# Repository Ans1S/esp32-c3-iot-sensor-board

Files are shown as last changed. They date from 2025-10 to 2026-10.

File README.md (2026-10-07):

<div align="center">

# W-Charger

### Give a discarded vape battery a second life — as a useful, low-power sensor

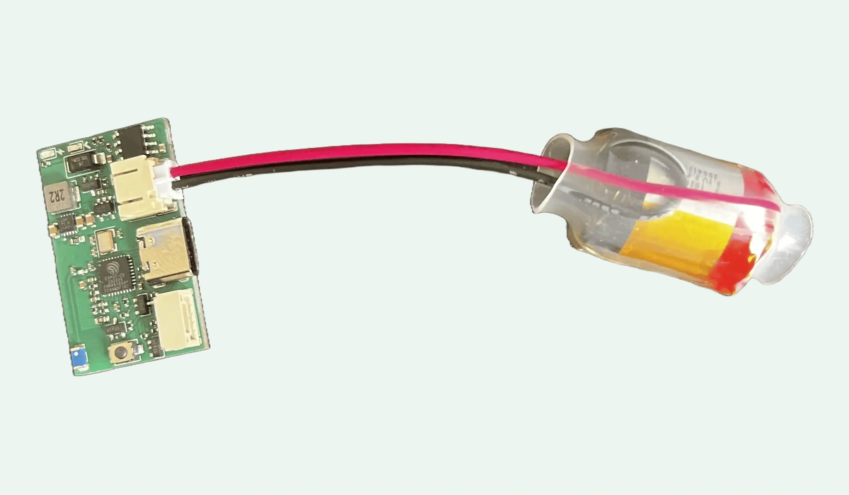
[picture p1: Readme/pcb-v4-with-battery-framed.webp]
W-Charger PCB V4 powered by a carefully recovered vape battery


<br>






**[Why it matters](#1--why-it-matters)** · **[Hardware](#2--hardware-built-for-a-second-life)** · **[Software](#3--software-that-removes-the-friction)**

</div>

Disposable vapes are designed for a very short life. The rechargeable lithium
cell inside them often is not. W-Charger turns suitable recovered cells into
the power source for compact wireless sensor nodes — then makes the whole
network easy to see, configure and update from one station.

| ♻️ Give energy another job | 🔋 Make every milliamp count | 📡 See every sensor in one place | 📦 Update without collecting devices |
|---|---|---|---|
| Reuse a carefully recovered cell instead of wasting its remaining potential. | Deep sleep and switchable hardware are designed for even small cells. | A friendly local dashboard shows live values and history. | Signed OTA updates travel from the station to sleeping sensor nodes. |

## 1 — Why it matters

### A battery should not become waste with the package around it

Many disposable vapes end up in household bins or as litter. That throws away
valuable materials, creates a fire risk in waste handling, and can release
harmful substances when a damaged cell reaches the environment. At the same
time, the product enclosure gives its rechargeable cell no practical second
life for the user.

W-Charger starts with a simple idea: **if a safe, undamaged cell can still store
energy, use that energy for something worthwhile.** A sensor node is a good
match. It needs little power, can spend most of its time asleep, and can turn a
cell that once powered a short-lived product into months of useful
measurements, depending on the cell, sensor and reporting interval.

<p align="center">
  A disposable vape becomes a recovered battery, then a low-power sensor and finally useful measurements in the W-Charger station
</p>

This project is not only a charger or a PCB. It is the complete path from a
recovered energy source to an approachable sensor network:

- a purpose-built ESP32-C3 sensor board;
- support for BME280, BME680, LSM6DSOX, TMP117 and MAX30102 sensors;
- a central ESP32-S3 station that discovers nodes automatically;
- a responsive local web interface for readings, history and configuration;
- signed over-the-air firmware updates for the sensor fleet.

> [!CAUTION]
> **Recovering lithium cells is not a beginner task.** Never use a swollen,
> punctured, corroded, hot, leaking or deeply discharged cell. Prevent short
> circuits, verify polarity and voltage before connection, and take questionable
> cells to an approved battery recycler. W-Charger is an experimental prototype,
> not a certified consumer product.

## 2 — Hardware built for a second life

### Two generations, one goal

PCB V3 proved the concept. PCB V4 is the current design and pushes the same idea
further: use more of the cell's available energy and waste less of it while the
sensor sleeps.

<table>
  <tr>
    <th align="center">PCB V3 · proven prototype</th>
    <th align="center">PCB V4 · current design</th>
  </tr>
  <tr>
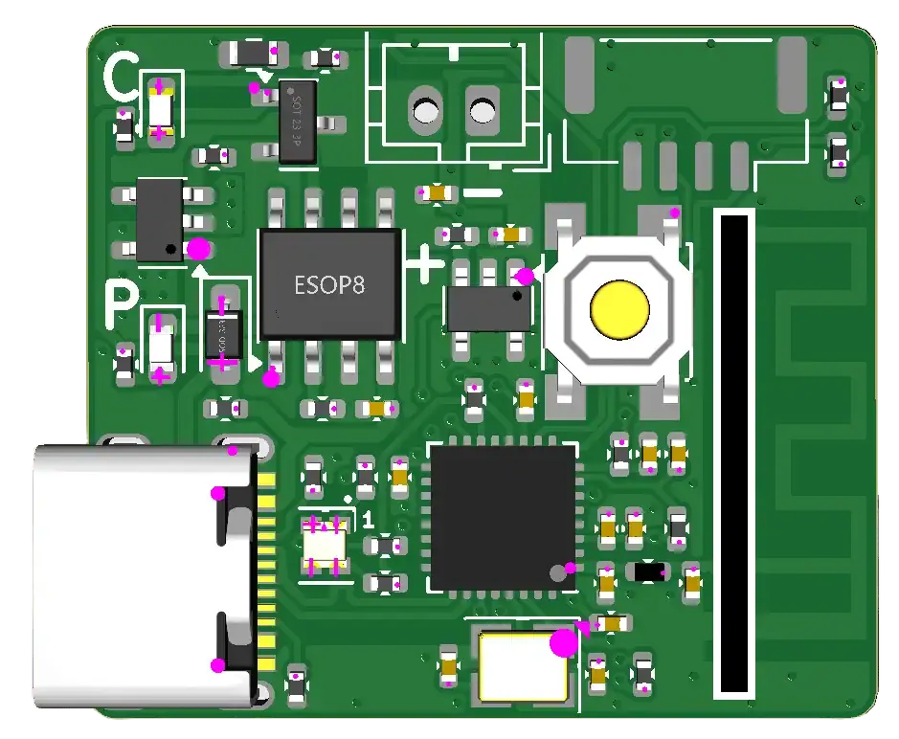
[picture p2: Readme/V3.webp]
Front render of W-Charger PCB V3
    <td align="center"></td>
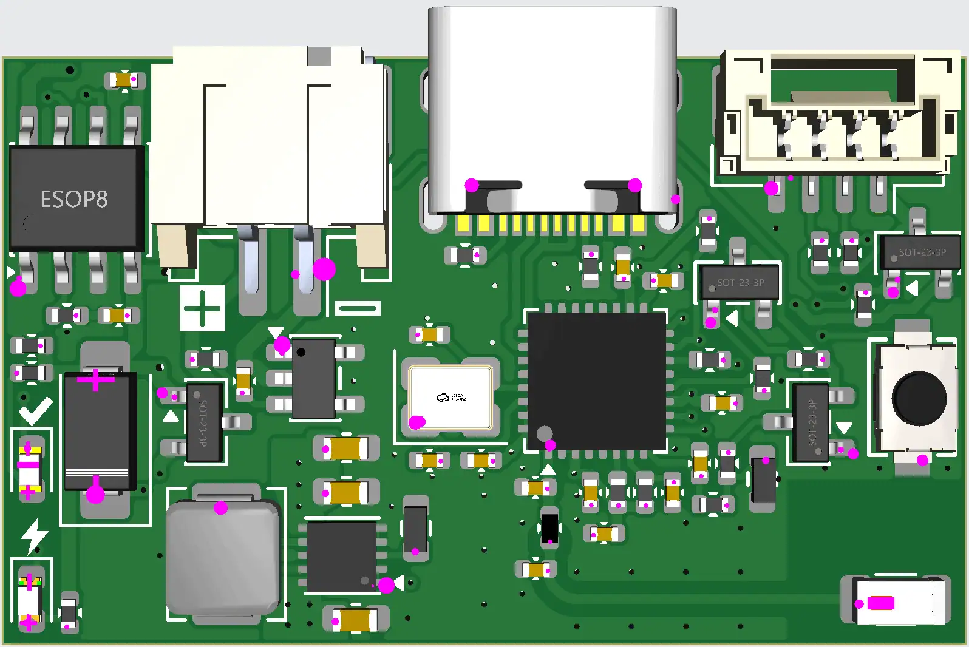
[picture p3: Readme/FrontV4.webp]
Front render of W-Charger PCB V4
    <td align="center"></td>
  </tr>
  <tr>
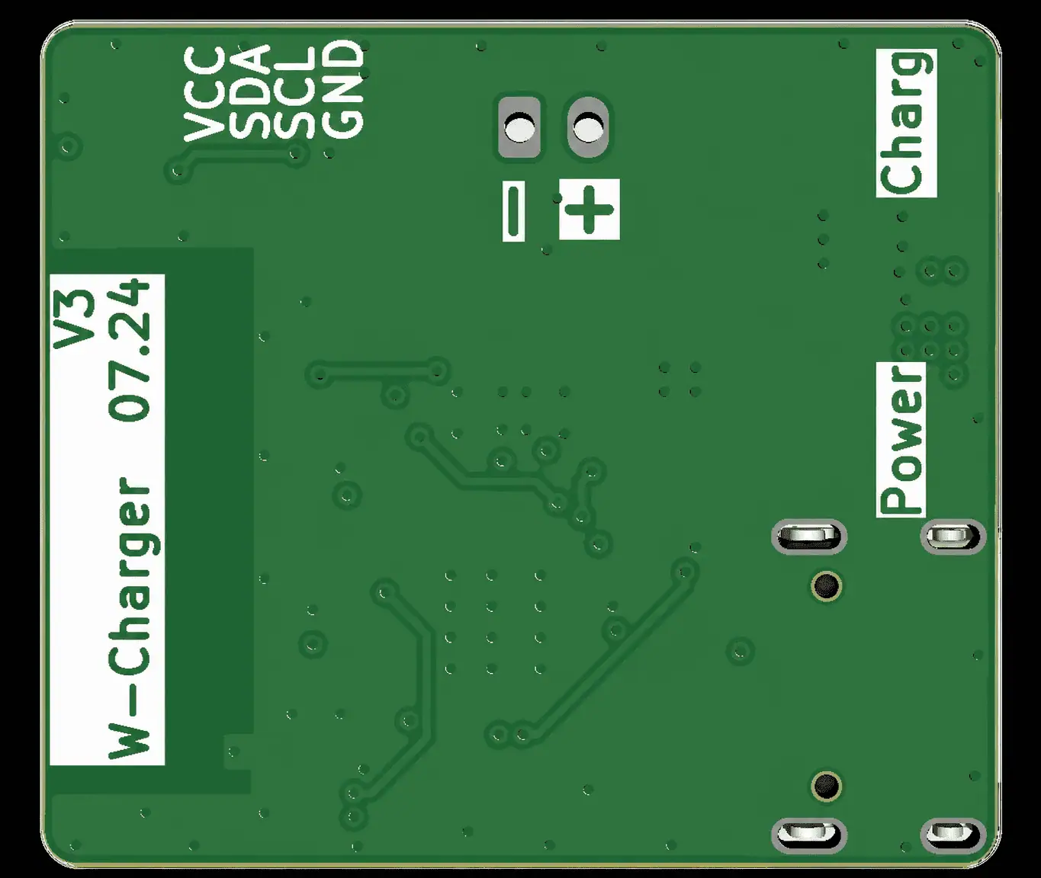
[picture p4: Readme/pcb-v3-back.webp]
Back render of W-Charger PCB V3
    <td align="center"></td>
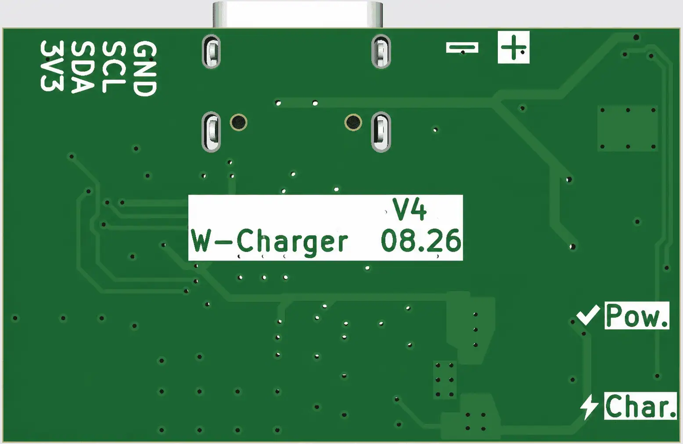
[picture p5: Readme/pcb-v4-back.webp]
Back render of W-Charger PCB V4
    <td align="center"></td>
  </tr>
</table>

| What changed | PCB V3 | **PCB V4** |
|---|---|---|
| Power delivery | Simple, dependable 3.3 V regulator | Buck-boost supply designed to use more of the cell's discharge range |
| Sleeping efficiently | The sensor rail can be switched | Sensor rail, I²C pull-ups and battery measurement are powered only when needed |
| Battery connection | Earlier upright connector layout | Low-profile side-entry connector |
| Charging feedback | Functional charging circuit | Revised layout with clearer power and charge indicators |
| Best fit | Existing builds and experiments | New builds and lowest-power development |

Both versions run the same sensor firmware, with a build profile that selects
the correct power behavior for the board. V4 remains a prototype and still
requires complete electrical, thermal, RF and long-term runtime validation.

### Connect the measurement your project needs

The board exposes one straightforward four-pin I²C connection. Today the
firmware supports:

| Sensor | What it adds | Typical behavior |
|---|---|---|
| **BME280** | Temperature, humidity and pressure | Wake, measure, report, sleep |
| **BME680** | Temperature, humidity, pressure, gas resistance and indoor-air-quality estimation | Ultra-low-power background learning with configurable reports |
| **LSM6DSOX** | Acceleration, angular rate and motion summaries | Continuous acquisition for motion projects |
| **No external sensor** | Battery-powered ESP32-C3 experimentation | A clean base for future extensions |

The hardware is intentionally open-ended: one compact node, different sensor
boards, and a growing firmware library instead of a separate product for every
measurement.

<table>
  <tr>
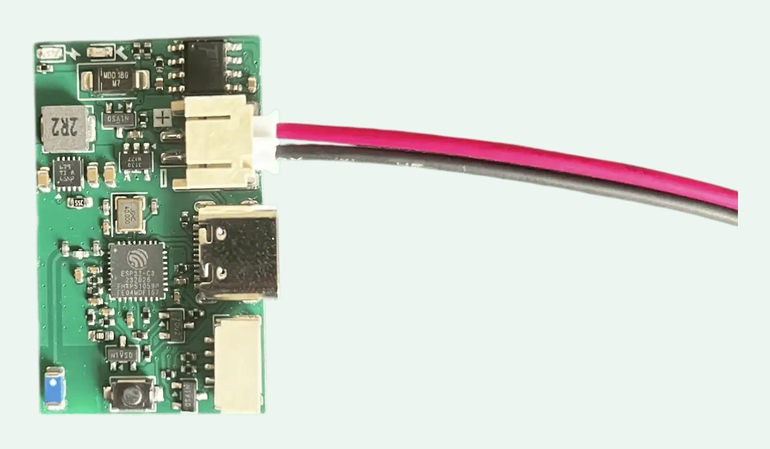
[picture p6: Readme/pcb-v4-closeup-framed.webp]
Assembled W-Charger PCB V4, cropped to remove empty margins
    <td width="50%" align="center" valign="top"><br><strong>Assembled PCB V4</strong></td>
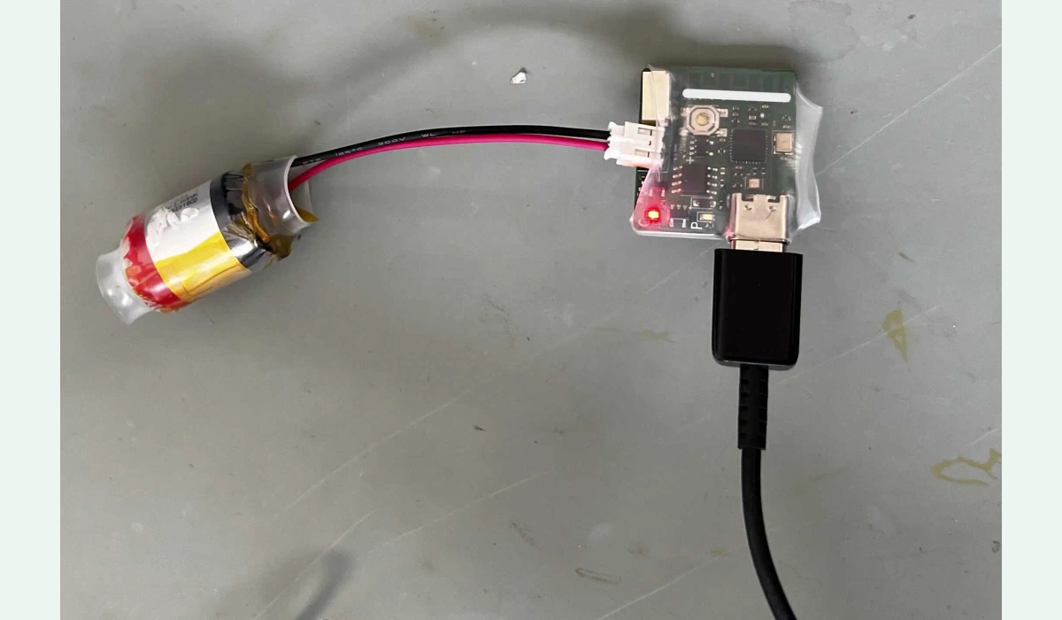
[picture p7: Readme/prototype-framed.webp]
W-Charger prototype with a recovered cell and USB cable
    <td width="50%" align="center" valign="top"><br><strong>Prototype with recovered cell</strong></td>
  </tr>
</table>

KiCad sources, BOMs and manufacturing files are available in [`PCB/`](PCB/).
The current V4 production package is under
[`PCB/Version 4/ESP32-C3-V4/production/`](PCB/Version%204/ESP32-C3-V4/production/).

## 3 — Software that removes the friction

### One station instead of a pile of USB cables

The station is the calm center of the system. Sensor nodes discover it over
ESP-NOW, send their readings, and return to their energy-saving routine. You
open one local website to see the whole network.

<p align="center">
  Several sensor nodes connect through ESP-NOW to one W-Charger station and its local web app
</p>

There is no receiver address or Wi-Fi channel to hard-code into every sensor.
The station can find new nodes, name them, select their attached sensor,
configure their measurement interval, keep local history, and optionally map
values to ThingSpeak.

### A dashboard made for people, not only developers

<p align="center">
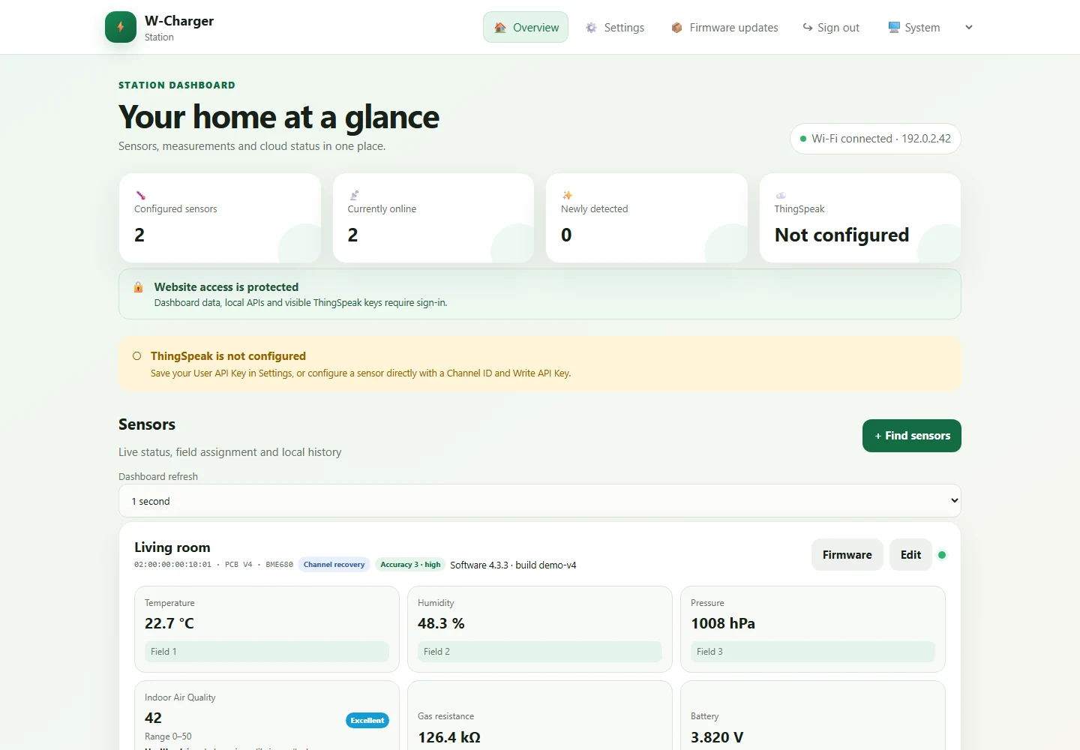
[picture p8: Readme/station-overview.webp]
Anonymized W-Charger station overview with two demo sensors and live values
  
  <br><sub>Live status, battery level, air quality, radio strength and local history. All names, addresses and identifiers shown are synthetic demo data.</sub>
</p>

Every sensor card adapts to the connected hardware. BME280 cards show
temperature, humidity, pressure and battery; BME680 adds indoor air quality and
gas resistance. Motion nodes expose XYZ acceleration and angular rate, TMP117
shows precise temperature, and MAX30102 shows an optical waveform and estimated
pulse during a manual recording. Measurement intervals and cloud mappings stay configurable
per sensor, while useful defaults keep setup short.

### Settings stay visible and understandable

<p align="center">
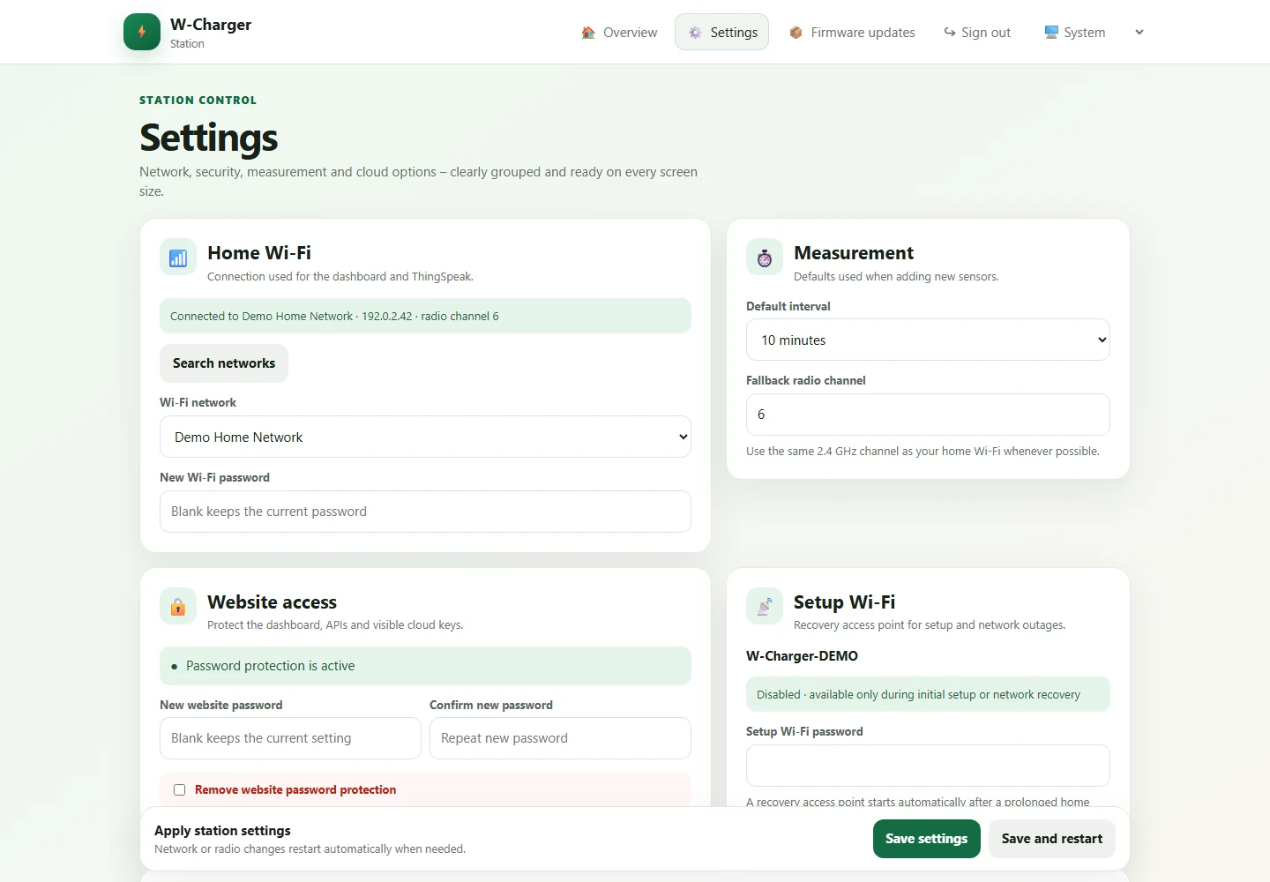
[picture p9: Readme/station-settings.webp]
Anonymized W-Charger settings page for Wi-Fi, measurement interval and protected website access
  
  <br><sub>Network, energy, access and cloud options are grouped in one responsive interface. Credentials are blank in this generated demo.</sub>
</p>

The dashboard works locally. ThingSpeak export is optional. Wi-Fi passwords,
website credentials and API keys are entered in the browser and stored on the
station — they are not compiled into the source code.

### OTA updates: improve sensors where they are

Once a sensor has its OTA-capable base firmware, routine updates no longer mean
finding every node, opening its enclosure and connecting it to a computer.
Upload a signed firmware package to the station, choose a sensor, and the
transfer continues automatically whenever that sleeping node checks in.

<p align="center">
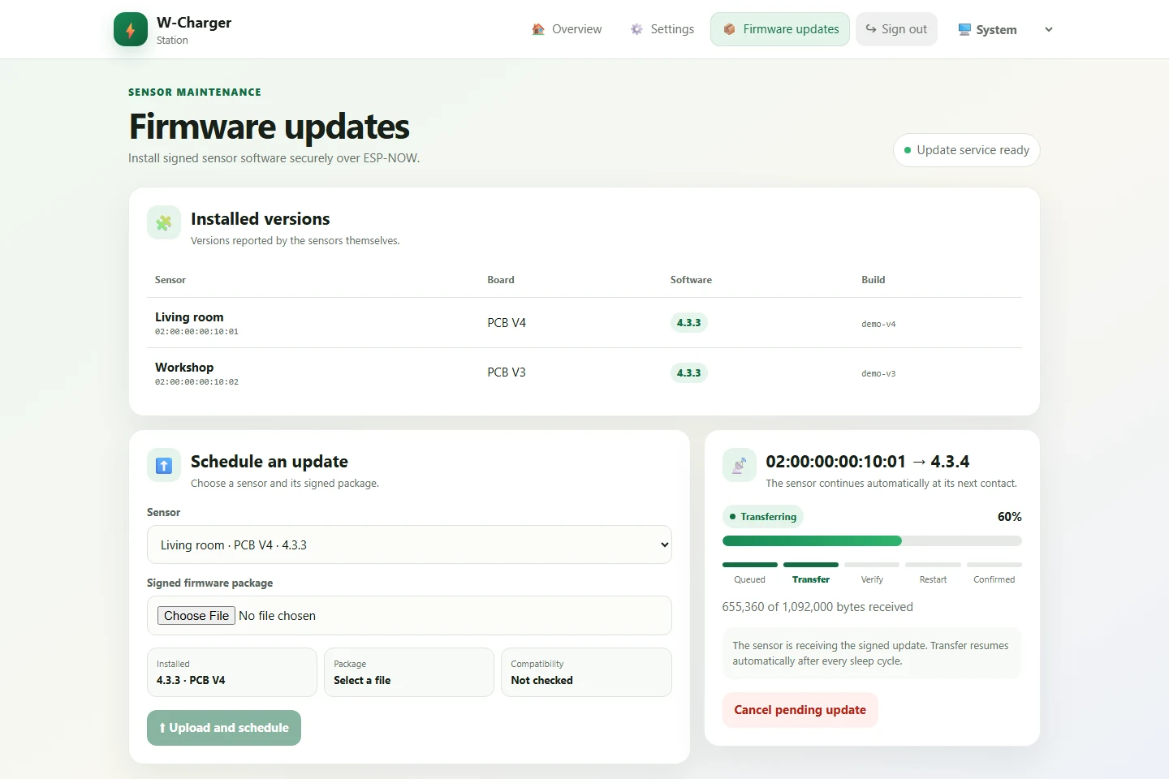
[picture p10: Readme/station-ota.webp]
Anonymized W-Charger firmware update page showing installed versions and an OTA transfer in progress
  
  <br><sub>The station checks board compatibility, tracks transfer progress and waits for the updated sensor to confirm a successful boot. Device addresses and build names are reserved demo values.</sub>
</p>

Interrupted transfers resume, low batteries can postpone an update, and the
previous image can be restored when a trial boot does not succeed. This turns a
collection of scattered devices into a sensor fleet that can keep improving.

### Firmware 4.3.4

The current release improves sensor recovery, BME680 state persistence,
MAX30102 signal handling, durable configuration/storage and station usability.
Saved recordings load as complete snapshots and stay readable during polling;
yellow setup notices disappear after five seconds. BME power-saving and the
PCB V4 daily battery-protection policy remain active.

- [Complete changes since firmware 4.3.1 and PR #30](Firmware/CHANGELOG.md)
- [PCB V3/V4 OTA packages and station application](Firmware/releases/README.md)
- [Publication/privacy review](Firmware/PUBLICATION_REVIEW.md)

### From clone to first measurement

You need VS Code with PlatformIO (or PlatformIO Core), Python, Git, a USB data
cable and one connected board at a time.

```bash
python Firmware/upload.py
```

The upload helper offers the station, PCB V3 sensor and PCB V4 sensor as clear
choices and uses the matching build automatically. Direct commands are also
available:

```bash
python Firmware/upload.py station
python Firmware/upload.py sensor-v4
# For an existing V3 board:
python Firmware/upload.py sensor-v3
```

Then:

1. Flash the ESP32-S3 station and join its `W-Charger-XXXXXX` setup network.
2. Follow the browser wizard to choose Wi-Fi, a sensible default interval and an optional website password.
3. Flash and power a matching sensor board.
4. Open **Find sensors**, give the node a name, choose its attached sensor and save.
5. From then on, use the station dashboard for readings, configuration and signed sensor updates.

> [!IMPORTANT]
> Normal station USB updates preserve saved settings, pairing and archives.
> Only the explicit `station_s3_factory_reset` upload erases the complete flash.
> Older recording layouts require the documented one-time USB migration. Disconnect a recovered battery before the first USB upload and
> confirm whether the connected sensor PCB is V3 or V4.

<details>
<summary><strong>What the software already handles</strong></summary>

- Automatic station and Wi-Fi-channel discovery across all 13 ESP-NOW channels.
- Board-specific power control for PCB V3 and V4 from one sensor codebase.
- Energy-saving deep sleep for environmental sensors.
- BME680 operation with Bosch BSEC2 in ultra-low-power mode.
- Rolling local history and CSV export.
- Optional ThingSpeak channel management and field mapping.
- Responsive light, dark and system themes.
- Signed, resumable ESP-NOW OTA with compatibility checks and boot confirmation.

</details>

<details>
<summary><strong>Repository map and technical documentation</strong></summary>

```text
.
├── Firmware/
│   ├── station/        # ESP32-S3 station and local web app
│   ├── sensor/         # ESP32-C3 firmware for PCB V3 and V4
│   └── shared/         # Shared protocol and OTA components
├── PCB/
│   ├── Version 1–3/    # Earlier hardware revisions
│   └── Version 4/      # Current KiCad and production files
└── Readme/             # Documentation graphics and reproducible UI images
```

- [Firmware overview](Firmware/README.md)
- [Station behavior and security model](Firmware/station/README.md)
- [Sensor behavior and hardware profiles](Firmware/sensor/README.md)
- [OTA setup, signing and recovery](Firmware/OTA.md)
- [Power-management design](Firmware/POWER_MANAGEMENT.md)
- [System architecture](Firmware/ARCHITECTURE.md)
- [Hardware test plan](Firmware/HARDWARE_TESTPLAN.md)
- [LSM6DSOX motion guide](Firmware/LSM6DSOX.md)
- [Precision sensor operation and recordings](Firmware/PRECISION_SENSORS.md)
- [Regression tests](Firmware/tests/README.md)

The screenshots in this README are generated from the real embedded pages with
deterministic, anonymized fixtures. Rebuild them with
`node Readme/generate-ui-screenshots.cjs`; set `CODEX_NODE_MODULES` if
Playwright and Sharp are installed outside the default development runtime.

</details>

### Security, privacy and project status

The dashboard is intended for a trusted home network. Website access can be
password protected, but the local UI uses HTTP; ThingSpeak requests use HTTPS.
ESP-NOW packets currently include versioning, length checks and CRC32, but not
per-device cryptographic authentication. Treat the system as a prototype, not
as a security boundary.

Before publishing, run `python Firmware/tools/check_publication.py` and enable
`git config core.hooksPath .githooks`. The hooks inspect staged/pushed blobs,
including firmware and ZIP contents, without printing detected secret values.
Local signing keys, device data and agent instructions stay ignored. The
[publication review](Firmware/PUBLICATION_REVIEW.md) distinguishes the cleaned
current tree from historical exposures already present in older commits.

Current firmware targets are `station_s3`, `sensor_pcb_v3` and
`sensor_pcb_v4`. Project-owned firmware and hardware sources are released under
the [MIT License](LICENSE). The optional BME680 path downloads Bosch BSEC2
during the build and remains subject to Bosch's separate license.

<div align="center">

**A short-lived product can still become a long-lived tool.**

</div>

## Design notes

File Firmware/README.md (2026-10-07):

# W-Charger Firmware

This directory contains the only maintained firmware in this repository. The
station and both sensor-board revisions share the version 5 ESP-NOW protocol;
retired experiments are intentionally excluded from Git.

```text
Firmware/
â”œâ”€â”€ shared/   versioned ESP-NOW protocol
â”œâ”€â”€ station/  ESP32-S3 home station
â””â”€â”€ sensor/   ESP32-C3 sensor firmware for PCB V3 and V4
```

The station and sensor are independent PlatformIO projects. Flash the station
first, then the sensor target matching PCB V3 or V4. One sensor codebase
supports BME280, BME680, LSM6DSOX, TMP117, MAX30102 and battery-only nodes; the attached
sensor is selected in the station UI rather than compiled into a separate
image. Configure Wi-Fi, reporting intervals, sensor calibration and optional
ThingSpeak integration only through the station UI. Never add credentials to
source files.

For the shortest upload path, run `python Firmware/upload.py` from the
repository root and select the connected board. Pass `station`, `sensor-v3` or
`sensor-v4` directly to make the command non-interactive. Add `--build-only` to
verify a target without writing to a connected device.

- [Station](station/README.md)
- [Sensor](sensor/README.md)
- [Architecture](ARCHITECTURE.md)
- [Hardware test plan](HARDWARE_TESTPLAN.md)

Current firmware: **4.3.4**. Initialize the installation signing key as described
in the OTA guide before the first build. Never replace an existing signing key.

- [Signed OTA updates](OTA.md)
- [Latest local packages](releases/README.md)
- [LSM6DSOX motion acquisition](LSM6DSOX.md)
- [Power management](POWER_MANAGEMENT.md)
- [Regression checks](tests/README.md)
- [Manual recordings and USB migration](RECORDINGS.md)
- [Sensor accuracy review and V4 battery protection](SENSOR_REVIEW.md)
- [Station and sensor V3/V4 reliability review](RELIABILITY_REVIEW.md)

## Live precision sensors

TMP117 and LSM6DSOX take fresh normal measurements at the configured interval
with the external rail off between windows. MAX30102 starts through SW2 only.
SW2 / GPIO9 starts/stops a separate fast recording: 1 s TMP117 values, 200 ms
optical waveform packets, or 50 ms IMU means for five minutes and 100 ms afterward.
Pulse estimates update once per second. Saved recordings load as complete,
stable snapshots; full-session CSV retains the original samples. See [operation, accuracy limits and OTA migration](PRECISION_SENSORS.md).

## Current release and publication checks

Firmware **4.3.4 / 40307** includes bounded sensor reinitialization, durable
settings/history corrections and the updated recording/dashboard behavior.
See [the complete change inventory](CHANGELOG.md),
[release artifacts](releases/README.md) and
[publication review](PUBLICATION_REVIEW.md). Build diagnostics use relative
paths; installation keys and device data must stay local. Software tests do not
replace physical accuracy, rail-voltage and sleep-current acceptance.

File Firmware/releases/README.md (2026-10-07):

# Firmware 4.3.4

The current release is **4.3.4**, internal release **40307**, for protocol V5.

| File | Target | Use |
| --- | --- | --- |
| [sensor-v3-4.3.4.ota](sensor-v3-4.3.4.ota) | Sensor PCB V3 | Signed OTA through the station |
| [sensor-v4-4.3.4.ota](sensor-v4-4.3.4.ota) | Sensor PCB V4 | Signed OTA through the station |
| [station-4.3.4.bin](station-4.3.4.bin) | ESP32-S3 station | Application-only USB image at `0x10000` |

The release includes bounded sensor reinitialization, BME680 learning-state
persistence, MAX30102 weak-signal/independent LED control, durable settings and
archive fixes, stable complete saved graphs, timed setup notices and correct
BME280 tiles. Read [the full change inventory](../CHANGELOG.md) for the main
improvements and every additional correction since 4.3.1 and PR #30.

## Installation

Update the station for UI/storage changes and sensor nodes for driver/recovery
changes. To build and upload the station normally, run from the repository root:

```sh
python Firmware/upload.py station
```

Normal station uploads preserve settings, identities and recording archives.
The supplied station BIN contains only the application. It must not be flashed
at `0x0`, uploaded as a sensor OTA package or mistaken for a factory image.
On an existing compatible layout, write it at `0x10000` without erasing flash.
Only the explicit factory-reset environment intentionally erases the device.

Upload the matching V3/V4 `.ota` on the station's **Firmware updates** page.
Existing 4.3.1/4.3.2/4.3.3 installations with this trusted signing identity and
recording layout can use it. Same-version OTA is rejected; rebuilding 4.3.4
with sanitized compiler paths does not change its release integer. Older
layouts still need the [one-time USB migration](../RECORDINGS.md#one-time-usb-migration).
The recording partition layout and low-power policies remain unchanged.

## Integrity and publication

[SHA256SUMS.txt](SHA256SUMS.txt) covers all three files. V3/V4 signatures,
embedded PCB/protocol/version identities and payloads match the final builds
and the existing installation's public key. That private key and the local
public header are never uploaded. Firmware intentionally contains the public
verification key; that is not private key material.

New builds remap personal compiler paths before compilation. The publication
checker inspects firmware bytes, source text and ZIP contents with redacted
findings. Earlier distribution binaries were removed from this current tree
because they carried local build paths; retained local copies are ignored.
Their previously published Git objects are still present in history. See
[the publication review](../PUBLICATION_REVIEW.md) for this limitation.

This directory supplies only the current packages, not flash dumps or factory
images. The unpublished 4.3.2/4.3.3 intermediate packages are superseded by 4.3.4.
Historical 4.3.1 behavior and validation are documented in
[PR #30](https://github.com/Ans1S/esp32-c3-iot-sensor-board/pull/30).

## Validation and licenses

All three PlatformIO targets, 22 production C++ suites, six embedded browser
suites, six cryptographic OTA package tests, two upload tests, three pinned
library-patch checks and publication regressions pass. Eight station script
blocks parse. No hardware was flashed or measured. Accuracy, RF/power-loss,
rollback behavior, rail discharge and current acceptance remain separate work;
see [tests](../tests/README.md) and [the reliability review](../RELIABILITY_REVIEW.md).

BME680 firmware includes Bosch BSEC2 binaries under their separate
[license terms](https://github.com/boschsensortec/Bosch-BSEC2-Library/blob/4f559a6aa450f0ce436e602b42dc384f52128c66/LICENSE.md).
The repository license does not relicense third-party components. Review the
applicable terms before redistributing compiled packages.

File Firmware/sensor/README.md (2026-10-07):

# W-Charger Sensor Firmware

Firmware 4.3.4 supports LSM6DSOX, TMP117 and MAX30102 live acquisition on PCB V3/V4.
See [precision sensor operation and timing](../PRECISION_SENSORS.md).

One shared firmware codebase supports PCB V3 and V4. The only differences are
the build environment and the `hardware_profile`.

```text
pio run -e sensor_pcb_v3 -t upload   # existing test board
pio run -e sensor_pcb_v4 -t upload   # current board
```

No Wi-Fi credentials, station MAC address, radio channel or measurement
interval must be written into the source code. A new sensor scans all 13
ESP-NOW channels for the station. During the initial ten-minute pairing window,
it repeats this complete broadcast scan every ten seconds. This continues until
the sensor is actually added in the dashboard (`provisioned=true`); a station
response alone does not end discovery mode. After it is added, the sensor
stores the station MAC address and channel in NVS and normally starts each
future exchange on that saved channel. After the initial ten-minute window, an
unprovisioned sensor sleeps for five minutes between discovery attempts but
still scans all 13 channels on every attempt. A short randomized radio delay is
used only during discovery so that sensors powered together do not repeatedly
collide.

Firmware changes are identified by the ELF SHA fingerprint. A new image
invalidates the RTC configuration cache but preserves station assignment and
compatible calibration data in NVS. Use an explicit factory reset to clear
pairing. Signed firmware updates can now be uploaded through the station;
see [the OTA guide](../OTA.md) for initial USB installation and recovery.
For each scheduled transmission, the sensor first tries the known
channel twice. A newly paired sensor retains a commissioning recovery guard: if
the saved setup-AP channel stops responding, it scans all 12 other channels in
the same wake. This guarantees recovery when the station joins the configured
home Wi-Fi network and its radio moves to that network's channel. Once a new
channel is found, later stale-channel events test at most three other channels
per scheduled report, with one maximum-power attempt each, and continue from a
retained RTC cursor. This bounds steady-state failure energy without adding a
separate retry wake. A one-time sub-second offset in the first deep-sleep
interval staggers paired nodes without keeping their radios active. Both PCB
targets run the CPU at 80 MHz, the lowest supported maximum frequency while
ESP-NOW keeps the 80 MHz APB clock available.

The operating modes are intentionally mutually exclusive. Energy-saving mode
requires all three persisted facts: `provisioned=true`, a valid station MAC and
a valid saved channel. In that mode the sensor uses its configured measurement
interval, addresses only the station and starts on the saved channel. If any
part of the assignment is absent, or the station returns `provisioned=false`
after deletion, the sensor clears the station identity and enters discovery
mode with broadcast traffic and complete channel scans.

| Scenario | Selected mode | Radio and wake behaviour |
|---|---|---|
| Fresh flash, erased NVS or factory reset | Discovery | All 13 channels; 10-second then 5-minute sleep |
| Deleted by the station and deletion response received | Discovery | Station identity cleared; all-channel broadcast resumes |
| Incomplete or invalid persisted assignment | Discovery | Safe fallback; energy-saving mode is rejected |
| Fully provisioned BME280 or no environmental sensor | Energy saving | Configured interval; saved-channel unicast only while communication succeeds |
| Fully provisioned BME680 | Energy saving | Five-minute BSEC ULP wake; radio only at the configured report interval |
| Saved station channel no longer responds | Recovery | Bounded recovery, except the protected setup-AP transition |

The sensor type is no longer compiled into a separate firmware image. When a
sensor is added or edited on the station, select **Automatic**, **BME280**,
**BME680**, **LSM6DSOX** or **No environmental sensor**. The selection and BME680 temperature
correction are transferred with the next ESP-NOW response. Automatic mode
checks the Bosch chip IDs at `0x76` and `0x77`, then the LSM6DSOX
at `0x6A` and `0x6B`.

A normal BME280 cycle performs only these steps:

1. On V4, settle and read the battery divider before enabling the sensor.
   Below 2.8 V (or on an invalid ADC reading), send only battery status and
   deep-sleep for 24 hours. Resume at 2.95 V. V3 retains overlapping ADC settling.
2. Read the BME280 with checked I2C transfers, one forced x1 T/P/H conversion
   and a coherent data burst. Bosch/automatic startup uses 100 kHz I2C.
3. Send a validated telemetry packet over ESP-NOW.
4. Wait briefly for the station's configuration response.
5. Write the new configuration to NVS only when its revision has changed.
6. Safely disable the sensor and ADC paths and enter deep sleep.

The V4 policy also applies before discovery/BME680 maintenance and checks live
sessions every ten seconds. The station displays an explicit battery-protection
state. See [sensor and low-voltage review](../SENSOR_REVIEW.md) for register
checks, recovery behavior, limitations and the hardware acceptance procedure.

The BME280 configuration deliberately follows Bosch's energy-efficient weather
monitoring profile: forced mode, 1x oversampling for temperature, pressure and
humidity, and no IIR filter. Higher oversampling adds little practical value to
slow-changing indoor measurements but increases measurement and active time.
The station therefore wakes this sensor type only at the selected reporting
interval.

## Hardware profiles

| Function | PCB V3 | PCB V4 |
|---|---:|---:|
| ADC | GPIO3 | GPIO3 |
| ADC enable | always active | GPIO6, active high |
| Sensor power | GPIO10, active high | GPIO10, PMOS active low |
| I2C SDA / SCL | GPIO5 / GPIO4 | GPIO5 / GPIO4 |
| Battery scaling | field-validated software factor 1.67 | 100 kOhm / 150 kOhm, factor 1.667 |

The station can logically restore a sensor to factory settings on its next
contact. The web interface allows integer-second intervals from one second to 24 hours,
covering both short tests and energy-efficient long-term operation.

## BME680 and indoor air quality

The BME680 runs Bosch's BSEC2 algorithm and uses **Static IAQ** for a stationary
indoor device. An index calculated independently from gas resistance would not
be equivalent: humidity compensation, sensor ageing, drift and the adaptive
baseline are part of the algorithm. The index ranges from 0 (clean air) to 500
(heavily polluted), and the associated accuracy from 0 to 3 appears directly
in the dashboard. While accuracy is 0, the dashboard displays "calibrating"
and the station does not send IAQ to ThingSpeak. Temperature, humidity,
pressure and gas resistance remain available.

Commissioning and long-term operation deliberately use the same routine:

- `BSEC_SAMPLE_RATE_ULP` is the only mode used from the first start throughout
  the device's lifetime, with exactly one internal BME680 measurement every
  five minutes;
- while the BME680 completes its forced TPH/heater conversion, the ESP32-C3
  uses timer Light-sleep with the switched sensor rail latched at its active
  level; a failed Light-sleep setup falls back to the original timed delay;
- there is no switch between LP and ULP, avoiding a jump in the learned BSEC
  baseline caused by an operating-mode change;
- sensor power is off and the ESP32-C3 is in deep sleep between measurements;
- radio transmission and ThingSpeak strictly follow the configured reporting
  interval, such as 10, 30 or 60 minutes;
- the logical reporting clock includes both deep-sleep and awake time, so a
  report is not delayed by another five-minute BME680 cycle;
- BSEC state and logical time remain in RTC RAM; a flash checkpoint is written
  when accuracy improves and then no more than once every six hours;
- after a battery replacement, the latest flash state is restored instead of
  losing the adaptive baseline completely.

The firmware loads only Bosch's ULP configuration blob intended for a 3.3 V
sensor supply. The direct Bosch sensor API remains an availability fallback for
temperature, humidity, pressure and raw gas resistance. It intentionally does
**not** generate a substitute IAQ value: only a Static IAQ value actually
provided by BSEC is marked or uploaded as IAQ.

The I2C sensor power rail is **fully switched off on PCB V3 and V4**. The BME680
itself retains no state while unpowered. It is therefore reinitialized after
every wake-up, while the previously serialized BSEC learning state and a
continuous logical time are saved before shutdown and restored on the next
start. This follows Bosch's intended `getState()`/`setState()` flow for complete
system shutdowns.

Initial learning remains active while BSEC Accuracy is 0 and ends permanently
after Accuracy first reaches 1. Its duration depends on the observed air
conditions and is therefore not represented by a fixed countdown. BSEC
continues learning the gas/IAQ path in normal operation and can improve through
Accuracy 2 to 3. There is no separate fast-start mode with increased heater or
radio load.

When BME680 is selected explicitly, the reporting interval must be five minutes
or a multiple of five minutes. The default temperature offset of `0.466 degC`
comes from Bosch's ULP example and can be adjusted on the station for each
installation. It should be changed only after comparison in an enclosure that
has reached thermal equilibrium.

The implementation is based on Bosch's official
[BME68x Sensor API](https://github.com/boschsensortec/BME68x_SensorAPI),
[BME68x Arduino library](https://github.com/boschsensortec/Bosch-BME68x-Library)
and [BSEC2](https://github.com/boschsensortec/Bosch-BSEC2-Library). The BME680
limits, IAQ scale and ULP power figures are documented in the
[BME680 data sheet](https://www.bosch-sensortec.com/media/boschsensortec/downloads/datasheets/bst-bme680-ds001.pdf).
BSEC2 contains a proprietary binary library; use and redistribution are also
subject to the [Bosch BSEC license](https://github.com/boschsensortec/Bosch-BSEC2-Library/blob/master/LICENSE.md).

During a build, the pinned BSEC2 2.1.5 source is automatically adjusted with a
small timing patch. In forced mode, BSEC2 initially starts only the measurement;
the patch waits for the configured temperature/pressure/humidity and heater
duration plus a conservative margin in Light-sleep, then retries `NO_NEW_DATA`
inside a 500-ms fetch budget propagated into the I2C and wait callbacks. One
in-flight I2C transaction may finish after a deadline (20-ms bus timeout).
Initialization, recovery and acquisition share a cooperative six-second budget;
the outer BSEC output wait also retains its five-second limit. Only fresh BSEC
output is accepted. A current future ULP deadline controls sleep, rounded up to
whole seconds. An expired or unavailable schedule falls back to the normal
cadence, avoiding repeated one-second error wakes. This is required because this design removes sensor power
after every cycle. The downloaded Bosch library itself is not copied into the
repository.

If a cycle nevertheless provides only a direct Bosch raw measurement, the last
genuine BSEC IAQ value remains visible on the station and is marked as stale.
That old value is neither added as a new history point nor uploaded to
ThingSpeak. The next scheduled BSEC cycle tries again to produce a fresh IAQ
value.

The station displays an initial learning notice only until Accuracy first
reaches 1. Afterwards a permanent compact Accuracy 0-to-3 status remains in the
normal sensor header. Measurement, radio and cloud operation use the same ULP
routine from the beginning.

## Discovery and re-adding sensors

An unconfigured sensor, or one deleted from the station, announces itself every
ten seconds for ten minutes. To avoid operating the sensor heater and ADC
unnecessarily, its measurement snapshot is refreshed only every five minutes.
After ten minutes, it enters deep sleep for five minutes between discovery
attempts. When it is added successfully, the selected BME680 starts with a
fresh learning state directly in ULP mode. The sensor stores its provisioning
status persistently in NVS. The station already keeps it in the configured list
during radio confirmation, so delayed pairing packets from before confirmation
cannot mark it as a new device again.

## Extending the drivers

`environmental_sensor` is only the shared facade. Measurements use the neutral
`EnvironmentalReading` type, while BME280, BME680 and BSEC persistence each
have separate header and CPP files. A future I2C sensor therefore needs a new
driver, a new value in `EnvironmentalSensorType` and an entry in `beginType()`;
radio, ADC, deep sleep and configuration storage remain unchanged.

## Calibrating battery voltage

`analogReadMilliVolts()` already uses the ESP32-C3 ADC calibration data. A
multimeter reference value can additionally be entered for each sensor. The
station uses it to calculate a one-point gain factor that corrects external
voltage-divider tolerance and the remaining measurement error:

`new factor = previous factor x reference voltage / latest measurement`

The permitted range of 0.7 to 1.3 prevents accidental extreme values. The
calibration corrects gain under the reasonable assumption of a zero point at
0 V; a true two-point characteristic would require two precise reference
voltages. The ADC and voltage-divider paths remain enabled only for a due
report. On V4, the required settling time overlaps the environmental conversion
where possible, and intermediate BME680 maintenance wakes leave the divider
off.

Release builds compile sensor serial logging out and do not initialize UART.
For hardware diagnosis, add `-DSENSOR_DIAGNOSTIC_LOGGING=1` to the desired
sensor environment's `build_flags`; remove it again for battery-life testing.

## Performance changes and verification

See [power management](../POWER_MANAGEMENT.md) for default operating modes,
energy tradeoffs and validation limits. Reproducible host and browser checks
are in [tests/README.md](../tests/README.md); physical acceptance checks are in
[HARDWARE_TESTPLAN.md](../HARDWARE_TESTPLAN.md). Current package information is
in [releases](../releases/README.md).

## Live precision sensors

TMP117 and LSM6DSOX take normal measurements at the configured interval,
such as 1 s or 10 s, with the rail off between fresh acquisition windows.
SW2 / GPIO9 starts a separate recording: 1 s TMP117 results, 200 ms MAX30102
waveform packets, or 50 ms LSM6DSOX means for five minutes followed by 100 ms
means. Pulse estimates update every second. Stopping a recording restores
the normal interval and starts durable replay. See
[operation, accuracy limits and OTA migration](../PRECISION_SENSORS.md).

## Current release and publication checks

Firmware **4.3.4 / 40307** includes bounded sensor reinitialization, durable
settings/history corrections and the updated recording/dashboard behavior.
See [the complete change inventory](../CHANGELOG.md),
[release artifacts](../releases/README.md) and
[publication review](../PUBLICATION_REVIEW.md). Build diagnostics use relative
paths; installation keys and device data must stay local. Software tests do not
replace physical accuracy, rail-voltage and sleep-current acceptance.

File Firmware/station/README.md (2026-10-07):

# W-Charger Station Firmware

Firmware 4.3.4 supports LSM6DSOX, TMP117 and MAX30102 live acquisition on PCB V3/V4.
See [precision sensor operation and timing](../PRECISION_SENSORS.md).

The overview security/cloud configuration notices disappear after five seconds
and stay dismissed across status polling until the condition changes. Password
and cloud state remain available in Settings and the overview status summary.
Upload/connection errors, storage failures and active battery protection remain
visible. Pending sensor changes show initialization feedback without reusing
old sensor errors or values. BME280 cards show temperature, humidity, pressure
and battery; IAQ and gas resistance are shown only for BME680.

The station runs on the existing Seeed XIAO ESP32-S3. It keeps Wi-Fi and
ESP-NOW active at the same time, so the web interface remains available and
sensors are not locked out while a cloud upload is in progress.

## First start

1. Run `pio run -e station_s3 -t upload`. Normal uploads preserve saved settings,
   sensor names and local archives. For an intentional clean installation only,
   `pio run -e station_s3_factory_reset -t upload` erases the complete flash.
2. Connect to the `W-Charger-XXXXXX` Wi-Fi network. The initial Wi-Fi password
   is `W-Charger-Setup`.
3. The captive portal normally opens automatically. If it does not, open
   `http://192.168.4.1/`. No login is required during the unconfigured first
   start.
4. Follow the setup wizard to configure the measurement interval, optional
   ThingSpeak integration, sensors and home Wi-Fi. An optional but recommended
   website password can be set at the end.
5. Confirm the summary. The station saves the configuration and restarts.

A serial monitor is not required for setup. The setup Wi-Fi remains active
until the first successful connection to the home network and then switches
off automatically. It starts again only after a fresh installation or factory
reset. On the home network, the station is available at
`http://w-charger.local/` when the client supports mDNS. Depending on the
router, `http://w-charger/` may work as well.

After setup, the responsive dashboard separates newly discovered sensors from
configured sensors. A new device appears automatically and must be confirmed
once in the three-step wizard. The wizard assigns its name and interval,
selects the attached I2C sensor (automatic, BME280, BME680, LSM6DSOX or disabled),
optionally adjusts BME680 temperature compensation, selects a saved ThingSpeak
channel profile and maps measurements to fields 1 through 8. Only then does
the sensor appear in the regular dashboard with its last contact, readings,
battery voltage, radio quality and switchable local history. Available
intervals start at one second and include a custom value of up to 24 hours.
Intervals below one minute retain 900 history slots in RAM instead of a persistent 24-hour ring.
Each sensor report also carries its actual operating mode. The captive setup
wizard, pending-sensor list and configured dashboard cards display **Setup
mode**, **Energy-saving mode**, **Channel recovery** or **Mode unknown**. The
badge represents the last mode reported by the sensor rather than an estimate
from the station configuration.
The station setup wizard is available only after a fresh installation or
factory reset. During normal operation, changes are made directly under
**Settings**.

## Modules

- `config_store`: persistent station and sensor configuration in NVS, plus
  local measurement history in LittleFS
- `wifi_service`: one-time setup access point, home Wi-Fi reconnect, DNS and
  mDNS
- `web_portal`: dashboard, sensor wizard, channel profiles, Wi-Fi and reset
- `espnow_gateway`: validated and versioned telemetry/configuration protocol
- `sensor_registry`: sensors identified by MAC address instead of hard-coded
  IDs
- `thingspeak_service`: HTTPS upload, account management and automatic creation
  of private channels

The ESP-NOW gateway builds its configuration response entirely from RAM and
sends it before writing telemetry, history or a newly discovered sensor entry
to flash. A separate low-priority task performs those writes after the send
callback. This keeps filesystem latency out of the battery sensor's response
window; if the persistence queue is unexpectedly full, the station performs a
synchronous fallback only after the response transmission has completed.

The station also selects each sensor's normal transmit-power request from its
received RSSI using hysteresis. PCB V4 starts at 11 dBm when the first link has
adequate margin and can step down to 8.5 dBm after eight strong reports; PCB V3
does not go below 11 dBm. Two weak reports raise power, an RSSI at or below
-82 dBm raises it immediately, and normal requested power is capped at 15 dBm.
The sensor still adds 3 dBm on its second known-channel attempt and uses the
ESP32 API maximum for bounded channel recovery. The current base request is
available as `sensorTxPowerDbm` in `/api/status`.

Up to six ThingSpeak channel profiles can be stored centrally and reused by
multiple sensors. Each profile contains a name, the channel ID and optional
read and write API keys. Selecting a profile gives a sensor its channel ID and
write key without requiring the keys to be entered again. Alternatively, the
sensor wizard can use an existing channel or automatically create a new private
channel with the user API key.

ThingSpeak field mapping is freely configurable for each sensor. Temperature,
humidity, pressure, Static IAQ, gas resistance and battery voltage can each be
assigned to `Field 1` through `Field 8` or set to `Do not upload`. Multiple
sensors can use the same channel and write key while occupying different
fields. The interface prevents duplicate field assignments within one sensor.
An automatically created channel initially maps temperature, humidity,
pressure, IAQ, battery voltage and gas resistance to fields 1 through 6. The
BME680 wizard adopts this mapping by default, but it remains editable before
saving.

For BME680 sensors, the dashboard shows BSEC accuracy from "background
learning" through "high" next to the IAQ value, as well as raw gas resistance
in kOhm. BSEC operates exclusively in its energy-efficient ULP mode from the
first start and measures internally every five minutes. ESP-NOW and ThingSpeak
strictly follow the selected, longer reporting interval. The initial ULP
learning notice remains visible only while Accuracy is 0. It disappears after
Accuracy first reaches 1; the compact accuracy badge then remains visible as
BSEC continues improving to 2 and 3 during normal operation. No fixed-duration
progress bar is shown because the required air-condition changes cannot be
predicted honestly.

New, unconfigured sensors appear automatically in the overview; the additional
add button is now only a shortcut to that section. Configured sensors can be
deleted from the local station. As long as a deleted sensor continues to
transmit, it reappears as a new device on its next contact, as expected.

The editing wizard also provides transparent BME680 commissioning, an explicit
reset of the IAQ learning state and optional battery-voltage calibration using
a multimeter reference. Independently of any open browser, the station stores
a rolling 24-hour history for every sensor. Its windows follow the configured
report interval and each contains the latest received measurement: temperature,
humidity, pressure, IAQ and its accuracy, gas resistance and battery voltage.
A phone or another browser loads the complete data through the local station
API; keeping or reloading a page is not required for collection. The history
survives a normal station restart. A drop-down switches the labelled plot
between every quantity supported by the sensor, with time, value range and unit
shown on the axes. Truly missing measurement windows are not bridged by an
invented connecting line.

The channel ID and read/write API keys can be entered in the captive portal and
later in the station settings. The read key is used only to read private
channels, while the station uses the write key for uploads. The user API key is
required only when W-Charger should create a new ThingSpeak channel itself. API
keys are shown in plain text in the local web interface only on explicit
request and are restored to the fields after a restart. Cloud upload remains
disabled until it is explicitly enabled in the sensor wizard.

When a user API key is stored, the settings page loads ThingSpeak channels
automatically. Channels can be created, renamed, edited with their description,
fields, tags, metadata, visibility and location, cleared or deleted. Direct
channel and feed URLs are displayed. A newly detected sensor can select one of
these channels in the wizard; its channel ID and write key are then copied into
a local sensor profile automatically.

The status panel reports **Connected** only after ThingSpeak confirms a write
with a real entry ID. An incorrect write key, HTTP/TLS error or absence of valid
measurements produces a specific error message instead. The local 24-hour
history is stored exclusively on the station and therefore does not depend on
ThingSpeak or one browser's storage. A complete firmware upload with flash
erasure and a factory reset intentionally delete this history.

## Security model of this release

- Home Wi-Fi and ThingSpeak credentials are stored only in NVS.
- The setup Wi-Fi uses WPA2 with the initial password `W-Charger-Setup`.
- The local web interface can be protected during initial setup or later in
  Settings with a password of at least eight characters. This protects the
  dashboard, configuration, history, Wi-Fi scan, all write operations and all
  ThingSpeak-related APIs.
- The website password is stored as a device-bound SHA-256 hash rather than in
  plain text. Successful logins receive a random HttpOnly session cookie that
  expires after an absolute 30-minute lifetime or at the next station restart.
  Repeated failed attempts trigger a device-wide temporary login block, and
  sign-out requires the authenticated CSRF-protected action.
- At the explicit request of the product design, ThingSpeak API keys remain
  visible in the authenticated web interface. Without an enabled website
  password, any device on the local network can therefore read these keys and
  change settings; the dashboard displays a clear warning.
- ThingSpeak requests use HTTPS with a verified DigiCert root certificate.
- ESP-NOW packets include a magic value, protocol version, fixed lengths and
  CRC32.

CRC32 protects against transmission errors but does not provide cryptographic
authentication. Individual ESP-NOW keys and a physically confirmed pairing
flow are therefore planned as the next hardening step.

The local web interface is still served over HTTP. Password protection prevents
unintended access by other participants on the home network, but it does not
replace transport encryption against active interception on that network.

The 8 MB OTA station layout reserves two 2.25 MiB application slots, a
1.625 MiB measurement filesystem and a separate 1.75 MiB firmware staging
partition. Install this layout once by USB. The **Firmware updates** page
accepts signed sensor packages, queues one node at a time, and displays actual
reported software/build versions and confirmed transfer progress. See
[the OTA guide](../OTA.md) for signing keys, installation and recovery tests.

## Performance changes and verification

See [power management](../POWER_MANAGEMENT.md) for default operating modes,
energy tradeoffs and validation limits. Reproducible host and browser checks
are in [tests/README.md](../tests/README.md); physical acceptance checks are in
[HARDWARE_TESTPLAN.md](../HARDWARE_TESTPLAN.md). Current package information is
in [releases](../releases/README.md).

## Live precision sensors

TMP117 and LSM6DSOX take fresh normal measurements at the configured interval
with the external rail off between windows. MAX30102 starts through SW2 only.
SW2 / GPIO9 starts/stops a separate fast recording: 1 s TMP117 values, 200 ms
optical waveform packets, or 50 ms IMU means for five minutes and 100 ms afterward.
Pulse estimates update once per second. Saved recordings load as complete,
stable snapshots; full-session CSV retains the original samples. See [operation, accuracy limits and OTA migration](../PRECISION_SENSORS.md).

## Remembered sensor identities

Sensor names and optional motion references are also saved by MAC address,
independently of the 19 active pairing slots. Up to 64 identities are remembered.
Removing a node or resetting it into discovery mode retains its last name for
re-pairing on this station. This also works with existing node firmware because
names are stored on the station. Existing paired names are migrated at startup.
A full station factory reset or full-flash erase clears remembered identities;
names erased by an older station upload cannot be recovered from the node.
Normal USB and OTA firmware updates preserve this data and the recording archive.

## Current release and publication checks

Firmware **4.3.4 / 40307** includes bounded sensor reinitialization, durable
settings/history corrections and the updated recording/dashboard behavior.
See [the complete change inventory](../CHANGELOG.md),
[release artifacts](../releases/README.md) and
[publication review](../PUBLICATION_REVIEW.md). Build diagnostics use relative
paths; installation keys and device data must stay local. Software tests do not
replace physical accuracy, rail-voltage and sleep-current acceptance.

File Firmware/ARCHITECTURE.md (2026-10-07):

# Firmware Architecture

## System model

The W-Charger station is the continuously available control point. During
initial setup or network recovery it runs a protected setup access point; after
the first successful home Wi-Fi connection it normally operates as a Wi-Fi
station. ESP-NOW remains active alongside the local web interface and the
optional ThingSpeak uploader. Environmental sensor nodes wake briefly,
measure, exchange one telemetry/configuration pair with the station and return
to deep sleep. LSM6DSOX and TMP117 use fresh acquisition windows at the configured
normal interval and continuous acquisition during SW2 recordings. MAX30102
acquires only during a manually started SW2 session.

```text
PCB V3/V4 sensor
  Measure -> telemetry + applied configuration revision
          -> ESP-NOW -> W-Charger station -> immediate configuration response
                                      -> deferred flash/history + cloud queues
          <- ESP-NOW <- interval, channel, station MAC, sensor/ADC calibration
  Read configuration from RTC cache; write NVS only on change
  -> disable loads -> deep sleep
```

`shared/include/lil_protocol.h` defines telemetry/configuration;
`shared/include/ota_protocol.h` defines signed updates for both projects.
Protocol version 5 packets contain a magic value, protocol version, message
type, payload length, sequence number and CRC32. Unknown, malformed or damaged
packets are discarded. Any incompatible packet-layout change requires a new
protocol version.

## Responsibilities

### Station

- `config_store`: versioned station and sensor data in NVS
- `wifi_service`: setup AP plus station mode, reconnect, captive DNS and mDNS
- `web_portal`: setup wizard, responsive dashboard, sensor provisioning,
  history, channel profiles and account management
- `sensor_registry`: MAC-based device management, configuration revisions and
  a persistent rolling 24-hour history in LittleFS
- `espnow_gateway`: short radio callbacks, packet validation and response-first
  configuration replies followed by deferred persistence
- `thingspeak_service`: a separate FreeRTOS task for blocking HTTPS requests

New sensor MAC addresses are initially registered as unprovisioned devices.
Their telemetry is visible in the dashboard but is never uploaded as normal
cloud data. Only the sensor wizard sets the provisioning state and optionally
enables uploads. A pending provisioning acknowledgement prevents delayed
pairing packets from moving a newly configured sensor back into the discovery
list.

The station stores up to 19 sensors and six reusable ThingSpeak channel
profiles. Each profile contains a channel ID and optional read and write keys.
The profile assignment and field mapping are stored per sensor on the station.
Temperature, humidity, pressure, Static IAQ, gas resistance and battery voltage
can be mapped independently to ThingSpeak fields 1 through 8. Multiple sensors
can therefore share one channel and its credentials while using different
fields. Unsupported, stale or invalid measurements are not uploaded. Uploads
use only the write key; the read key is reserved for private-channel access.

Cloud status does more than inspect the HTTP status. An upload is successful
only when ThingSpeak returns a positive entry ID. ESP-NOW remains active during
cloud requests. When the RAM-only cloud queue is full, the oldest cloud job is
dropped in a controlled way and counted in the dashboard rather than blocking
the radio callback.

Telemetry is registered in RAM before the response is built. The station then
waits only for completion of that response transmission and delegates latest
telemetry, configuration and history writes to a low-priority persistence
task. The 64-entry queue drops its oldest event on overload and exposes a
separate persistence-drop counter. It never performs a synchronous fallback on
the radio task. Storage takes a separate mutex; radio registration performs no
flash operations or history allocation. Slot generations invalidate queued
samples after deletion/reuse. An immediate station power loss can still lose
an acknowledged sample that has not reached flash.

At intervals of at least 60 seconds, the station keeps a 24-hour ring of
40-byte V4 samples in LittleFS. Existing 23-byte V3 environmental samples are
migrated. Reception time determines the bucket independently of flash latency;
raw-fallback IAQ is excluded. Normal restart preserves this history; factory
reset or full flash erase removes it. Subminute intervals use a bounded
900-entry RAM ring and avoid per-report flash persistence; restart clears it.

### Sensor

- `hardware_profile`: only PCB V3/V4 pins, polarities and battery scaling
- `power_controller`: sensor and ADC power paths
- `environmental_sensor`: shared, extensible I2C sensor facade
- `bme280_driver`: BME280 in energy-efficient forced mode
- `bme680_driver`: Bosch BSEC2 Static IAQ with the 3.3 V ULP profile, a
  continuous five-minute algorithm schedule, timer Light-sleep during the
  forced heater/conversion wait, deep sleep between measurements and
  persistent learning state; the BSEC operating mode never changes
- `bsec_state_store`: CRC-protected, wear-conscious IAQ state checkpoints
- `adc_reader`: filtered and calibrated millivolt measurement
- `espnow_transport`: saved channel first, followed by same-cycle channel
  recovery when that channel is stale
- `sensor_config_store`: write NVS only when data actually changes
- `sleep_controller`: defined power-down and timer deep sleep

PCB V3 uses its field-validated battery scaling factor of 1.67. PCB V4 adds a
GPIO6-controlled battery divider and an active-low GPIO10 PMOS sensor rail with
a nominal divider factor of 1.667. Its 100 kOhm ADC series resistor and 100 nF
filter capacitor produce an approximately 16 ms charging time constant with the
divider, so the firmware waits 100 ms after enabling the path before sampling.
That settling period starts before the environmental conversion and is skipped
entirely on BME680 maintenance wakes where no report is due.

Unprovisioned sensors advertise every ten seconds for the first ten minutes and
scan all 13 channels during each discovery wake. Afterwards, they wake every
five minutes but still scan all 13 channels, so commissioning never depends on
the current rotating subset. Discovery alone uses a short random radio delay to
prevent sensors powered together from repeatedly colliding.

Configured sensors try the saved channel twice. A commissioning recovery guard
remains active after a sensor is added: if the setup-AP channel stops
responding, the sensor scans all 12 alternatives in the same wake and stores
the channel returned by the station after it joins the home Wi-Fi network.
After that transition succeeds, stale-channel recovery is limited to three
rotating channels once each per scheduled report. The recovery cursor survives
in RTC RAM, so later reports continue the scan without permanently extending
the active radio window. A completely failed configured exchange does not
create an extra retry wake; the next attempt follows the configured report
interval. A one-time sub-second deep-sleep phase offset staggers sensors that
started together, and both ESP32-C3 PCB targets run at 80 MHz.

A failed unicast send callback skips the application-response timeout because
no station response can follow a failed MAC transmission. Conversely, a
successful unicast MAC acknowledgement without a configuration response proves
that the saved channel is still correct, so it does not trigger an expensive
channel scan. The station requests adaptive base power with conservative RSSI
hysteresis; per-attempt escalation and maximum-power recovery remain unchanged.

The sensor selects energy-saving mode only when NVS contains a complete
assignment (`provisioned`, valid station MAC and valid channel). An erased installation,
local factory reset or `provisioned=false` response clears the station identity
and selects discovery mode. Consequently an incomplete or interrupted setup
cannot accidentally use the configured sleep and unicast path.

Protocol V5 includes the sensor's current operating mode in telemetry:
discovery, energy saving or channel recovery. The station exposes this value in
`/api/status` and renders it in both the captive setup wizard and the normal
dashboard. Unknown is reserved for a stored station entry without a current V5
telemetry packet.

BME680 nodes still wake every five minutes to maintain BSEC ULP timing, but
ESP-NOW and ThingSpeak follow the configured reporting interval. The logical
report clock includes time spent awake as well as deep-sleep time, preventing a
few seconds of processing from postponing a due report by another five-minute
BME680 cycle.

A reset command remains pending on the station until the sensor acknowledges
the corresponding configuration revision during a later contact.

## Persistence and failure behaviour

- Wi-Fi and ThingSpeak credentials are stored in station NVS, never in source
  files.
- Sensor interval, I2C sensor type, temperature offset, battery correction
  factor, station MAC address, radio channel and provisioning state are stored
  in sensor NVS. A validated RTC copy avoids reopening NVS after ordinary deep
  sleep and is invalidated by a new firmware SHA or factory reset.
- Boot count, sequence, report-attempt clock and reset acknowledgement
  are retained in RTC RAM across deep sleep.
- BSEC state and continuous algorithm time remain in RTC RAM. A checkpoint is
  written to NVS when accuracy improves and then no more than every six hours.
- A firmware ELF SHA change invalidates the RTC configuration cache while
  retaining pairing and compatible calibration in NVS. Explicit factory reset
  clears assignment; ordinary firmware updates do not.
- The cloud upload queue exists only in RAM. A station restart can therefore
  discard measurements that were queued but not uploaded.

## Security boundaries of this release

- ThingSpeak uses TLS with certificate verification.
- The setup AP uses WPA2 with the initial password `W-Charger-Setup`; the web
  interface allows it to be changed later.
- State-changing web requests require a random CSRF token.
- The HTTP web interface supports an optional password. A per-device salted
  SHA-256 digest is stored in NVS; a successful login creates a random HttpOnly
  session cookie that expires on station restart. Failed logins are rate
  limited.
- At the explicit product-design request, ThingSpeak API keys are returned in
  plain text in the local authenticated interface. With password protection
  enabled, read-only configuration, status, history and ThingSpeak APIs also
  require authentication. Without a password, local access deliberately
  remains open and the dashboard displays a warning.
- CRC32 detects transmission damage but does not authenticate a sensor.
- Automatic discovery of new sensor MAC addresses remains open for setup.

Before deployment to untrusted users or networks, the design still needs a
time-limited, physically confirmed pairing mode, individual ESP-NOW keys,
replay protection across restarts and HTTPS for local administration. The
optional HTTP login is not transport encryption and does not prevent active
interception on the same network.

## Firmware updates

Signed sensor firmware packages are staged in a dedicated station partition
and pulled over ESP-NOW at the next sensor contact. The transfer writes the
inactive application slot, checkpoints a verified prefix for resume and uses
bootloader rollback until startup and station communication have succeeded.
The Arduino default early OTA acceptance is explicitly deferred. Existing V5
telemetry remains compatible; OTA uses an additional message type.

See [OTA.md](OTA.md) for the complete wire/storage behavior, signing-key
bootstrap, USB partition migration, limits and physical acceptance tests.

## Motion and OTA

`lsm6dsox_driver` configures the I2C accelerometer/gyroscope and consumes its
104 Hz FIFO. Only motion telemetry uses the extended V5 suffix. Environmental
nodes retain the original V5 wire length. See [motion acquisition](LSM6DSOX.md)
for interval summaries, scaling and FIFO limits.

The sensor `ota_client` pulls signed firmware from the station `ota_service`.
The inactive slot receives buffered sector writes with durable resume
checkpoints. A pending boot must establish station contact before rollback is
cancelled. OTA state and partitions are independent of measurement history.
See [OTA](OTA.md) for trust, partition setup, compatibility and recovery, and
[power management](POWER_MANAGEMENT.md) for the bounded overhead and sleep paths.

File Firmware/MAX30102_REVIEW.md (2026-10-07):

# MAX30102 missing readings and interrupted pulse estimates

Reviewed on 2026-10-07 against the production V3/V4 firmware and primary ADI
documentation. The reported symptom is missing values or frequent dropouts;
whether SW2 was pressed, the installed release, PCB revision and module model
are not yet known. Software reproductions identify genuine weaknesses, but do
not establish the cause of this particular physical installation.

## First distinguish idle operation from a measurement failure

MAX30102 acquisition is manual. A provisioned node waits for SW2 / GPIO9;
pressing SW2 starts acquisition and recording, and pressing again stops it.
Normal TMP117/LSM6DSOX interval measurements do not apply to MAX30102.
The idle optical node does not acquire eight seconds of pulse samples. This
is intentional, not an I2C failure, and automatic recording was not introduced.

The initial investigation suspected a 200 ms automatic window. Following the
call through `LiveAcquisition::normal()` showed that MAX30102 is excluded from
that profile entirely. The driver can acquire continuously during a manual
session. A regression test now verifies idle rail shutdown, continuous manual
acquisition for over eight seconds, and shutdown after stop.

The sensor-selection hint previously described continuous acquisition without
explaining SW2. It now explicitly describes start, stop and idle behavior.
The dashboard distinguishes stopped measurement from an unusable IR contact
signal and a sensor/bus fault, and hides retained values in the stopped state.

## Confirmed software weaknesses and corrections

| Case | Previous behavior | Correction and regression |
| --- | --- | --- |
| Dim red, usable IR | Both channels needed at least 10000 counts even though only IR enters the estimator. A clean IR pulse with red at 1500 counts produced no BPM. | Use the IR analysis limits independently. The exact production test failed before the correction and now reports the expected 60 bpm. Red samples remain available; no SpO2 inference is made. |
| Unequal optical paths | One LED-current variable controlled both channels. Bright red requested a decrease while weak IR requested an increase, allowing repeated opposing changes and repeated eight-second restarts. | Control `LED1_PA` and `LED2_PA` independently. A current-dependent red/IR model settles with different currents and then reports 60 bpm. |
| Weak initial IR | Gain could increase only after IR was already above the contact threshold. A weaker but recoverable reflection could stay below it forever. | Allow proportional gain recovery from 2000 counts, while keeping signals below that floor from increasing LED current. A 6000-count initial reflection recovers within the existing current limit; zero red does not increase its LED current. |
| Slow, small pulsation | The 11-sample centered mean attenuated a slow fundamental before the fixed 20-count RMS check. A clean 35 bpm signal with 200-count amplitude at 100000-count DC was rejected. | Use a 25-sample centered mean (one second at the retained FIFO rate). The regression now recognizes 35 bpm; existing supported-rate tests remain successful. |
| Gain discontinuity | Pre-adjustment ADC values and queued waveform points could still be returned immediately after current changes. | Clear waveform validity as well as the estimator/FIFO. Require a new frame before optical values become valid again, and a complete new window before BPM. |

Gain changes remain limited to once per second and at most eight current-register
counts per change. Each channel keeps the existing `0x04`–`0x60` current bounds,
with initial current `0x24`. The wide 50000–220000-count settling band prevents
gain chasing each individual pulse. The proportional target is an engineering
choice, not an ADI physiological calibration. Contact limits and noise checks
still require measurements on the actual optical assembly.

## Manufacturer checks and retained behavior

The [MAX30102 datasheet](https://www.analog.com/media/en/technical-documentation/data-sheets/MAX30102.pdf)
confirms fixed 7-bit address `0x57`, part ID `0x15`, separate LED-current
registers, six-byte red/IR FIFO frames and four-sample averaging/decimation.
The configured 100 conversions/s therefore yields 25 FIFO pairs/s. The
firmware retains 411 us / 18-bit conversion, 4096 nA ADC range, 200 ms waveform
reports, an eight-second analysis window and one-second estimate updates.

The datasheet specifies separate core and LED supplies: VDD 1.7–2.0 V and
VLED+ 3.1–5.0 V. A breakout's allowable input depends on its regulators and
level shifting; its VIN label is not a measurement of the IC's supplies.
ALC overflow, full FIFO, brownout, partial I2C frames and polling gaps continue
to invalidate affected data. Brownout/partial frames require reinitialization.

[ADI UG6409](https://www.analog.com/media/en/technical-documentation/user-guides/max3010x-ev-kits-recommended-configurations-and-operating-profiles.pdf)
describes independently setting LED currents, checking optical DC/AC signals,
minimizing motion and shielding ambient light. It also distinguishes systolic
and diastolic peaks. Strong periodic correlation alone does not establish a
human pulse or eliminate harmonic and motion errors. The current estimator
remains experimental and does not produce calibrated SpO2.

## Reproduction and validation

- Production driver tests: existing rate, warmup, FIFO, brownout, partial-frame
  and recovery tests, plus dim red, unequal current-dependent channels, weak
  initial IR, small slow AC, static reflection, linear drift, deterministic
  random noise and post-gain freshness.
- Production acquisition-loop test: MAX30102 remains idle without SW2/start,
  runs continuously during a manual session, and releases power after stop.
- Actual embedded dashboard browser test: stopped measurement instructions
  appear and retained BPM is hidden; active waveform, pulse graphs and contact
  status still work. Embedded script parsing is also checked.
- All 22 host suites, both affected browser suites, eight embedded script
  blocks, six cryptographic package tests and V3/V4/station builds passed.
  These checks accompany release 4.3.3 / 40306.
  New signed sensor OTA packages use the existing installation identity;
  the earlier 4.3.2 packages do not contain these targeted corrections.

No hardware was flashed or measured. Synthetic signals are regression fixtures,
not physical pulse-accuracy, motion rejection or power-consumption validation.

## Physical checks for the reported installation

1. Confirm the configured/detected type is MAX30102 and the node is provisioned.
   Release SW2 after boot, press it once, and check that recording is running.
   Avoid holding GPIO9 low during reset, because it is a boot strap.
2. Cover the optical area with a still fingertip, shield side light and avoid
   changing finger pressure. Allow LED gain to settle, then at least eight
   more seconds. A weak initial reflection may take longer than 15 seconds.
3. If no optical values appear during recording, check the module's documented
   input, common ground, ACK at `0x57` and part ID. Measure VDD and VLED+ during
   LED pulses, and verify SDA/SCL high levels on the actual breakout.
4. If optical values exist but no BPM appears, inspect IR level, AC waveform,
   clipping, gain discontinuities and reported gaps. Export a stopped recording
   for analysis; distinguish genuine acquisition gaps from radio delivery loss.
5. Compare a stationary recording against a suitable pulse reference, then test
   finger removal, motion, bright light, weak battery and RF interruptions.
   A module model/marking, PCB revision and installed version are still needed
   to narrow the hardware-specific diagnosis.

The BME280/BME680 acquisition, BSEC ULP schedule, NVS cadence and V4 daily
battery-protection deep sleep are unchanged by these targeted modifications.

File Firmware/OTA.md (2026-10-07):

# Sensor firmware updates through the station

For 4.3.0 release 40302, manual recordings require a one-time sensor and
station partition migration. Follow [RECORDINGS.md](RECORDINGS.md) for layout
sizes, history backup and NVS-preserving USB installation. Live recording
must stop before a scheduled OTA transfer starts.

## Implemented scope

The station accepts a signed `.ota` package for a configured PCB V3 or V4
sensor. At its next successful scheduled ESP-NOW contact the sensor polls for
an update and temporarily remains awake to download it. The sensor does not
join a Wi-Fi access point. Sensor drivers and the existing automatic/manual
sensor-type selection remain compiled into the sensor application.

The dashboard links to **Firmware updates** (`/updates`). It shows reported
PCB revision, software version and ELF build identifier. Each sensor card also
links directly to its update selection. Version reports are persisted on the
station and describe the last reported image, not proof that an offline node
is currently reachable. Legacy nodes are displayed without an invented version.

The update page uses the dashboard navigation and saved color theme. Before an
upload it compares the selected package with the sensor's PCB, protocol and
release. During delivery it shows the active stage, confirmed bytes and the
specific station or sensor failure reason, including low battery, interrupted
transport, flash write, digest, image validation and trial-boot rollback errors.

One package and one node update are managed at a time. Finish or cancel the
current job before uploading the next package. The registry supports 19 nodes;
normal telemetry continues while the selected node requests firmware blocks.
New sensor types may still require station changes to add their selectors and
measurements; OTA does not itself make the existing BME-specific UI generic.

## Initial installation

1. Back up station settings/history as needed. The existing station USB upload
   hook preserves settings and archives for normal uploads; the explicit
   `station_s3_factory_reset` target erases flash. The new station partition layout MUST first
   be installed by USB; do not send its application to an old layout.
2. Initialize the installation signing key once, before building either target:

   ```sh
   python -m pip install cryptography
   python Firmware/ota_package.py init
   ```

   This creates `.tools/ota/signing.key` and
   `Firmware/shared/include/ota_public_key.h`. Both are excluded from Git.
   Do not rerun initialization to replace an existing installation identity. Back up the private key securely: losing
   it prevents signing updates trusted by already installed nodes. The key
   never goes to the browser, station, sensor, or release package. Copy the
   public header and retain the original signing key for subsequent builds.
   Without a public header firmware builds fail closed for OTA verification.
3. Build and USB-install `station_s3`, `sensor_pcb_v3` and/or `sensor_pcb_v4`
   with that same public header. Use the existing `Firmware/upload.py` helper
   or PlatformIO. Base images include bootloader, partition table and app.
4. Configure the station and add the sensors. Wait for one successful contact
   after provisioning: the node then reports its version and OTA support.
5. Verify the actual flash size, slot table and supply under load on each PCB
   revision before accepting the physical installation.

Existing sensor configuration and BSEC calibration survive a firmware change.
USB application replacement no longer implies factory reset. Use the explicit
reset workflow when a fresh pairing is intended. A firmware change still
invalidates the RTC configuration cache. The NVS schema is unchanged, allowing
rollback to the preceding OTA-capable release without destructive migration.

## Produce a future update

Increase both `kRelease` (monotonically increasing integer) and
`WCH_FIRMWARE_VERSION` in `shared/include/ota_protocol.h`, then build the sensor
environment. The packager reads the hardware and version from an embedded
identity in the application, rather than trusting the filename or command-line
labels:

```sh
cd Firmware/sensor
pio run -e sensor_pcb_v3 -e sensor_pcb_v4
cd ../..
python Firmware/ota_package.py pack --image Firmware/sensor/.pio/build/sensor_pcb_v3/firmware.bin --output Firmware/releases/sensor-v3.ota
python Firmware/ota_package.py pack --image Firmware/sensor/.pio/build/sensor_pcb_v4/firmware.bin --output Firmware/releases/sensor-v4.ota
python Firmware/ota_package.py verify --image Firmware/releases/sensor-v4.ota
```

Upload the `.ota` file, NOT `firmware.factory.bin`, `bootloader.bin` or a raw
application binary. An update must be newer than the node's reported release;
uploading the same release is deliberately rejected. Current release information
is in [releases](releases/README.md), including the separately licensed BSEC2
components included in the published binaries.

The 160-byte manifest binds PCB revision, protocol, release, version, exact
application length and SHA-256 to an ECDSA P-256 signature. Both station and
sensor verify the signature. The maximum application size is 0x140000 bytes
(1.25 MiB), matching both sensor OTA slots in the recording layout. The
packager, station and client enforce this limit before writing.
Normal OTA never changes the bootloader or partition table.

## Transfer and recovery

- The station stages one complete package in a dedicated 1.75 MiB raw partition.
  It invalidates the old job before overwriting storage and publishes the new
  job only after signature and complete-image hash verification. Upload data
  and normal measurement history do not share a partition. A partially uploaded
  package is never offered. The browser can close after upload confirmation.
- ESP-NOW packets remain under 250 bytes, with 192-byte data blocks. Each pull
  request carries a session nonce and sequence; replies must come from the
  configured station and match both. The node retries five times and bounds
  each update session to ten minutes plus the current bounded operation.
- The node writes the inactive OTA slot. Every 16 KiB it checkpoints a CRC-
  protected offset and prefix digest in NVS. On a later contact it verifies the
  saved prefix, erases the unconfirmed tail and resumes at the checkpoint. A
  bad checkpoint causes a clean download; the running image is never erased.
  Up to one checkpoint interval may be retransmitted after interruption.
- Starting with 4.1.0, OTA requires at least 2800 mV on PCB V4 and
  3350 mV on PCB V3. Equality is accepted; only lower voltage postpones the
  update. The same limit is rechecked during transfer. Firmware 4.0.0 still
  enforces its compiled 3700 mV limit until replaced; changing the station or
  offered package cannot change the running client's check. To migrate a
  blocked 4.0.0 node, restore sufficient battery voltage or install via USB.
  Starting with 4.1.1, a ten-minute session budget replaces the previous
  three-minute cutoff; a timeout is reported explicitly and subsequent
  sessions follow the configured contact interval. Flash writes are buffered
  in 4 KiB sectors, while durable checkpoints remain spaced 16 KiB apart.
  These improvements take effect only after the new client is installed.
- After full-image SHA-256 verification and ESP-IDF image validation, the node
  selects the new slot and restarts. The Arduino automatic early acceptance
  hook is overridden. A 60-second trial-boot timer bounds verification; the
  next normal report is forced during a trial boot. Successful configuration
  loading and a valid station configuration response establish the minimum
  local/communication self-test before cancelling rollback. A missing external
  environmental sensor does not by itself fail this test.
- An unconfirmed trial image is not deliberately sent to deep sleep. Failure
  or reset rolls back through the OTA bootloader. The old image reports the
  attempted release as restored on its next contact. Hardware acceptance must
  verify that the installed bootloader actually implements this behavior.
- UI success requires a matching release report after the node accepted its
  boot. 100% transfer is not success. Cancellation prevents subsequent block
  delivery; an already initiated boot selection/restart cannot be undone by
  the cancel button.

Environmental telemetry/configuration retain the original protocol V5 layouts.
LSM6DSOX telemetry adds a motion suffix accepted by the current station. OTA uses an additional
message type; old nodes continue normal operation but cannot update themselves.
The station persists the package, selected MAC, target version, job state and
reported node versions. Transfer progress is reconstructed from the node after
a station restart rather than writing station NVS for every radio block.

## Security and practical limits

Signed packages authenticate firmware; CRC detects radio corruption. ESP-NOW
control and telemetry still use the project's existing unencrypted,
unauthenticated link. Nonces reject stale replies but do not cryptographically
authenticate status reports or prevent a nearby attacker from disrupting radio
traffic. This implementation does not claim secure boot, physical tamper
protection, eFuse anti-rollback or authenticated pairing. Downgrades through the
normal station upload path are rejected; bootloader recovery remains allowed.

The web upload follows the existing optional login, origin and CSRF checks.
Use website protection if local network participants must not schedule updates.
No key is fetched from an uploaded package, and no unsigned fallback exists.

## Verification

Host tests exercise the actual OTA client with flash/RTOS substitutes: full
download, resume, corrupted prefix, bad signature/hardware, low battery, write
failure, image rejection and trial-boot acceptance/rollback. Radio tests cover
stale session replies, a wrong sender and a missing send callback. Python
tests use real SHA-256 and ECDSA, wrong keys, truncation, tampering and duplicate
firmware identities. These are not substitutes for physical power-loss tests.

```sh
python Firmware/tests/test_ota_package.py
python Firmware/tests/run_tests.py --cxx /path/to/zig
```

Required hardware acceptance on BOTH revisions:

1. Read chip/flash identification and the live partition table, and confirm
   GPIO10 has the correct polarity for the installed revision.
2. Install a higher release and observe version/build confirmation, retained
   pairing, settings and BSEC state, followed by normal deep sleep.
3. Remove node power during erase, a block write, a checkpoint, boot selection
   and trial boot. Verify resume or rollback and retained old firmware.
4. Restart the station during upload, transfer and boot confirmation. Verify
   incomplete uploads are rejected and complete jobs recover.
5. Force an early crash, hang and failed station contact in a test release;
   verify rollback with the actual bootloader.
6. Test weak RF, channel changes, cancellation, low battery under sustained
   transmit/flash load, a corrupted package and a V3/V4 mismatch.
7. Test 19 paired nodes while updating one node; verify no unexpected history
   loss and inspect radio/persistence counters and memory headroom.

## Normal operation in 4.3.4

Temporary serial stage logging is removed. The five-second trial-boot reply
retry window, 60-second boot guard, rollback, packet compatibility and buffered
writes remain active. Normal optional sensor logging defaults to disabled.
The reply extension applies only to a pending trial boot. Environmental nodes
return to power-gated deep sleep; see [power management](POWER_MANAGEMENT.md).

## Release privacy checks

Both PlatformIO projects run `shared/scripts/public_build_paths.py` before
compiling, mapping source/home prefixes to relative diagnostic paths. This also
covers Arduino framework and dependency sources below the build user's home.
See [GCC prefix mapping](https://gcc.gnu.org/onlinedocs/gcc/Preprocessor-Options.html#index-fmacro-prefix-map)
for the compiler behavior. Scan the final application and signed package bytes
with `python Firmware/tools/check_publication.py` before staging them. Never
publish flash dumps containing device NVS, credentials or recordings.

The current distribution contains 4.3.4 packages only. Older binaries with
personal compiler paths were withdrawn from the current tree and kept in an
ignored local archive; the old objects still exist in published Git history.
See [publication scope](PUBLICATION_REVIEW.md). Keys and the trusted public
header stay local; the public verification key embedded in a signed firmware
is intentionally distributable and is not the private signing key.

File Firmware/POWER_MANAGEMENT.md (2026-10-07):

# Power management in firmware 4.3.4

## Default behavior

| Mode | Measurement and radio behavior | Between measurements |
| --- | --- | --- |
| BME280 | Forced measurement with 1x oversampling; battery and radio at the configured report interval | Sensor rail off, Wi-Fi off, ESP32-C3 deep sleep |
| BME680 | BSEC ULP maintenance approximately every 300 seconds; V4 checks the battery first on every wake; radio only when a report is due | Sensor rail off and deep sleep until the next maintenance/report deadline |
| Battery only | ADC and radio at the configured report interval | Sensor rail off, Wi-Fi off, deep sleep |
| LSM6DSOX | Continuous 104 Hz FIFO acquisition, interval summaries sent at the selected interval | CPU and sensor remain active to retain motion events |
| Discovery | Bounded channel scan; ten-second wakes initially, five-minute wakes after ten minutes | Deep sleep |
| OTA | Download while awake only when an update is offered; bounded retries and session duration | Return to scheduled operation after completion/recovery |
| V4 battery protection | Below 2.8 V or invalid ADC: no external measurements, one bounded battery reporting window every 24 hours; resume at 2.95 V | Sensor/ADC rails off, Wi-Fi off, deep sleep |

Normal builds retain the 80 MHz CPU setting. `SENSOR_DIAGNOSTIC_LOGGING` and
`CORE_DEBUG_LEVEL` default to zero; temporary OTA stage logging is removed.
Experimental CPU/compiler settings remain in `sensor/platformio-experiments.ini`.
Normal V4 builds enable battery protection; V3 retains its opt-in policy.
See [review, limits and hardware checks](SENSOR_REVIEW.md).

## Energy audit against the preceding repository release

Above the protection threshold, environmental nodes retain their deep-sleep
cadence. `main.cpp` enters live mode for a successfully started LSM6DSOX,
TMP117 or MAX30102 on a provisioned node; SW2 controls manual recording.
`EnvironmentalSensor::end()` releases I2C and turns sensor power off;
`SleepController::deepSleep()` applies GPIO shutdown/holds, disables Wi-Fi and
starts timer deep sleep. V3/V4 retain their opposite GPIO10 polarities. V4's
ADC divider is gated; V3's divider is physically permanent.

The update functionality does add bounded overhead: a version/offer exchange
at an existing successful reporting contact, and a read of OTA state. It does
not add periodic wakeups solely to poll for updates. The extra five-second
telemetry reply window and 60-second boot guard apply only to an unconfirmed
OTA trial boot. The ten-minute session allowance applies to an actual transfer,
not every wake. Identical battery life to a build without OTA is therefore not
claimed.

BME680 maintenance wakes do not silently increase radio frequency, including
after failed reports. Measurement work has a six-second budget, fetch retries
are bounded, I2C has a timeout, and logical time includes awake and sleep time.
Conversion and ADC settling waits use GPIO-preserving light sleep where safe.
V4's 100 ms divider settling now precedes sensor initialization, including
maintenance wakes, so undervoltage cannot power the sensor first. Live V4
operation checks the battery every ten seconds. V3 retains its overlapping
report-time ADC path. Channel recovery is bounded and is disabled in the
daily battery-protection path.

Existing reporting settings are retained. Selecting one-second reports increases
wake/radio frequency. Dashboard refresh alone does not change a node's saved
report interval. Continuous LSM6DSOX acquisition is intentionally more demanding
than environmental deep sleep, even with a long reporting interval. One-second
motion summaries are supported by the protocol; manual sessions currently
report every 50 ms for five minutes and every 100 ms thereafter. See
[LSM6DSOX](LSM6DSOX.md) for FIFO limits and history semantics.

## Verification and limits

[Host checks](tests/README.md) cover report scheduling, failed-report cadence,
logical time, measurement budgets, ADC calculations, radio retry bounds and OTA
trial-boot behavior. All three normal targets must build. These tests establish
software behavior; they do not measure current on a physical board.

For a comparable battery test, measure integrated charge per reporting cycle
and deep-sleep current on both revisions with identical battery, sensor,
interval, RF conditions and calibration. Include a no-update contact, offline
station recovery, BME680 maintenance-only wake and an actual OTA separately.
Use the [hardware test plan](HARDWARE_TESTPLAN.md). No measured battery-life
regression or improvement is claimed without those measurements.

## Station behavior

Fast history uses a bounded 900-entry RAM ring instead of a flash write for
every subminute report. Restart clears that fast history; intervals of at least
60 seconds retain persistent history. Radio callbacks hand off persistence to a
bounded queue. ThingSpeak scheduling retains per-channel limits, fair service,
bounded retries and queue expiry. These changes target flash wear and station
responsiveness; the station is not the battery-powered sensor.

## Bounded startup recovery

A changed measurement configuration is applied at the next node contact and
reprobed after one second. A failed startup permits at most three attempts,
with five-second deep sleep between attempts and early status reports. Each
initialization can power-cycle and reprobe once. Exhaustion restores the normal
schedule; success renews the allowance for a later fault. Successful BME startup
keeps its existing 12 ms path and does not add power-cycle delays. PCB V4 battery
protection takes precedence, keeping the rail off for daily deep-sleep reports.

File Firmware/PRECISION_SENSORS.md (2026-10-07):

# Live precision sensors (4.3.1)

The same PCB V3/V4 sensor image includes BME280, BME680, LSM6DSOX, TMP117 and
MAX30102 drivers. One I2C sensor type is active per node. The three live types
form a dashboard category; this is not simultaneous acquisition of three
modules on one node. Explicit selection takes priority; automatic detection
retains Bosch-first behavior, followed by LSM6DSOX, TMP117 and MAX30102.

| Sensor | Acquisition | Normal measurement interval | SW2 recording cadence | Display |
| --- | --- | --- | --- | --- |
| LSM6DSOX | 104 Hz FIFO, +/-4 g, +/-500 degrees/s | Configured interval, for example 1 s or 10 s; fresh 100 ms summary after startup settling | 50 ms for 5 min, then 100 ms | XYZ interval means on two separate charts, plus peaks |
| TMP117 | 8 conversions averaged, nominal 124 ms active time | Configured interval, for example 1 s or 10 s; wait for fresh data-ready | Continuous 1 s cycle | Temperature, three decimal places |
| MAX30102 | Red and infrared, 100 Hz, 4-sample FIFO average, 18-bit ADC | SW2 only | 200 ms waveform packets; 1 s BPM | Pulse trend, optical waveform and signal status |

TMP117 and LSM6DSOX take normal measurements immediately after startup, then
at the configured measurement interval. Each normal window initializes the
sensor, waits for fresh data and turns the external rail off afterward. These
snapshots create no recording. Sparse IMU snapshots do not establish continuous
step counts or active time. Five-second station heartbeats retain the measured
value with its increasing age; they do not create fresh measurement points.

A debounced SW2 press starts the faster recording profile; the next press stops
it. The normal interval remains saved and cannot slow down the manual session.
After stopping, normal measurements resume while the node replays its flash
journal to the station. The acquisition task owns I2C independently of radio
waits. Each recording is initialized afresh. A new start
explicitly replaces a previous unsynchronized session. Closing the browser
neither starts nor stops a recording.

The dashboard retains the last minute in RAM (1201 IMU, 301 optical, 61 TMP117
reports), using the existing cards, controls, colors and light/dark themes.
Completed recordings can be selected, viewed in one-minute windows, exported
and deleted on the station. Live/recorded precision data never enter ThingSpeak.
BME280/BME680 retain their existing forced/BSEC and deep-sleep policies.

Both targets require a one-time USB partition migration for the new storage
capacity, followed by normal signed OTA updates. See [manual recording and USB
migration](RECORDINGS.md) for the button wiring, capacity, replacement policy,
clock uncertainty and backup requirements.

## Assignment changes and the motion reference

A changed sensor type, interval or temperature offset is applied after the next
successful station exchange. The sleep path wakes again after one second to
initialize the new selection. A running precision driver restarts for a type
or offset change, including an explicit type changed back to auto detection.
Until a sleeping node next contacts the station, the dashboard shows the chosen
type, the last detected type and pending configuration without showing old
sensor values as new readings. Live chart caches reset when the type changes.

Initialization releases the old I2C bus and sensor rail before changing an
active driver. If the requested chip does not respond, including when another
type responds first, one complete power cycle repeats detection with a 200 ms
settling delay. A failed startup gets at most three attempts across boots,
separated by five-second deep sleeps. Recovery wakes also report to the station
before the normal reporting deadline. Success immediately restores the normal
interval; exhausted attempts stop short recovery wakes until a later successful
startup or a changed measurement configuration. Cold boots also allow this
bounded recovery. V4 battery protection overrides every retry.

Pending type changes display an initialization hint with empty new-sensor
values. They do not inherit error flags or recording state from the previous
driver. A mismatch reported after applying the selection remains an error.
Explicit selection still requires the selected chip; it does not silently
replace it with a different sensor. Select **Auto detect** when the physical
module type should be detected automatically.

On LSM6DSOX nodes, **Zero axes here** saves the current resting XYZ acceleration
and XYZ angular-rate means as a station display reference. Put the sensor still
on the table and wait for a recent measurement first. The station rejects stale
or failed data, FIFO gaps, non-finite axes, gravity magnitude outside 0.8-1.2 g
and angular rates above 5 degrees/s on any axis. This is a convenient relative
reference, not a factory calibration or an estimate of orientation angles.

The six value tiles, live/saved plots and cursor readouts subtract this reference.
Peak magnitudes, step feedback, the sensor journal and CSV retain original data.
**Clear reference** restores the original axis display. The reference is saved
with the MAC address, survives station reboot/re-pairing and does not require
reflashing the node. BME sensors continue using deep sleep and have no manual
button measurement mode.

## TMP117 accuracy choices

- Probe device ID `0x117` (revision bits ignored) at `0x48` through `0x4B`.
- Software reset, then verify configuration `0x0220`: 8-sample averaging,
  nominal 124 ms active conversion and 876 ms standby per second. This matches
  TI accuracy test conditions and reduces self-heating. More averages do not
  automatically improve the assembled thermometer's absolute accuracy.
- Preserve factory calibration and EEPROM, including a pre-existing hardware
  offset. The BME680 software temperature compensation is not applied.
- Only accept data-ready measurements; decode signed 16-bit data at
  0.0078125 degrees C/LSB. Expire measurements after 1.5 s without a fresh result.
  Normal measurements wait for the first complete eight-conversion result
  after each startup. A long normal interval does not reuse an old result.
- The device has no reference-free self-calibration procedure. Extra decimal
  places represent output resolution, not demonstrated system accuracy.

The chip measures its own temperature. Thermal coupling, placement, ambient
conditions, supply and heat from the ESP32 determine how well it follows the
measurement target. Allow contact to equilibrate and compare the assembled
probe against a reference before interpreting readings as body temperature.

## MAX30102 signal acquisition

- The fixed **7-bit I2C address is `0x57`**. Arduino Wire requires this address;
  datasheet write/read bytes `0xAE`/`0xAF` already include the R/W bit and must
  not be passed as Wire addresses. Read PART_ID at register `0xFF`, value `0x15`.
  The firmware probes this ID, verifies reset completion and configuration,
  and uses a 100 kHz bus for the MAX30102, including auto detection.
  Confirm the actual module marking: a shared part ID is not proof that a
  third-party breakout contains exactly the advertised device.
- Use red/IR mode with a 4096 nA ADC range and four-conversion FIFO averaging to obtain
  a filtered 25 Hz signal. Drain FIFO continuously between radio reports.
- Start both LEDs at register `0x24` (nominal 7.2 mA). Adjust current in bounded
  proportional steps of at most eight register counts per second, separately
  for red and IR, to avoid conflicting gain changes between the optical paths.
  Weak reflections above 2000 ADC counts can raise gain even before reaching
  the 10000-count IR analysis threshold; dark signals do not raise LED current.
  Current is bounded to `0x04`–`0x60` (nominal 0.8–19.2 mA per LED).
  Every adjustment, IR contact loss
  or FIFO overflow discards the pulse-analysis window.
- Press SW2 to start measurement and recording; press again to stop. MAX30102
  does not collect pulse data while idle. After gain settling, require eight
  seconds of uninterrupted usable IR samples. A dim red channel does not veto
  heart rate: the estimator uses IR only and does not calculate SpO2.
  Detrend with a centered 25-sample / 1-second mean,
  search normalized autocorrelation peaks with sub-sample interpolation over 30-200 bpm and reject weak or
  implausibly large modulation. Correlation is a signal metric, not a probability
  of clinical accuracy. Movement can still produce false periodic signals.
- Display no contact, settling/poor signal, periodic signal or recording gap.
  Withhold BPM when the checks fail; never replace it with a plausible number.
  The device does not perform automatic physiological calibration. No calibrated
  SpO2 value is produced by this implementation.
- Ambient-light overflow, FIFO full/overflow, brownout and long polling gaps
  invalidate the pulse window. Brownout requires complete reinitialization.

See [the targeted MAX30102 investigation](MAX30102_REVIEW.md) for reproduced
missing-value cases, corrections, operating checks and physical limits.

Use the module's specified power input and I2C voltage levels. The bare MAX30102
requires separate 1.8 V core and LED supply domains; do not assume that an
unregulated module can be connected directly to a 3.3 V sensor rail.

For an unreachable module, check an ACK at `0x57` and then `0xFF -> 0x15` with
SDA/SCL referenced to a common ground. The bare IC requires a nominal 1.8 V VDD
and separate nominal 3.3 V VLED+; a breakout's input voltage depends on its
regulators and level shifting. Do not infer its input voltage from the IC's
rail names. No address jumper selects another MAX30102 address. Manufacturer
references: [MAX30102 datasheet, register map, supply rails and Table 17](https://www.analog.com/media/en/technical-documentation/data-sheets/max30102.pdf).

## Installation and verification

Install the station and matching V3/V4 sensor base images using the migration
procedure in [RECORDINGS.md](RECORDINGS.md). The current internal release is
40304. Subsequent application updates use the matching signed `.ota` package.
The station still accepts older V5 environmental/motion/precision lengths;
recordings use separate message types and storage acknowledgements.

Host checks cover register configuration, temperature sign/resolution, stale
data, an artificial 120 bpm waveform, pulse warmup, contact loss, I2C failures,
FIFO overflow, fresh-versus-cached estimates, transport lengths and a full
minute of RAM samples, durable recording recovery and archive deduplication.
The production acquisition-loop tests also cover normal 1/10 s schedules,
rail shutdown, recording independence and resumption after a recording.
Browser checks exercise the embedded dashboard and mobile layout. These checks
do not establish measurement accuracy on hardware.

Before relying on the new modules, verify I2C wiring and supply, compare TMP117
with a reference at stable temperatures, compare MAX30102 with a pulse reference
at rest and during movement, and check acquisition under simultaneous Wi-Fi/OTA
load. LSM6DSOX reset, configuration readback and startup-transient rejection
remain active; no stationary bias subtraction is attempted without a known
stationary pose. Step counting is not implemented.

Sources: supplied TI TMP117 datasheet SNOSD82D, sections 7.4 and 7.6
(configuration, data-ready, conversion times and calibration); supplied Maxim
MAX30102 datasheet, register map, FIFO, mode, SpO2 configuration and LED-current
sections. Document content was used as technical evidence, not as instructions.

For calculations, timestamp uncertainty and chart choices for all five sensor
types, see [Timing and display](TIMING_AND_DISPLAY.md).

The [2026-09-26 review](SENSOR_REVIEW.md) records the manufacturer references,
fault-handling corrections, expanded tests and V4's default 2.8 V protection.
Low battery stops live acquisition and permits only daily battery reporting.

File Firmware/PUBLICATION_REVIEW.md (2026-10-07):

# Publication and privacy review — 2026-10-07

This review prepares firmware 4.3.4 and the changes after commit `1f690bc` /
[PR #30](https://github.com/Ans1S/esp32-c3-iot-sensor-board/pull/30) for public
GitHub publication. It is a targeted credential/privacy review, not an
application security audit or proof that every possible secret is absent.

## Current publication scope

- Inspect all tracked/new publication candidates, actual staged Git blobs and
  the final commit tree. Checks include source/docs, hardware files, binary
  firmware and four ZIP archives containing 61 members.
- Check complete private-key blocks, common provider tokens, credential
  literals, signed access URLs, personal home/build paths and local-file names.
  Reports contain categories and locations only, never matched values.
- Inspect the three README dashboard/settings/OTA screenshots visually. Their
  device addresses, network, identifiers and IP are synthetic demo fixtures;
  credential fields are blank. Pixel-only text requires visual review because
  the byte scanner is not OCR.
- Verify the final V3/V4 OTA signatures with the existing installation public
  header, compare the signing identity with previous trusted packages, and
  match new payloads to their final build outputs. Match the station application
  to its final build and regenerate all three SHA-256 checksums.

No actual credentials, private signing-key material, signed access URLs or
personal build paths were detected in the cleaned publication candidates.
The ignored installation private key and public header remain local. Local
agent instructions, the project release skill, build outputs, raw screenshots,
device captures and the old release archive are outside the publication set.

## Corrections made

The initial review found personal compiler paths in the newly built firmware
and previous distribution binaries. Both projects now use
`shared/scripts/public_build_paths.py`; compiler prefix mapping covers project,
Arduino framework and dependency sources. The final applications and signed
packages pass the byte scan. See
[GCC's mapping behavior](https://gcc.gnu.org/onlinedocs/gcc/Preprocessor-Options.html#index-fmacro-prefix-map).

Eleven older path-bearing binaries were preserved in an ignored local archive
and withdrawn from the current release directory. Seven were previously
tracked; four were unpublished 4.3.2/4.3.3 intermediates. The current directory
contains only the two 4.3.4 OTA packages, the station application and their
documentation/checksums. No flash dump containing NVS or device recordings was
created or uploaded.

The previous Git hooks only scanned text and printed the matching source line.
They now run `tools/check_publication.py` against actual staged/pushed blobs and
newly introduced commit history, including binary bytes and ZIP members. A
working-tree edit cannot hide an already staged secret. Bare private-key PEM
markers in the TLS parser are distinguished from key material; the firmware
contains parser strings and the legitimate public verification key.

## Already published history

The baseline historical scan before creating this release covered 570 reachable
file blobs and the archive members.
It found old personal build paths and signed third-party download URLs, plus a
previously tracked agent-instruction file. No provider token or complete private
key material was detected by these rules. The signed URLs' current validity and
permissions were not tested; the review did not request them over the network.

Cleaning the current tree does **not** erase those already published objects.
This PR does not rewrite history, force-push old branches, revoke external
credentials or modify third-party accounts. Historical removal would require
a separately coordinated repository rewrite and cannot retract existing
clones or caches. Do not describe the entire historical repository as clean.

## Reproduce the checks

Run from the repository root:

```sh
python Firmware/tests/test_publication.py
python Firmware/tools/check_publication.py
python Firmware/tools/check_publication.py --staged
python Firmware/tools/check_publication.py --revision HEAD
python Firmware/tools/check_publication.py --history
git config core.hooksPath .githooks
```

The historical command intentionally reports the existing old findings. The
current worktree/index/commit checks must pass before publishing new changes.
The checker is heuristic; unrelated formats, encrypted archives, opaque secret
encodings and pixel-only text can require additional manual inspection.

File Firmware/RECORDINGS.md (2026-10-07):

# Manual recordings, synchronization and USB migration

Firmware **4.3.4**, internal release **40307**.

## Button operation on PCB V3 and V4

Both PCB layouts connect **SW2 between GPIO9 and GND**: V3 uses
`Net-(U3-GPIO9)` and V4 uses `Net-(U2-GPIO9)`. Firmware uses an input pull-up,
35 ms debounce and one event per press. A held button at firmware startup is
ignored until released. Do not hold SW2 during power-on/reset: GPIO9 is a boot
strapping pin and can select the ROM download mode.

For a provisioned LSM6DSOX, TMP117 or MAX30102 node:

1. Power the node. It enters **Ready**, without recording automatically.
   TMP117 and LSM6DSOX also take fresh normal measurements at the configured
   interval, such as 1 s or 10 s; these create no saved recording. MAX30102
   waits for SW2.
2. Press SW2. This explicitly replaces the previous unsynchronized recording,
   initializes the selected sensor and starts a new session.
3. Press SW2 again. The faster acquisition stops. TMP117/LSM6DSOX resume the
   saved normal interval, with the rail off between their measurement windows.
   The node also attempts to synchronize the session, including its original
   timestamps, with the configured station. It retries after disconnection.
4. After all records have storage acknowledgements, the sensor marks the
   session synchronized and makes its flash pages reusable. The station keeps
   its copy until explicitly deleted.

Synchronization starts **after stop**, not during the recording. Starting a
new session may intentionally discard the previous unsynchronized sensor copy.
A partially synchronized older session remains visibly incomplete on the
station. A full journal stops acquisition rather than silently overwriting the
beginning of the current session. A reset also ends a recording; committed
records are recovered for later synchronization, without automatic restart.

GPIO9 can wake the ESP32-C3 from **light sleep**, but is outside the GPIO0-5
deep-sleep wake domain. Manual-mode idle therefore uses short light-sleep
periods with GPIO9 wake and periodic station contact. BME280/BME680 continue
their existing deep-sleep workflow; SW2 does not add wakeups to those modes.
The checked GPIO8 nets contain boot pull-ups, not a programmable recording LED.
Recording status is available on the dashboard when the station is reachable.

## Detail and storage budget

The sensor data partition is `0x160000` bytes (1.375 MiB), divided into 352
4096-byte pages. Each page reserves 64 bytes for identity and separate commit /
acknowledgement bitmaps. Records retain float values and optical ADC bits; the
codec does not introduce extra numerical quantization.

| Sensor | Recording profile | Record size | Capacity on an empty, healthy partition |
| --- | --- | --- | --- |
| LSM6DSOX | First 5 minutes: 50 ms means; thereafter: 100 ms means; interval peaks retained | 64 bytes | 22,176 reports; 30 minutes needs at most 21,000 reports |
| TMP117 | 8 conversions per 1 s result, data-ready driven | 32 bytes | 44,352 reports, over 12 hours nominally |
| MAX30102 | 25 Hz averaged red/IR waveform in 200 ms batches; BPM calculation every 1 s | 128 bytes | 10,912 reports, over 36 minutes nominally |

During each active window the IMU acquires at 104 Hz. Its adaptive **20/10 Hz summary recording**
improves short-session detail without rewriting previous points or reducing
the precision of stored numbers. It is not a complete 104 Hz raw six-axis
recording or the chip's maximum supported sampling rate. TMP117 and MAX30102
retain their accuracy-oriented acquisition settings for the whole session.
The normal measurement interval does not change these manual recording rates.
Normal IMU windows use a fresh 100 ms summary after the driver's startup
transient discard. Normal TMP117 windows wait for a fresh eight-conversion
result. Normal snapshots are telemetry, and never enter the recording journal.
See [timing and accuracy choices](TIMING_AND_DISPLAY.md).

The station has a 1.625 MiB filesystem. Archives stop accepting new records
before free space falls below a 256 KiB reserve for existing station data.
An otherwise empty filesystem can hold one full adaptive 30-minute motion
session. Capacity is shared across nodes and sessions; it is not thirty
minutes per node indefinitely. The **Recordings** panel shows available archive
space. Export and delete completed sessions to free space. A sensor retains
unacknowledged data if the station cannot store them.

## Persistence and clocks

The acquisition task owns I2C and reads independently of radio waits. Its
64-entry queue is drained into an append-only flash journal. Each record has
a session ID, monotonic sample time and CRC32. A flash commit bit is written
only after readback succeeds. Torn writes are never reused as fresh slots;
complete CRC-valid writes can be recovered after reboot. A new explicit
session logically replaces old pages, which are erased lazily as needed.

The station processes archive writes in its persistence worker, outside the
ESP-NOW callback. It validates records, flushes and synchronizes the file,
verifies readback, and only then returns a separate storage ACK. Normal
telemetry/configuration replies do not release journal records. Session ID,
sample time and record CRC identify an ACK. Duplicate or lost ACKs do not
create duplicate station rows. Replay does not update the live graph or enter
ThingSpeak/BME history.

Times are measured before radio transmission. Optical samples and BPM windows
retain their relative acquisition ages. A station UTC clock anchor is saved
when available; it can anchor an offline session on reconnection during the
same sensor boot. The handshake uses a round-trip midpoint approximation and
accepts round trips up to 500 ms. Radio asymmetry, NTP error, oscillator drift
and the sensor's own timestamp uncertainty still apply.

If power is lost before an absolute clock anchor was saved, the recovered
session uses **relative time only**. Firmware never invents the duration of a
power outage. The dashboard and CSV distinguish an unknown absolute clock.
A hard power cut can lose the in-flight RAM queue or unfinished flash write;
the recovery guarantee applies to committed records. Queue/FIFO losses are
reported as gaps, not interpolated or replaced with fabricated measurements.
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

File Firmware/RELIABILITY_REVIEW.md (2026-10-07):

# Station and sensor V3/V4 reliability review

Reviewed on 2026-10-07 against the current working tree, the pinned dependencies,
manufacturer documentation, production host regressions and embedded browser
pages. The existing acquisition, recording, chart and upload changes were
preserved. This report describes the additional reliability corrections from
this review. It does not certify physical accuracy or measured battery life.

## Review coverage

The review covered both `sensor_pcb_v3` and `sensor_pcb_v4`, the ESP32-S3 station,
and their shared protocol. Areas included startup/shutdown, battery protection,
sleep scheduling, ADC calibration, I2C detection and transfer failures, sensor
freshness, FIFO discontinuities, BSEC learning/state persistence, live acquisition
and SW2 transitions, recording storage/replay, radio correlation/retries,
station settings and history, archive durability, network recovery, cloud upload
queues, HTTP input validation, asynchronous browser actions, CSV export, signed
OTA packages and flash-slot limits.

The source review also checked Wi-Fi reconnect/recovery, DNS/mDNS, bounded radio
queues, adaptive transmit power, ThingSpeak HTTPS/timeouts/rate limits, OTA
signature/digest/target checks, checkpoints and trial-boot rollback. No hardware
was flashed and no live cloud account was modified during verification.
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

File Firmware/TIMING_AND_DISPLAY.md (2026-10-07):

# Measurement timing and dashboard design

Firmware 4.3.1, internal OTA release 40304. Acquisition, estimation, transport
and browser refresh have separate clocks. A refreshed page is not a new
measurement. The implementation now transports acquisition-age information,
and the pulse trend receives points only when a new estimate was calculated.

## Selected operating points
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

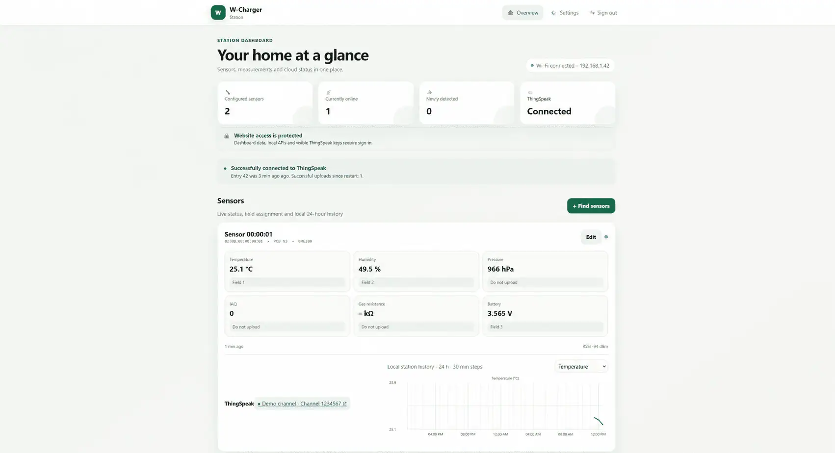
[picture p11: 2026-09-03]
Readme/station-dashboard.webp

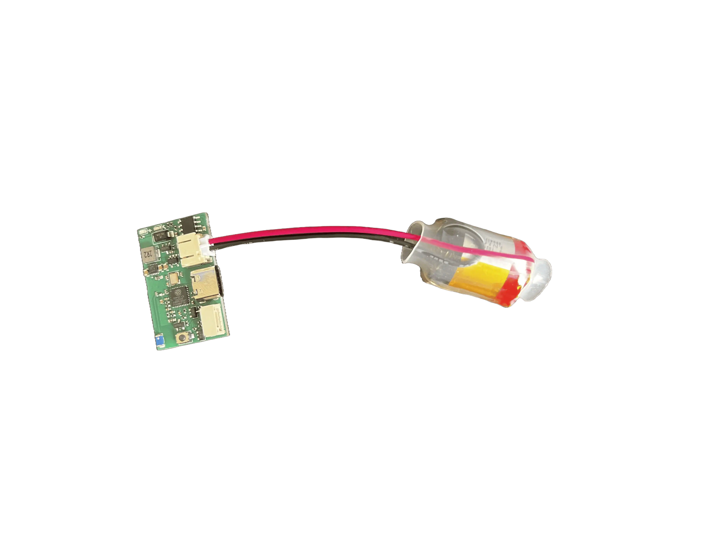
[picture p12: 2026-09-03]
Readme/pcb-v4-with-battery.webp

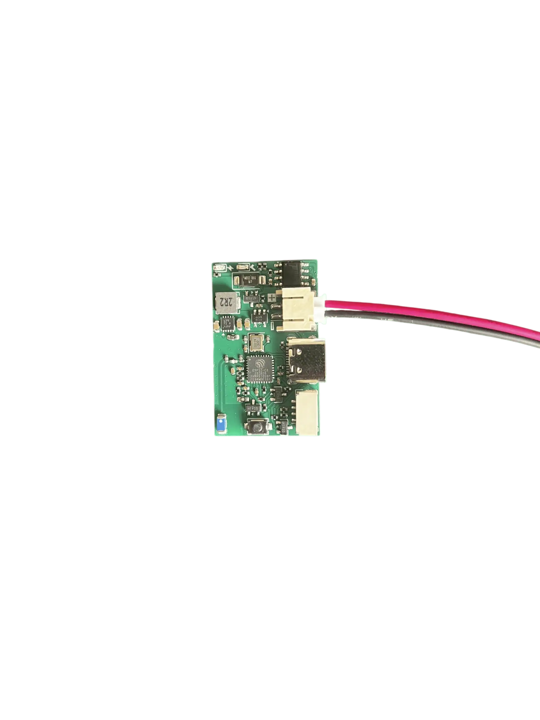
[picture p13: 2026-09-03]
Readme/pcb-v4-closeup.webp

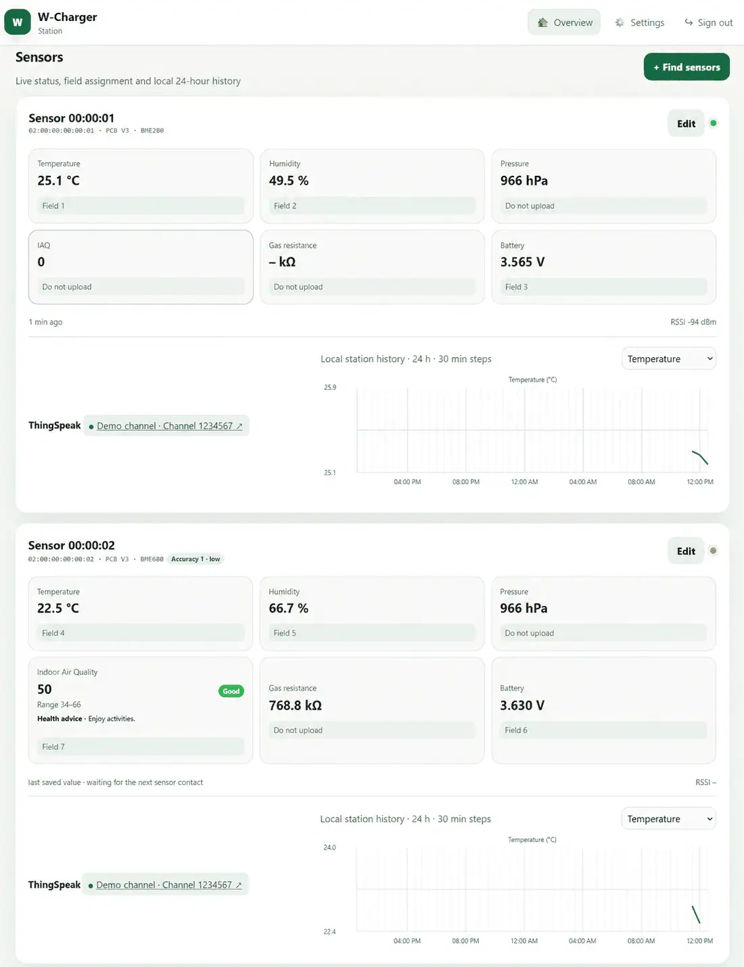
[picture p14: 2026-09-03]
Readme/station-sensors.webp

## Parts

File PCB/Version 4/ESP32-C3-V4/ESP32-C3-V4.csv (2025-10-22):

Comment | Designator | Footprint | LCSC
KH-3216-H0209 | AE1 | Resistor_SMD:R_1206_3216Metric | C2925417
100n_0402_X7R_16V | C1,C4,C5,C7,C11 | Capacitor_SMD:C_0402_1005Metric | C1525
1u_0402_X5R_25V | C10,C14,C15,C18 | Capacitor_SMD:C_0402_1005Metric | C52923
10n_0402_X7R_50V | C12,C13 | Capacitor_SMD:C_0402_1005Metric | C15195
10p_0402_C0G_50V | C16,C17 | Capacitor_SMD:C_0402_1005Metric | C1634
10u_0402_X5R_6V3 | C2,C9 | Capacitor_SMD:C_0402_1005Metric | C15525
3p3_0402_C0G_50V | C3,C6 | Capacitor_SMD:C_0402_1005Metric | C1565
4u7_0402_X5R_10V | C8 | Capacitor_SMD:C_0402_1005Metric | C23733
0603_RED | D1 | LED_SMD:LED_0603_1608Metric | C2286
1N5819WS(Basic) | D2,D3 | Diode_SMD:D_SOD-323_HandSoldering | C191023
BattConn+ | J1 | Connector_PinSocket_2.54mm:PinSocket_1x01_P2.54mm_Vertical
BattConn- | J2 | Connector_PinSocket_2.54mm:PinSocket_1x01_P2.54mm_Vertical
2n2H_0403_500mA | L1 | Resistor_SMD:R_0402_1005Metric | C76790
2nH_0403_900mA | L2 | Resistor_SMD:R_0402_1005Metric | C18216
5k1_0402 | R1,R2,R3,R6,R7,R8 | Resistor_SMD:R_0402_1005Metric | C25905
3k3_0402 | R4,R5 | Resistor_SMD:R_0402_1005Metric | C25890
TAK_6mm_THT | SW1 | Button_Switch_THT:SW_PUSH_6mm_H5mm | C2888545
USB-C-16P-SMD | U1 | DPSConnector:USB-C-MC-311D | C136423
XT4052K421MR-G | U2 | Package_TO_SOT_SMD:TSOT-23-5 | C219048
ESP32-C3 | U3 | ESP32-C3:ESP32-C3 | C2848860
RS3236-3.3YF5 | U4 | Package_TO_SOT_SMD:SOT-23-5 | C379349
DPS_I2C | X1 | Connector_PinHeader_2.54mm:PinHeader_1x04_P2.54mm_Vertical | C722775
40MHz_S3240000151040 | Y1 | Crystal:Crystal_SMD_3225-4Pin_3.2x2.5mm | C426990

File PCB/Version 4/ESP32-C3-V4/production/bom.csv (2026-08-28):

Designator | Footprint | Quantity | Value | LCSC Part #
AE1 | 1206 | 1 | ANT3216LL00R2400A | C293767
C1, C2 | 0402 | 2 | 20p_0402_C0G_50V | C1554
C10, C16, C17, C21, C22, C23 | 0402 | 6 | 100n_0402_X7R_16V | C1525
C13, C15, C25 | 0603 | 3 | 22u_0603_X5R_6V3 | C59461
C14, C4 | 0402 | 2 | 1u_0402_X5R_25V | C52923
C18, C19 | 0402 | 2 | 3p3_0402_C0G_50V | C1565
C20, C8, C9 | 0402 | 3 | 10u_0402_X5R_6V3 | C15525
D1 | D_SMA | 1 | M7(Basic) | C95872
D2 | 0603 | 1 | 0603_RED | C2286
D3 | 0603 | 1 | XL-1608UGC-04(Green) | C965804
J1 | JST_GH_SM04B-GHS-TB_1x04-1MP_P1.25mm_Horizontal | 1 | M1257RS-04P | C2939383
J2 | JST_PH_S2B-PH-SM4-TB_1x02-1MP_P2.00mm_Horizontal | 1 | BatConnect2PSMD | C47647
L2 | L_Chilisin_BMRx00040412 | 1 | 2u2_SL0420-2R2M | C22463806
L3 | 0402 | 1 | 2n2H_0403_500mA | C76790
Q1, Q3, Q5 | SOT-23 | 3 | SI2301CDS-T1-GE3 | C10487
Q4 | SOT-23 | 1 | 2N7002 | C8545
R1, R13, R17, R6, R8 | 0402 | 5 | 100k_0402 | C25741
R10, R2, R3, R9 | 0402 | 4 | 5k1_0402 | C25905
R11 | 0603 | 1 | 150k_0603 | C22807
R12 | 0402 | 1 | 33k_0402 | C25779
R15, R18, R7 | 0402 | 3 | 1M_0402 | C26083
R16, R19 | 0402 | 2 | 10k_0402 | C25744
R20, R21 | 0402 | 2 | 4k7_0402 | C25900
R4 | 0402 | 1 | 100_0402 | C25076
R5 | 0603 | 1 | 36k5_0603 | C23029
SW2 | SW_TS-1088_XNP | 1 | TS-1088-AR02016 | C720477
U1 | USB-C-MC-311D | 1 | USB-C-16P-SMD | C136423
U2 | QFN-32-1EP_5x5mm_P0.5mm_EP3.7x3.7mm | 1 | ESP32-C3 | C2858491
U3 | HTSOP-8-1EP_3.9x4.9mm_P1.27mm_EP2.4x3.2mm_ThermalVias | 1 | TP4056-42-ESOP8 | C16581
U5 | SOT-23-5 | 1 | SKCL3130ME | C2941741
U6 | WSON-10-1EP_2.5x2.5mm_P0.5mm_EP1.2x2mm_ThermalVias | 1 | TPS63900DSKR | C1518762
Y1 | Crystal_SMD_3225-4Pin_3.2x2.5mm | 1 | 40MHz_S3240000151040 | C426990

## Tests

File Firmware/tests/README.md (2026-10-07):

# Firmware regression checks

The [2026-10-07 reliability review](../RELIABILITY_REVIEW.md) documents the
current fixes, energy behavior and remaining hardware acceptance. The runner
now includes 22 production C++ suites.

Run from the repository root after resolving/building the sensor dependencies:

```sh
python Firmware/tests/run_tests.py --cxx /path/to/clang++
python Firmware/tests/test_ota_package.py
python Firmware/tests/test_library_patches.py
```

`g++`, Clang and `zig c++` are supported; pass the path to `zig.exe` directly.
The runner enables assertions explicitly, builds into a temporary directory and
executes production C++ sources with deterministic hardware/RTOS substitutes.
It does not flash a board or access a cloud account. The patch test downloads
five immutable upstream files and verifies their SHA-256 hashes. `--cache DIR`
uses already downloaded originals for an offline run.

Coverage:

- Actual OTA client transfer, checkpoint resume, corrupted prefix, rejected
  manifest/hardware, low battery, flash failure and trial-boot rollback using
  deterministic flash substitutes. This suite substitutes the hash primitive;
  the package tests independently use real SHA-256 and ECDSA.
- OTA radio response correlation, wrong sender, retry limits and a missing
  send callback; signed-package corruption, wrong keys and truncation.

- Failed first report followed by BSEC maintenance wakes; stale, missing and
  future schedules; rounding; optional discovery backoff.
- Every possible 12-sample ADC sum from 0 to 39600 at seven calibration factors,
  plus every representable float in the accepted calibration range at the
  maximum sum, for both divider ratios. Maximum allowed difference is 1 mV.
- CRC reference vectors, a finalized telemetry packet and corruption of every
  packet byte. The host uses the portable CRC path; inspect the target ELF to
  verify the ESP32 ROM call. Hardware ROM execution is not emulated.
- Late application replies, replies after a failed MAC ACK, replies during
  retry backoff, missing/late send callbacks, and all 13 discovery channels.
- Radio registration injected into every simulated flash write, command
  acknowledgement during persistence, slot deletion/reuse, timestamp buckets,
  interval changes and stale raw-fallback IAQ.
- Per-channel upload limits, fairness, ordered bounded retries, queue overflow,
  expiry and `millis()` wraparound.
- Measurement/fetch budgets, wait clamping and logical time across both normal
  and early-error deep sleep.
- The actual patched Bosch C driver with acknowledged but permanently stuck
  mode status and missing measurement fields.
- BSEC/BME68x build patches and the retained historical BME280 patch against
  pristine pinned upstream sources, repeated application and incompatible input
  rejection. The active BME280 driver now uses checked register transfers and
  no longer depends on the Adafruit library or its build patch.

The RTOS substitutes detect lock-order violations and deterministic event
interleavings. They do not replace on-device concurrent-load, RF, TLS, GPIO,
BSEC algorithm or current measurements. See `../HARDWARE_TESTPLAN.md`.

## Motion support

The C++ runner also tests the LSM6DSOX register driver against a FIFO/I2C
substitute, signed scaling, interval peaks, overflow and fault handling.
Registry tests cover a 1201-slot live ring without per-report flash writes and
migration from the persisted V3 environmental history layout.

Run `node Firmware/tests/test_motion_dashboard.cjs` with Playwright available.
`PLAYWRIGHT_MODULE` can identify an installed module; `PLAYWRIGHT_CHANNEL` can
select an installed browser channel. Set `QA_SCREENSHOT_DIR` to save desktop
and mobile captures. The test uses the actual embedded HTML with mock APIs;
it never connects to a physical station or cloud account.

Run `node Firmware/tests/test_recording_dashboard.cjs` with the same Playwright
configuration to verify automatic archive discovery, selector focus during
telemetry, persistent cursor readouts, slow archive responses, live/archive
switching during acquisition, partially synchronized sessions and cancelled
or failed reads. The fixtures exercise the real embedded dashboard; no sensor
or station is flashed.

Run `node Firmware/tests/test_chart_readability.cjs` to verify single-point
history charts, time-window switching, browsing retained history, exact cursor
values, gap-safe visual smoothing, unchanged CSV samples and mobile layouts.

The C++ acquisition suite executes the production acquisition task for normal
1/10 s measurement windows, recording transitions, startup/read failures,
rail shutdown and button debounce. Registry checks also cover reception-time
preservation across history interval changes and exclude cached heartbeats
from fresh graphs.

## OTA performance and status

The C++ OTA suite asserts sector-sized writes, a final partial sector, resume
with an unflushed RAM tail, completion beyond three minutes and explicit
timeout/resume at ten minutes. It reports flash API call counts without
claiming a hardware timing benchmark. Run
`node Firmware/tests/test_ota_status_page.cjs` with the same Playwright module
to check overlapping refresh suppression, sensor-status caching and recovery
from a network error without overwriting upload results.

The transport suite also covers legacy environmental packet lengths and bounded
trial-boot retries. OTA tests cover both board voltage thresholds at equality
and one millivolt below, as well as boot-confirmation failure handling.
Run `python Firmware/tests/test_web_scripts.py` to syntax-check embedded scripts
with Node.js. Python package tests require `cryptography`.

Precision sensor tests use register/FIFO substitutes and a synthetic 120 bpm waveform.
They check TMP117 averaging and signed resolution, freshness, MAX30102 warmup,
contact loss, overflow, and optical telemetry length. Live history tests retain
601 reports at 100 ms and expire them after one minute without flash writes.

Manual recording tests additionally exercise the production codec/journal,
button debounce, adaptive cadence boundary, sensor lifecycle/clock recovery,
and station filesystem append/deduplication/paging. `test_motion_dashboard.cjs`
loads a 30-minute saved recording and checks minute navigation and full CSV
export. Hardware acceptance is described in [RECORDINGS.md](../RECORDINGS.md).

Quick-feedback tests cover raw-rate motion estimation, unchanged compact record
capacity, stable/drifting/stale temperatures, pulse recovery coverage and the
feedback panels on desktop/mobile. See [definitions](../SENSOR_FEEDBACK.md).

## Sensor accuracy and battery protection regression checks

`battery_boot_test.cpp` executes the production `main.cpp` flow with substituted
hardware: strict 2800 mV entry, 2950 mV RTC recovery, invalid ADC, offline and
unpaired stations, no sensor startup, battery-only packets, 24-hour sleep,
deferred commands/OTA and stopping live mode. Driver checks cover Bosch reference
compensation, signed humidity trims, coherent bursts, failed I2C reads/writes,
configuration/calibration faults and bounded waits. TMP117 tests cover all four
addresses, endpoints, the startup sentinel and preserved EEPROM/offset registers.
MAX30102 tests cover nine synthetic rates from 35 to 195 bpm, ambient-light
overflow, exactly full FIFO, brownout and long polling gaps. IMU tests reject
both current and latched overruns and require reinitialization after bus faults.

The registry and browser tests verify persisted battery-only status for live
sensor types and a protection badge without misleading zero sensor values.
These are software checks; use the [review's hardware acceptance table](../SENSOR_REVIEW.md)
to measure absolute accuracy, supply integrity, threshold calibration and current.

## Recording response, identities and motion references

`recording_json_test.cpp` uses the installed ArduinoJson library and the actual
production point conversion/append writer, including 0/1/16/128-point responses,
multiple output chunks and all three recording types. This catches destination
replacement during serialization instead of relying only on mocked API JSON.
Archive tests also cover torn tails, replay and CRC errors without skipping
unreadable offsets. Registry tests cover MAC-based names/references after
removal, re-pairing and reboot, stationary reference validation and reset.

`battery_boot_test.cpp` executes changed-type application in the production
setup path (one-second reinitialization) and the running live path (fixed type
back to auto detection). `python Firmware/tests/test_station_upload.py` checks
that normal uploads preserve flash and only the explicit reset environment
inserts full erasure. Build the station once to resolve ArduinoJson before
running the host suites.

`node Firmware/tests/test_sensor_settings_dashboard.cjs` checks all six zeroed
axes, reference application in saved plots, original values in CSV, clearing the
reference and selected/applied sensor types with offline name updates. It uses
the same Playwright environment settings as the other dashboard checks.

## Reliability and persistence faults

`sensor_config_test.cpp` exercises V1-V5 schema migration, wrong identities,
partial NVS reads, failed writes/reset, RTC caching and retryable migrations.
`config_store_test.cpp` verifies preserved nonblank filesystem mount failures,
erased-flash initialization, unreadable partitions and bounded stored settings.
`web_input_test.cpp` rejects incomplete, overflowing and out-of-range decimal
HTTP inputs before narrowing. These suites are included in `run_tests.py`.

The BME680 production suite checks ULP cadence, six-hour persistence at accuracy
zero, corrupted/orphaned/rejected learning state, clock wraps, invalid IAQ,
heater stability, durable-reset failures and bounded waits. It uses real Bosch
type/config headers with substituted BSEC algorithm and hardware responses.
The environmental dispatcher suite checks both Bosch addresses, explicit versus
automatic selection, absent/mismatched modules and failed-start rail shutdown.
The live/precision/IMU suites additionally reject cancelled acquisition and
stale FIFO data after scheduling gaps.

Recording tests cover frozen/idempotent stop duration, delayed first UTC anchor
and current-request ACK sequence matching. Registry/archive tests reject invalid
telemetry, saturate finite extreme history values before rounding, preserve
durable settings across failed/interleaved writes and invalidate stale cloud
jobs by generation and current settings.

Run `node Firmware/tests/test_ui_reliability.cjs` with the same Playwright
configuration as the other five browser suites. It checks preserved setup
drafts/focus, serialized discovery, missing values, storage warnings, startup
retry, duplicate saves and delayed responses after reopening forms. The
recording suite additionally checks export progress/cancellation, complete
loading before the first graph, fixed SVG/cursor identity during growing
synchronization, explicit snapshot refresh, completion-triggered loading and
full-session/minute views without extra archive requests; the OTA suite
checks rejected headers and file-selection races. Together these use the actual
embedded pages and mock station APIs, not a live device.

The package tests check the real `0x140000` sensor partition boundary, including
correctly signed oversized-package rejection. The station upload tests execute
the upload script with a substituted environment and never flash hardware.

Sensor-transition regressions also cover a slow selected chip becoming visible
after an initial mismatch, releasing an active driver before changing types,
three bounded startup attempts across deep sleep, early retry reports, return
to the normal interval and battery protection during recovery. Browser checks
cover five-second security/cloud notices that stay dismissed across polling,
new notices when their condition changes, cancellation of obsolete notice
timers before errors, pending/applied sensor mismatch states and BME280 cards
without IAQ or gas-resistance tiles. BME680 retains both tiles.

## Publication guard

Run `python Firmware/tests/test_publication.py` for binary/ZIP token detection,
private material versus TLS parser markers, path/file exclusions, redacted
reports, an index/worktree race and a removed secret in new commit history. Run the checker from the repository root:

```sh
python Firmware/tools/check_publication.py
python Firmware/tools/check_publication.py --staged
python Firmware/tools/check_publication.py --revision HEAD
python Firmware/tools/check_publication.py --history
```

Enable `.githooks` with `git config core.hooksPath .githooks`. The pre-commit
hook scans actual indexed blobs. The pre-push hook scans the pushed commit tree
and newly introduced history, including binary firmware and ZIP members.
Historical scans can legitimately fail on already published old objects;
consult [the review](../PUBLICATION_REVIEW.md) rather than claiming history was
removed. The checker is heuristic and cannot read text encoded only as pixels;
review screenshots visually and use synthetic fixtures. It prints locations
and categories, never matched values.

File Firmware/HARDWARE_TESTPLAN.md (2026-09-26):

# Hardware Test Plan: PCB V3 First, PCB V4 Second

Successful compiler builds validate interfaces and memory limits, but they do
not replace tests on real hardware. Record each result with the date, firmware
commit, board revision, power source and measurement equipment.

## 1. Station only

1. Upload the station target. Confirm that the upload erases the old flash/NVS
   state and that the `W-Charger-XXXXXX` setup network appears.
2. Connect with `W-Charger-Setup`, open `http://192.168.4.1/` and complete the
   unconfigured portal without a website login. Confirm that its ThingSpeak
   step only asks for the optional User API Key; channel IDs and Read/Write API
   Keys must remain in the later dashboard settings.
3. Enter an invalid home Wi-Fi password before the first successful setup and
   wait through at least two reconnect cycles. The setup access point must
   remain available so the credentials can be corrected.
4. Save valid home Wi-Fi credentials. Confirm that the setup AP switches off
   after connection and that `http://w-charger.local/` or the LAN IP reaches
   the station.
5. Set a website password of at least eight characters. Verify that dashboard,
   configuration, history, Wi-Fi scan and ThingSpeak APIs require login. Check
   that CSRF or cross-origin state-changing requests are rejected and that the
   dashboard, API and Wi-Fi-scan responses include the configured no-cache,
   frame, MIME-sniffing and content-security headers.
6. Log in from two clients. Five failed attempts from one client must trigger a
   30-second block without blocking the other client. Signing out one client
   must invalidate only its server-side session; the other session must remain
   valid. Confirm that an idle session expires after 30 minutes.
7. Restart the station and confirm that settings and local history persist,
   while all previous session cookies no longer authenticate.
8. Generate several simultaneous sensor reports while exercising history and
   settings pages. Every sensor must receive its configuration response within
   its normal response window, and the corresponding latest value and history
   point must still appear after the asynchronous persistence task runs.

## 2. Sensor PCB V3

1. Upload `sensor_pcb_v3`. An unprovisioned sensor must find the station without
   a compiled-in station MAC address or radio channel. Verify this once during
   the fast pairing window and once after it has expired; every discovery wake
   must cover all 13 channels.
2. Confirm that the sensor advertises every ten seconds during the initial
   ten-minute fast-pairing window, but refreshes its sensor/battery snapshot
   only every five minutes. Both the captive setup page and the dashboard's
   pending-sensor list must show **Setup mode**.
3. Compare dashboard temperature and humidity with reference instruments.
4. Measure battery voltage simultaneously with a multimeter. The current V3
   firmware intentionally uses the field-validated base scaling factor 1.67,
   which takes precedence over a nominal schematic ratio. Record the residual
   error before applying any per-sensor calibration.
5. Set the interval to one minute in the web interface. Confirm that
   `appliedRevision` matches the station revision no later than the second
   subsequent contact and that the dashboard changes to **Energy-saving mode**
   only after the sensor reports that mode.
6. Switch the station off during a transmission. The sensor must still power
   down safely, enter deep sleep and retry only at the next configured report
   interval.
   Repeat once after the station has acknowledged the unicast at MAC level but
   before its configuration response is received: the sensor must not scan
   other channels in that wake.
7. Add a sensor while the station is still using its captive-portal setup AP,
   then finish Wi-Fi setup on a different channel. At the next due report, the
   sensor must try its saved setup channel, scan all remaining channels in the
   same wake, receive the station response and persist the new channel. Change
   the router channel again after this transition; steady-state recovery must
   then use at most three rotating channels per scheduled exchange. During a
   received recovery packet, the dashboard must show **Channel recovery** and
   return to **Energy-saving mode** after the next normal report.
8. Queue a sensor factory reset, interrupt the station during its response and
   verify that the command remains pending until the sensor acknowledges the
   matching revision.
9. Delete a configured sensor from the station without resetting its power.
   At its next scheduled known-channel check-in, the station must return
   `provisioned=false`. The sensor must clear the station identity, wake again
   after one second and reappear as an unprovisioned sensor using a complete
   13-channel discovery scan.
10. Upload a new sensor firmware image without erasing NVS manually. The ELF SHA
   change must clear the old station assignment once; another restart with the
   same image must not clear it again.
11. With diagnostic logging enabled for this test only, force a failed unicast
    send and confirm that the next attempt starts without the additional
    260 ms configuration-response timeout. Repeat with broadcast discovery and
    confirm that discovery still retains its response window.

## 3. BME680 and IAQ on PCB V3

1. Connect the BME680 to the switched I2C supply, restart the sensor and verify
   that the add-sensor wizard detects `BME680`. Then select BME680 explicitly
   and initially use a five-minute interval.
2. Temporarily build with `SENSOR_DIAGNOSTIC_LOGGING=1` and check the serial log
   and timing: BSEC must use only `ULP/300 s` from the first start. There must
   be no LP/three-second cycle and no later sample-rate switch. Permanent direct
   raw measurements indicate a fault.
   During the heater/conversion wait, timer Light-sleep must return at the
   expected measurement deadline without resetting I2C or interrupting power
   on GPIO10.
3. The dashboard must show temperature, humidity, pressure, gas resistance and,
   after BSEC learning, Static IAQ. While accuracy is 0, the dashboard must show
   the real elapsed learning time without a fixed-duration progress bar, and
   ThingSpeak must not receive IAQ. When accuracy first reaches 1, the large
   learning notice must disappear permanently and the compact Accuracy badge
   must remain visible during normal operation.
4. Operate the sensor in a normally used room for at least 24 hours and observe
   whether accuracy progresses through 1, 2 and eventually 3. Ventilation
   should improve IAQ with a delay, while ordinary indoor pollution should
   worsen it. Do not expose the sensor directly to liquids or concentrated
   vapours.
5. After reaching accuracy 2 or 3, disconnect the battery briefly. A saved BSEC
   state must load after restart; restarting the complete long-term learning
   process indicates a persistence fault.
6. After thermal equilibrium, compare temperature and humidity with a known
   reference instrument. Change the temperature offset only in small steps and
   evaluate at least three further cycles.
7. Set the reporting interval to 30 minutes. The BME680 must still measure every
   five minutes, while ESP-NOW and ThingSpeak operate only every 30 minutes.
   Include several seconds of awake processing in the test and verify that the
   logical report clock does not postpone transmission by an extra five-minute
   cycle.
8. Alternate between BME680 and BME280 and update the station selection. An
   incorrect explicit type must appear as a read failure/type mismatch;
   **Automatic** must recognize both chip IDs at `0x76` and `0x77`.
9. Measure the sensor rail directly during deep sleep on both PCB V3 and V4; it
   must be 0 V. After at least ten fully power-cycled sensor measurements, IAQ
   learning must continue instead of starting with a fresh algorithm state on
   every wake-up.
10. Reset the IAQ learning state in the wizard. After the next contact,
    accuracy must intentionally restart at 0 and then begin increasing again.
11. Force one BSEC cycle to provide only a direct Bosch raw fallback. The last
    genuine IAQ may remain visible as stale, but it must not create a new
    history point or ThingSpeak upload.

## 4. ThingSpeak

1. Store only the User API Key during initial setup. In the dashboard, load the
   account channels and create a private channel for a sensor.
2. Confirm that channel ID, channel profile and write key remain available
   after a station restart.
3. Map every supported quantity to a unique field and verify its unit and
   destination. Battery voltage is uploaded in volts, gas resistance in ohms
   and pressure in hPa. Fields configured as `Do not upload` must remain empty.
4. Confirm that an HTTP 200 response without a positive entry ID is shown as a
   failure rather than **Connected**.
5. Disconnect the internet for several measurements and restore it. Observe
   `droppedJobs`; the current RAM queue is not persistent across restarts and
   does not guarantee delivery of offline samples.
6. Verify that unprovisioned discovery telemetry and stale BSEC fallback IAQ
   values are never uploaded.
7. After a successful upload, confirm that the overview status remains
   **Connected** while the redundant success message is hidden. A later upload
   or station-connection error must make its warning visible again.

## 5. Local station history

1. Set one BME280 sensor to a 10-minute measurement interval. Confirm that the
   dashboard and `/api/history` report 10-minute steps while retaining at most
   the rolling last 24 hours.
2. Change the same sensor to 20 minutes. Existing recent history should remain,
   be rebucketed to 20-minute steps and survive a station restart.
3. After collecting several 10-minute points, change the interval to two
   minutes. The existing line must remain plotted while new two-minute points
   are appended; cursor inspection alone is not sufficient.
4. Repeat with a second sensor at a different interval and confirm that each
   chart keeps its own step size. Missing measurements must create a visible
   line gap instead of being connected as continuous data.
5. With website protection enabled, confirm that the protected-access banner
   disappears automatically after its initial display. The unprotected warning
   must remain visible when no password is set.

## 6. Sensor energy profile

Before measuring current, verify the configured-mode radio policy:

1. Add a BME280 sensor, wait for the station to acknowledge provisioning and
   select a ten-minute interval. Across three successful cycles, verify that it
   wakes at the configured interval, sends unicast on the saved channel and
   emits neither discovery beacons nor scans on other channels.
2. Power-cycle that sensor without changing its firmware. The persisted
   assignment must keep it in the same energy-saving mode; it must not return
   to ten-second discovery.
3. Repeat with a reporting interval longer than five minutes on a BME680. The
   node may wake every five minutes for BSEC ULP, but ESP-NOW must remain off on
   intermediate wakes and transmit only when the configured report is due.
   On PCB V4, GPIO6 must remain low throughout those intermediate wakes.
4. Delete the sensor or complete its factory reset and verify the opposite:
   ten-second discovery and complete 13-channel scans must resume.
5. Observe `/api/status` for a strong, stationary V4 link. The
   `sensorTxPowerDbm` request may start at 11 dBm and must reduce to 8.5 dBm
   only after eight reports at or above -55 dBm. Attenuate the link: two
   reports at or below -72 dBm must raise one step, while a report at or below
   -82 dBm must raise one step immediately. Packet delivery must continue
   throughout.

Use a power analyser to measure at least 20 cycles of each case:

- wake-up to sensor power-on
- BME280 measurement duration
- BME680 ULP measurement including heater phase
- ESP-NOW transmission on a known channel
- BME680 intermediate cycle without ESP-NOW at a longer reporting interval
- stale-channel recovery scan as the radio worst case
- deep-sleep current
- charge consumed by a normal measurement cycle
- discovery mode during both the ten-second and five-minute phases

Derive runtime only from measured charge per cycle, the battery's measured
usable capacity and self-discharge. Runtime estimates in documentation are not
acceptance values.

## 7. Battery-voltage calibration

1. With USB disconnected, measure the battery simultaneously using a calibrated
   multimeter and the dashboard.
2. Enter the multimeter value in the sensor wizard and save it. The new factor
   must arrive at the next sensor wake-up.
3. Compare again at at least three voltages, for example 4.15 V, 3.70 V and
   3.25 V. One-point calibration may correct gain but must not conceal strong
   non-linearity or an incorrectly populated resistor network.
4. Confirm that the calculated correction factor is rejected outside the
   permitted range of 0.7 to 1.3.
5. Reset calibration to its default and verify that correction factor 1.0000 is
   active again on top of the board-specific base scaling.

## 8. Moving to PCB V4

1. Before assembly, continuity-check GPIO6/`ADC_EN` and
   GPIO10/`SENSOR_PWR_EN` against both schematic and PCB.
2. During sleep, GPIO6 must be low and the battery divider must draw no
   measurable continuous current.
   With a BME680 report interval longer than five minutes, confirm the same on
   every intermediate measurement wake and confirm that a due report still
   contains a valid battery value.
3. GPIO10 is active low on V4: low enables the PMOS sensor rail and high
   disables it.
4. Compare battery voltage near 4.2 V, 3.7 V and 3.2 V. V4 uses 100 kOhm over
   150 kOhm and a base scaling factor of 1.667.
5. Repeat BME280, BME680, discovery, stale-channel recovery and factory-reset
   tests with the `sensor_pcb_v4` target.
6. Perform brownout, USB connect/disconnect and charger/battery switchover
   tests.
7. Use the V4 environment for longer field tests only after pin, voltage,
   polarity and current tests have passed.

## Optimization regression acceptance (2026-09-07)

Run the host checks in `tests/README.md` before flashing. Build success does not
replace these physical acceptance checks. Exercise both V3 and V4, BME280,
BME680 and disabled environmental sensing.

1. Capture battery current, sensor rail, SDA/SCL and V4 ADC enable through a
   complete wake. Verify unchanged settling, stable gate levels during all
   Light-sleeps, no rail glitches/back-powering, and return to the sleep baseline.
2. Compare battery readings with the previous image and a multimeter at several
   cell voltages and calibration factors. Retain the 16-sample rejection test;
   allow the documented at-most-1-mV arithmetic rounding change.
3. Disconnect the environmental sensor and hold I2C/status signals in fault
   states. Confirm bounded acquisition, rail shutdown and normal retry cadence.
   In-flight I2C transactions can finish after the cooperative deadline.
4. With a provisioned BME680 and a one-hour report interval, cold-start while the
   station is off. Confirm that five-minute maintenance wakes do not transmit
   every time and that failed acquisition does not cause one-second wake loops.
5. Pair on the setup AP, then complete home-Wi-Fi setup on a different channel.
   Check full initial recovery, subsequent three-channel rotating recovery,
   stable-channel replies, and recovery when only the application ACK is lost.
6. Inject delayed/missing send callbacks and delayed application responses.
   Verify no overlapping sends or channel change before completion, and that
   valid late replies avoid an unnecessary retry.
7. Load the station with history downloads, configuration changes and HTTPS
   activity while sensors report. Measure receive-to-response latency against
   the sensor's 260-ms response window. Under artificial persistence overload,
   verify `espnow.persistenceDrops` counts discarded oldest events and radio
   replies continue. Confirm no unexpected loss at the supported normal load.
8. Add/delete more than 20 distinct MAC addresses over time (maximum 16 at once).
   Confirm responses continue and inspect `espnow.peerFailures`. Delete and
   re-add a MAC with queued samples; old generations must not repopulate history.
9. Verify interval-dependent 24-hour history, reception-time buckets, restart
   persistence, interval changes and exclusion of stale fallback IAQ. Exercise
   memory pressure and confirm history failure is reported without consuming
   the internal heap reserve needed by radio/TLS.
10. Queue multiple cloud channels: one channel's rate limit must not delay other
    eligible channels. Check per-channel order, transient retries (three maximum),
    permanent errors, overflow and 24-hour expiry during a prolonged outage.
    Inspect original receive timestamps, shared-channel `status` timestamps and
    behavior before NTP synchronization. Account for an uncertain remote commit
    if the HTTP response is lost.
11. Keep a BME680 running through learning and compare accuracy progression,
    fresh IAQ, raw fallback, NVS checkpointing, reset and re-pairing with the
    baseline. Confirm configured report deadlines and ULP maintenance cadence.
12. Verify visible-page refresh and immediate refresh after returning from a
    hidden browser tab. Recheck setup, sensor editing, deletion, calibration
    reset, cloud field mapping and existing login behavior.
13. Only on a controlled supply, test an explicitly selected voltage-guard
    threshold, hysteresis, ADC failure while paused and recovery after charging.
    Default V4 firmware uses 2.8 V entry, 2.95 V recovery and daily battery-only
    reporting. Also verify no sensor startup below threshold, no early retry
    when the station is offline, and a live session stopping on undervoltage.
    See [detailed voltage/accuracy checks](SENSOR_REVIEW.md). The storage experiment must
    retain full channel coverage despite longer discovery intervals.
14. Compare normal `-Os`/80-MHz, `-O2`, 160-MHz and LTO images using integrated
    charge per complete cycle, timing, code size and repeated cold/deep-sleep
    starts. Exercise BSEC and poor RF before selecting another default. Do not
    infer an energy reduction from image size or CPU clock alone.

Keep the existing fresh-install behavior in mind: flashing a new sensor image
clears its assignment/learning state, and station USB uploads erase settings.
Record build environment, battery voltage, sensor, RF conditions, sample count,
mean/tail wake duration and charge for each comparison.
# OTA hardware acceptance

The signed ESP-NOW update implementation requires the V3/V4 fault-injection
checks in [OTA.md](OTA.md#verification), including actual flash identification,
power cuts, trial-boot rollback, low-voltage operation and concurrent telemetry.
Host tests and successful builds do not mark these physical checks as passed.

## LSM6DSOX and energy acceptance

On both PCB revisions, verify I2C identity at 0x6A and 0x6B, axis signs and scale
with known stationary orientations and controlled rotation. Check interval
peaks, FIFO overflow indication and stale-data faults after disconnection.
Exercise 1 s and 5 s reports, short graph windows and CSV summaries; verify the
900-entry RAM limit and restart behavior without subminute history flash writes.

Compare BME280/BME680 charge per reporting cycle and deep-sleep current with
the preceding release under identical supply, interval and RF conditions.
Measure maintenance-only BME680 wakes separately. Confirm sensor rail and V4
ADC shutdown, no normal diagnostic serial activity, and no trial-boot retry
extension after acceptance. Account separately for the added OTA offer query.
A provisioned LSM6DSOX intentionally stays awake; do not apply environmental
battery-life expectations to continuous motion mode. See
[power management](POWER_MANAGEMENT.md) for the audit scope.

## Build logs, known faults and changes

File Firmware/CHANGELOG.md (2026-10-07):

# Firmware change inventory

## 4.3.4 / 40307 — 2026-10-07

This inventory covers changes after commit `1f690bc` (firmware 4.3.1 / 40304)
and [merged PR #30](https://github.com/Ans1S/esp32-c3-iot-sensor-board/pull/30).
Its merge commit `f05381d` is the base for this release. The unpublished local
4.3.2/4.3.3 packages were intermediate checkpoints; 4.3.4 includes their fixes.

### Main improvements

- **More reliable sensor selection:** search both Bosch addresses for the
  explicitly selected type, release the previous bus/rail before replacement,
  and retry a slow module even after a positive initial mismatch. Three bounded
  startup attempts use five-second deep sleeps and prompt station reports.
  Success restores the configured cadence; V4 battery protection takes priority.
- **MAX30102 signal recovery:** independently adjust red/IR LED current, recover
  weak IR contact signals, permit pulse estimation with dim red, and retain more
  of slow small pulsations. Gain changes require new FIFO frames and a complete
  estimation window. No SpO2 or clinical accuracy claim; SW2 remains required.
- **Stable saved graphs:** wait for synchronization, load the complete selected
  recording before drawing, and retain the graph/cursor during status polling.
  Users can explicitly open an available partial snapshot or reload it. Full
  recording/minute navigation uses cached samples; CSV exports original data.
- **Durable configuration and storage:** acknowledge settings only after
  persistence succeeds, validate migration identities/complete reads, retain
  retryable cache state, preserve nonblank mount failures, and commit reset
  results before acknowledging commands.
- **Clearer station operation:** normal USB updates preserve settings/archives;
  only the factory-reset environment erases flash. Names and motion references
  survive removal/re-pairing. Pending sensor changes do not reuse old values or
  errors. BME280 omits IAQ/gas tiles; setup notices disappear after five seconds.
- **Safer publication:** remap compiler paths before building release binaries,
  withdraw older path-bearing binaries from the current tree, and check staged,
  pushed and historical blobs plus ZIP contents with redacted findings.

### Additional corrections

| Area | Changes |
| --- | --- |
| BME680 | Start periodic learning-state persistence even at accuracy zero; validate restored state/metadata, clear rejected readiness/retained IAQ, require fresh valid IAQ and stable raw heater/gas results, and avoid double clock-wrap adjustment. |
| LSM6DSOX | Reject stale FIFO backlog after long scheduling gaps, retain explicit gaps, validate maximum FIFO counts and reinitialize after bus faults. |
| Live acquisition | Cancel in-flight initialization/read safely on stop/profile changes; use an independent normal cadence and release the rail between normal windows. |
| Battery telemetry | Replace cached battery capability/failure flags together with voltage; keep V4 strict 2800/2950 mV hysteresis and 24-hour protection deep sleep. |
| Sensor settings | Check NVS migration version/identity, partial reads, durable revision/reset ordering and failed reset recovery; clear obsolete pairing snapshots after measurement changes. |
| Recording lifecycle | Freeze duration on first stop, make repeated stops idempotent, use the actual monotonic request time for late UTC anchoring, and match current request sequences for replay ACKs. |
| Recording archive | Serialize complete chunked JSON pages with real ArduinoJson, preserve unreadable/torn tails correctly, deduplicate durable appends and clamp finite extreme values before compact conversion. |
| Station registry | Validate telemetry semantics, preserve durable settings across failed/interleaved writes, remember MAC identities/references independently of pairing slots, and invalidate stale cloud jobs by generation. |
| Radio | Correlate configuration/recording responses with the active sequence and retain bounded recovery, existing V5 environmental lengths and trial-boot handling. |
| HTTP inputs | Require complete bounded decimal input before narrowing MAC/PCB/channel/field/interval/reset settings; reject non-finite and invalid ranges. |
| Browser forms | Preserve discovery drafts/focus; serialize discovery, save and export actions; keep immutable form snapshots and ignore delayed responses after reopening a form. |
| Browser recovery | Retry failed startup configuration, distinguish missing readings from zero, hide invalid IAQ advice, and show storage/connection failures. |
| Charts/export | Retain gaps and exact raw cursor/CSV values, optional display smoothing, readable sparse plots and XYZ overlays; cancel exports without retaining bandwidth reservations. |
| OTA | Use the actual `0x140000` sensor slot limit in manifest/package/browser validation; reject oversized signed images, rejected headers and file-selection races. Preserve the trusted installation key and rollback policy. |
| Release tooling | Supply V3/V4 4.3.4 signed packages and an application-only station image, verified payloads/identities/signatures and SHA-256 checksums; keep local keys/agent files/build outputs ignored. |
| Documentation | Refresh all six public READMEs, precision/recording/timing/power/architecture/OTA guides, reliability and MAX30102 investigations, and publication/change records. Local agent instructions and a project release skill remain unpublished. |
| Regression coverage | Expand to 22 production C++ suites, six real embedded-page Playwright suites, six cryptographic OTA tests, two upload-preservation tests, three library-patch checks and publication-guard regressions. |

### Compatibility and validation

Protocol V5 and the recording layout remain unchanged. Update the station for
dashboard/storage changes and the nodes for driver/recovery changes. Older
layouts still require the [one-time USB migration](RECORDINGS.md#one-time-usb-migration).
The station application is written at `0x10000`; it is not a sensor OTA package
or a factory image. See [current release files](releases/README.md).

The three PlatformIO targets and the documented host/browser/package checks
pass. No board was flashed. Physical accuracy, module replacement, RF/power-loss
behavior, sleep current, cutoff calibration and the reported BME280 low-voltage
hardware failure still require bench measurements. See
[reliability evidence](RELIABILITY_REVIEW.md), [MAX30102 research](MAX30102_REVIEW.md)
and [publication scope and historical limitations](PUBLICATION_REVIEW.md).

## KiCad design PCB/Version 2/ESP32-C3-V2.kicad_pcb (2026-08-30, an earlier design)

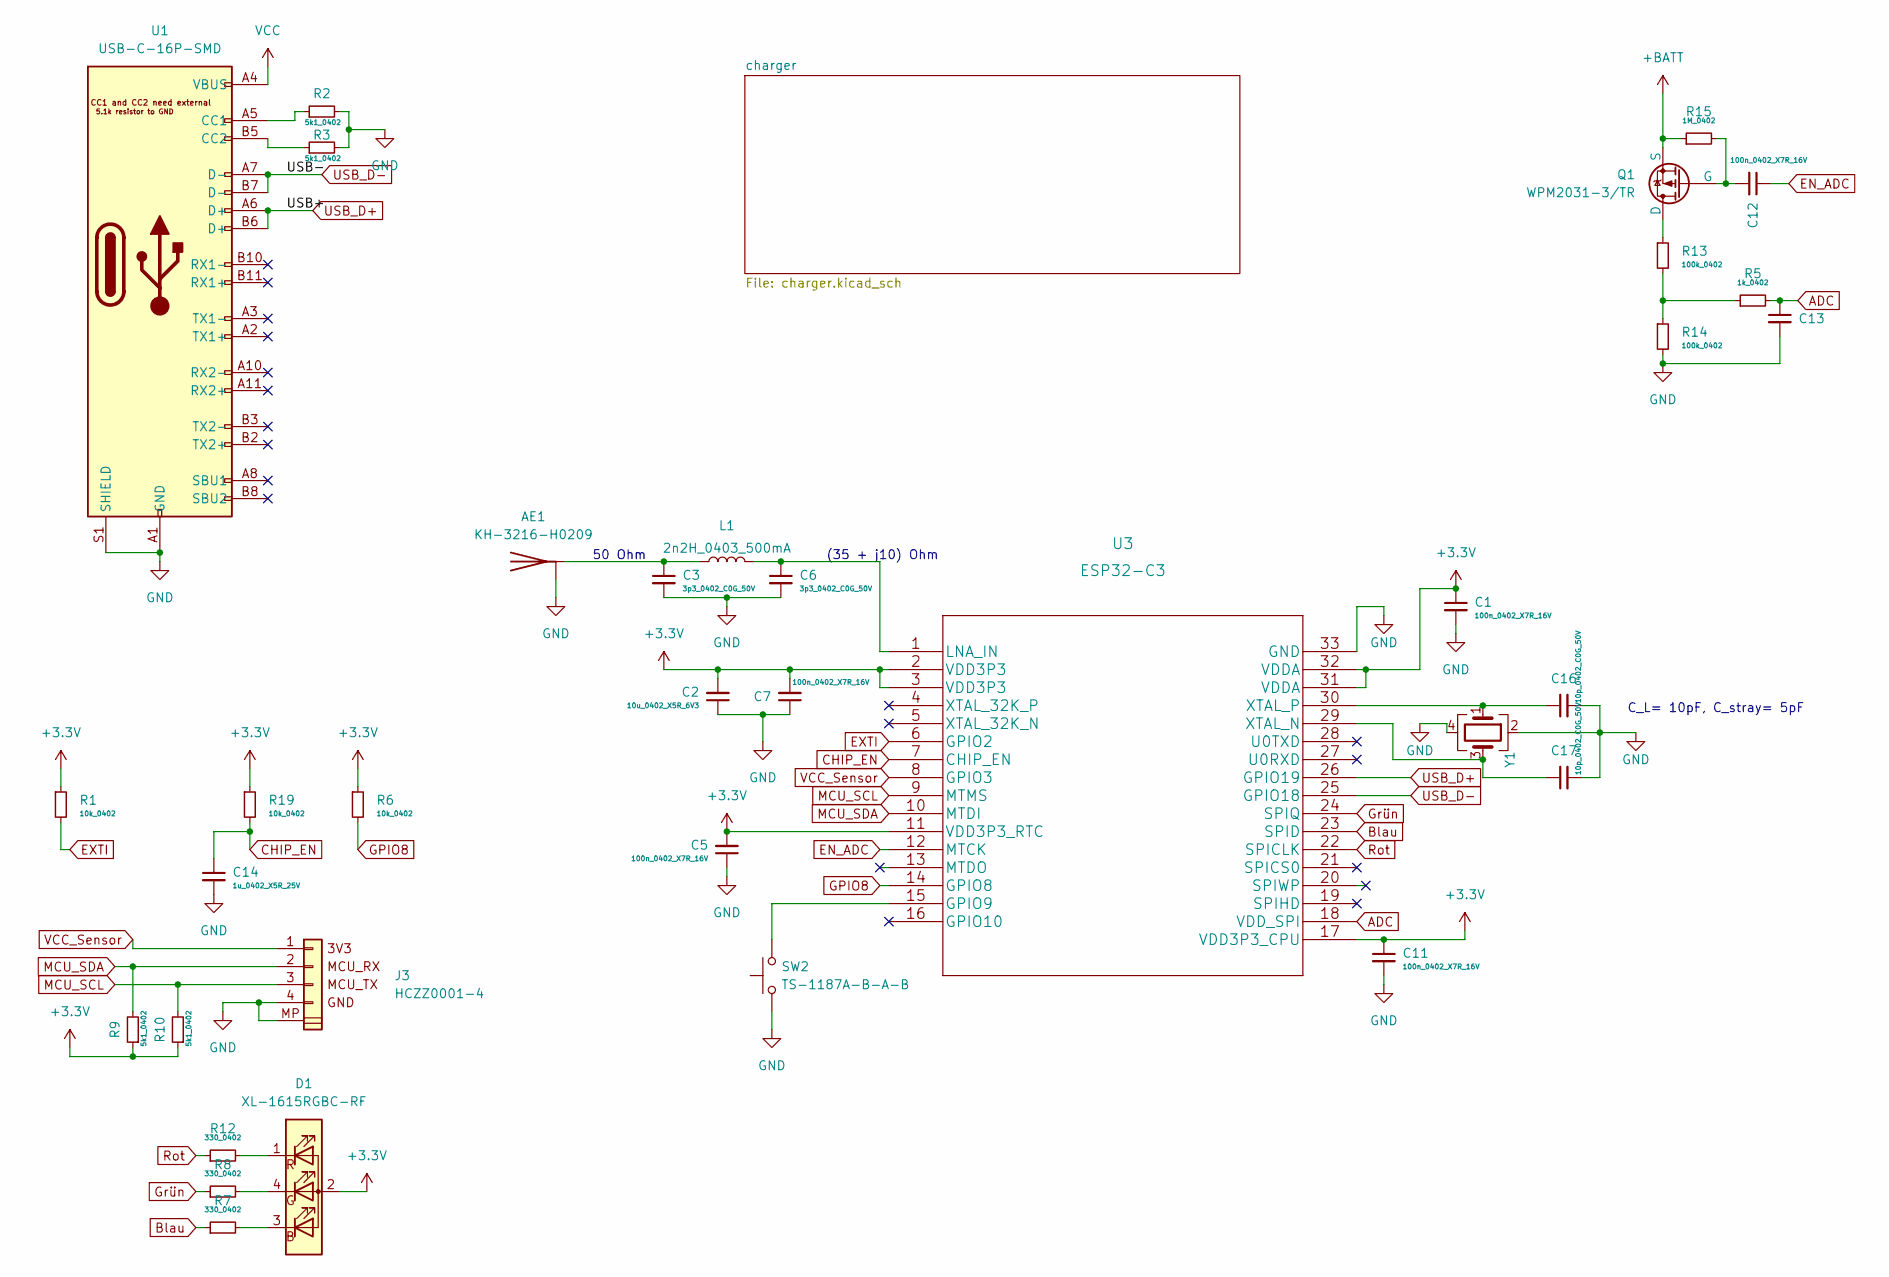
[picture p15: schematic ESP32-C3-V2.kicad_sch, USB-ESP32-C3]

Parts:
AE1: KH-3216-H0209; Texas_SWRA117D_2.4GHz_Left; LCSC C2925417
C1, C5, C7, C11, C12, C13: 100n_0402_X7R_16V; C_0402_1005Metric; LCSC C1525
C2: 10u_0402_X5R_6V3; C_0402_1005Metric; LCSC C15525
C3, C6: 3p3_0402_C0G_50V; C_0402_1005Metric; LCSC C1565
C14: 1u_0402_X5R_25V; C_0402_1005Metric; LCSC C52923
C16, C17: 10p_0402_C0G_50V; C_0402_1005Metric; LCSC C1634
D1: XL-1615RGBC-RF; LED_0606_1432_correct; LCSC C965840
J3: HCZZ0001-4; JST_GH_SM04B-GHS-TB_1x04-1MP_P1.25mm_Horizontal; LCSC C7433455
L1: 2n2H_0403_500mA; R_0402_1005Metric; LCSC C76790
Q1: WPM2031-3/TR; SOT-723; LCSC C240201
R1, R6, R19: 10k_0402; R_0402_1005Metric; Voltage 50V; LCSC C25744
R2, R3, R9, R10: 5k1_0402; R_0402_1005Metric; Voltage 50V; LCSC C25905
R5: 1k_0402; R_0402_1005Metric; Voltage 50V; LCSC C11702
R7, R8, R12: 330_0402; R_0402_1005Metric; Voltage 50V; LCSC C25104
R13, R14: 100k_0402; R_0402_1005Metric; Voltage 50V; LCSC C25741
R15: 1M_0402; R_0402_1005Metric; Voltage 50V; LCSC C26083
SW2: TS-1187A-B-A-B; SW_SPST_TL3305B; LCSC C318884
U1: USB-C-16P-SMD; USB-C-MC-311D; Partnumber SOFNG MC-311D; LCSC C136423
U3: ESP32-C3; QFN-32-1EP_5x5mm_P0.5mm_EP3.7x3.7mm; LCSC C2858491
Y1: 40MHz_S3240000151040; Crystal_SMD_3225-4Pin_3.2x2.5mm; LCSC C5261247

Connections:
+3.3V: C1.1, C2.2, C5.2, C7.2, C11.1, D1.2 (A), R1.1, R6.1, R9.1, R10.1, R19.1, U3.2 (VDD3P3), U3.3 (VDD3P3), U3.11 (VDD3P3_RTC), U3.17 (VDD3P3_CPU), U3.31 (VDDA), U3.32 (VDDA); also elsewhere on the board
+BATT: Q1.2 (S), R15.1; also elsewhere on the board
ADC: C13.1, R5.2, U3.18 (VDD_SPI)
Blau: R7.1, U3.23 (SPID)
CHIP_EN: C14.1, R19.2, U3.7 (CHIP_EN)
EN_ADC: C12.1, U3.12 (MTCK)
EXTI: R1.2, U3.6 (GPIO2)
GND: AE1.2 (GND), C1.2, C2.1, C3.2, C5.1, C6.2, C7.1, C11.2, C13.2, C14.2, C16.2, C17.2, J3.4, J3.MP, R2.2, R3.2, R14.2, SW2.1, U1.A1 (GND), U1.A12 (GND), U1.B1 (GND), U1.B12 (GND), U1.S1 (SHIELD), U3.33 (GND), Y1.2 (GND), Y1.4 (GND); also elsewhere on the board
GPIO8: R6.2, U3.14 (GPIO8)
Grün: R8.1, U3.24 (SPIQ)
MCU_SCL: J3.3, R10.2, U3.9 (MTMS)
MCU_SDA: J3.2, R9.2, U3.10 (MTDI)
unnamed: AE1.1 (A), C3.1, L1.1
unnamed: D1.3 (BK), R7.2
unnamed: D1.4 (GK), R8.2
unnamed: D1.1 (RK), R12.2
unnamed: Q1.3 (D), R13.1
unnamed: C12.2, Q1.1 (G), R15.2
unnamed: R5.1, R13.2, R14.1
unnamed: R2.1, U1.A5 (CC1)
unnamed: R3.1, U1.B5 (CC2)
unnamed: SW2.2, U3.15 (GPIO9)
unnamed: C6.1, L1.2, U3.1 (LNA_IN)
unnamed: C17.1, U3.29 (XTAL_N), Y1.3 (OSC2)
unnamed: C16.1, U3.30 (XTAL_P), Y1.1 (OSC1)
Rot: R12.1, U3.22 (SPICLK)
USB_D+: U1.A6 (D+), U1.B6 (D+), U3.26 (GPIO19)
USB_D-: U1.A7 (D-), U1.B7 (D-), U3.25 (GPIO18)
VCC: U1.A4 (VBUS), U1.A9 (VBUS), U1.B4 (VBUS), U1.B9 (VBUS); also elsewhere on the board
VCC_Sensor: J3.1, U3.8 (GPIO3)

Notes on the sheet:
50 Ohm
(35 + j10) Ohm
C_L= 10pF, C_stray= 5pF

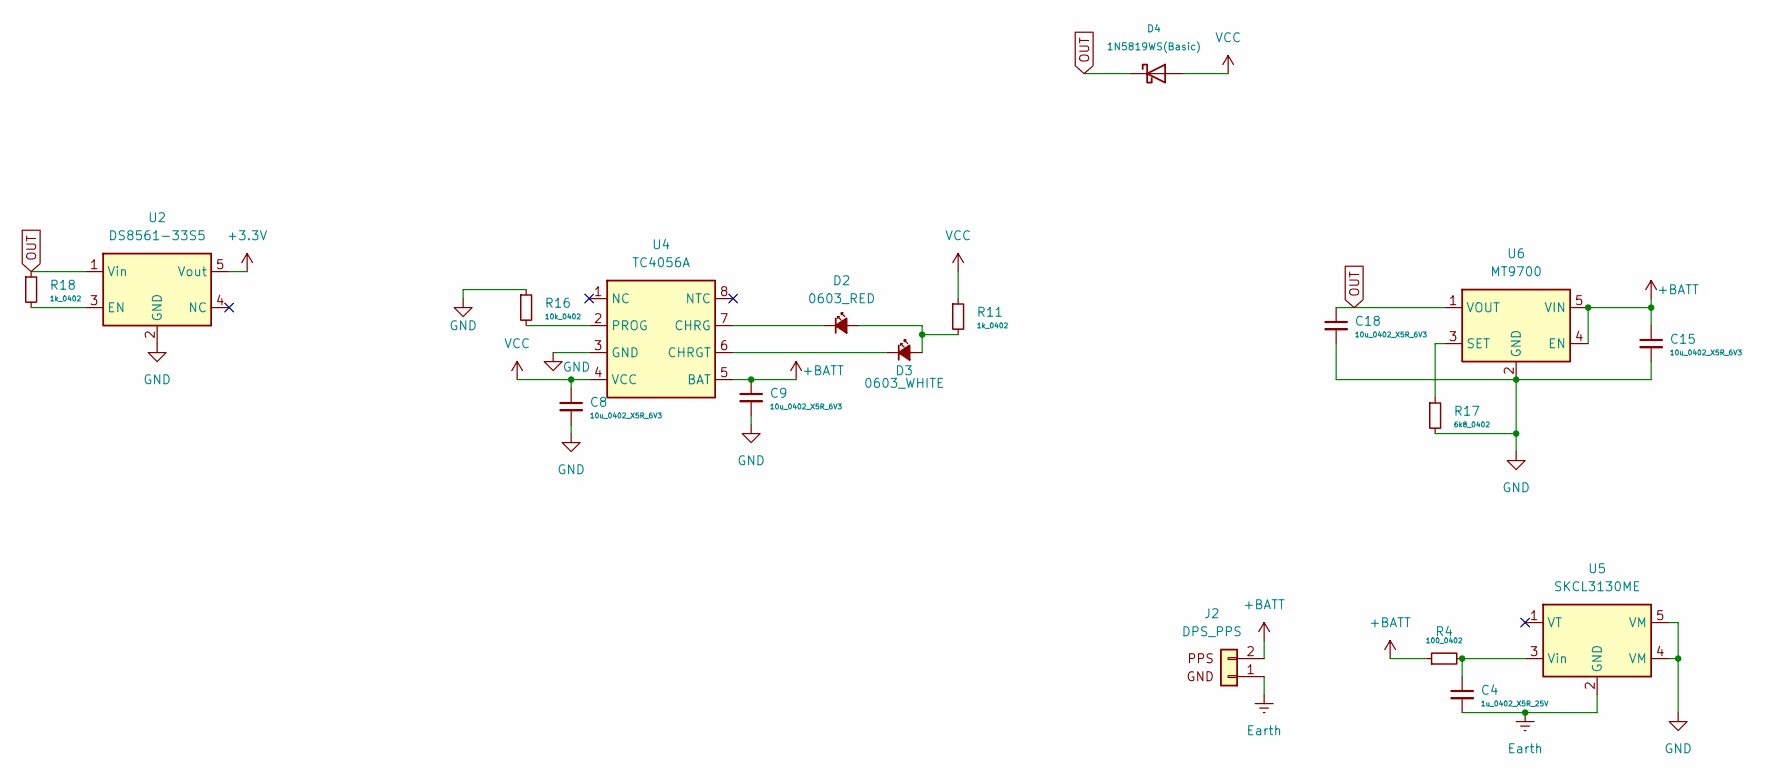
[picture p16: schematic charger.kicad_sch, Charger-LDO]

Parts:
C4: 1u_0402_X5R_25V; C_0402_1005Metric; LCSC C52923
C8, C9, C15, C18: 10u_0402_X5R_6V3; C_0402_1005Metric; LCSC C15525
D2: 0603_RED; LED_0603_1608Metric; Partnumber KT-0603R; LCSC C2286
D3: 0603_WHITE; LED_0603_1608Metric; Partnumber 19-217/GHC-YR1S2/3T; LCSC C2290
D4: 1N5819WS(Basic); D_SOD-323_HandSoldering; LCSC C191023
J2: DPS_PPS; JST_PH_B2B-PH-K_1x02_P2.00mm_Vertical; LCSC C722767
R4: 100_0402; R_0402_1005Metric; Voltage 50V; LCSC C25076
R11, R18: 1k_0402; R_0402_1005Metric; Voltage 50V; LCSC C11702
R16: 10k_0402; R_0402_1005Metric; Voltage 50V; LCSC C25744
R17: 6k8_0402; R_0402_1005Metric; Voltage 50V; LCSC C25917
U2: DS8561-33S5; SOT-23-5; LCSC C5795637
U4: TC4056A; SOP-8_3.9x4.9mm_P1.27mm; LCSC C7588528
U5: SKCL3130ME; SOT-23-5; LCSC C2941741
U6: MT9700; SOT-23-5; LCSC C89855

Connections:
+3.3V: U2.5 (Vout); also elsewhere on the board
+BATT: C9.1, C15.1, J2.2, R4.1, U4.5 (BAT), U6.4 (EN), U6.5 (VIN); also elsewhere on the board
Earth: C4.2, J2.1, U5.2 (GND)
GND: C8.2, C9.2, C15.2, C18.2, R16.1, R17.2, U2.2 (GND), U4.3 (GND), U5.4 (VM), U5.5 (VM), U6.2 (GND); also elsewhere on the board
unnamed: D2.2 (A), D3.2 (A), R11.2
unnamed: D2.1 (K), U4.7 (CHRG)
unnamed: D3.1 (K), U4.6 (CHRGT)
unnamed: R18.2, U2.3 (EN)
unnamed: R16.2, U4.2 (PROG)
unnamed: C4.1, R4.2, U5.3 (Vin)
unnamed: R17.1, U6.3 (SET)
OUT: C18.1, D4.1 (K), R18.1, U2.1 (Vin), U6.1 (VOUT)
VCC: C8.1, D4.2 (A), R11.1, U4.4 (VCC); also elsewhere on the board

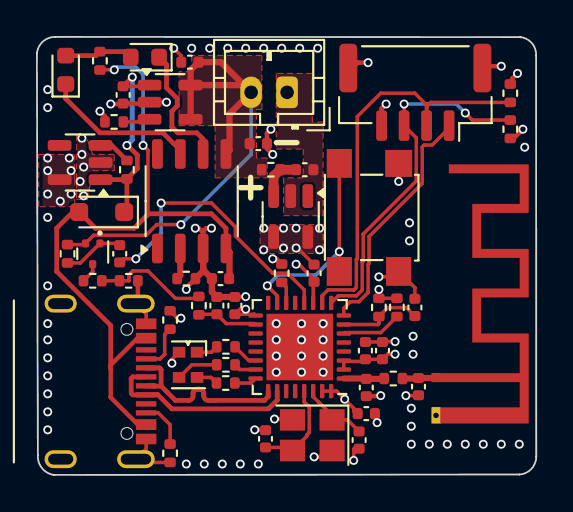
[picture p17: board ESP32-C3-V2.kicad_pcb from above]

Board: 4 copper layers, 27.7 x 24.3 mm, 53 parts (0 on the bottom side), 39 nets.

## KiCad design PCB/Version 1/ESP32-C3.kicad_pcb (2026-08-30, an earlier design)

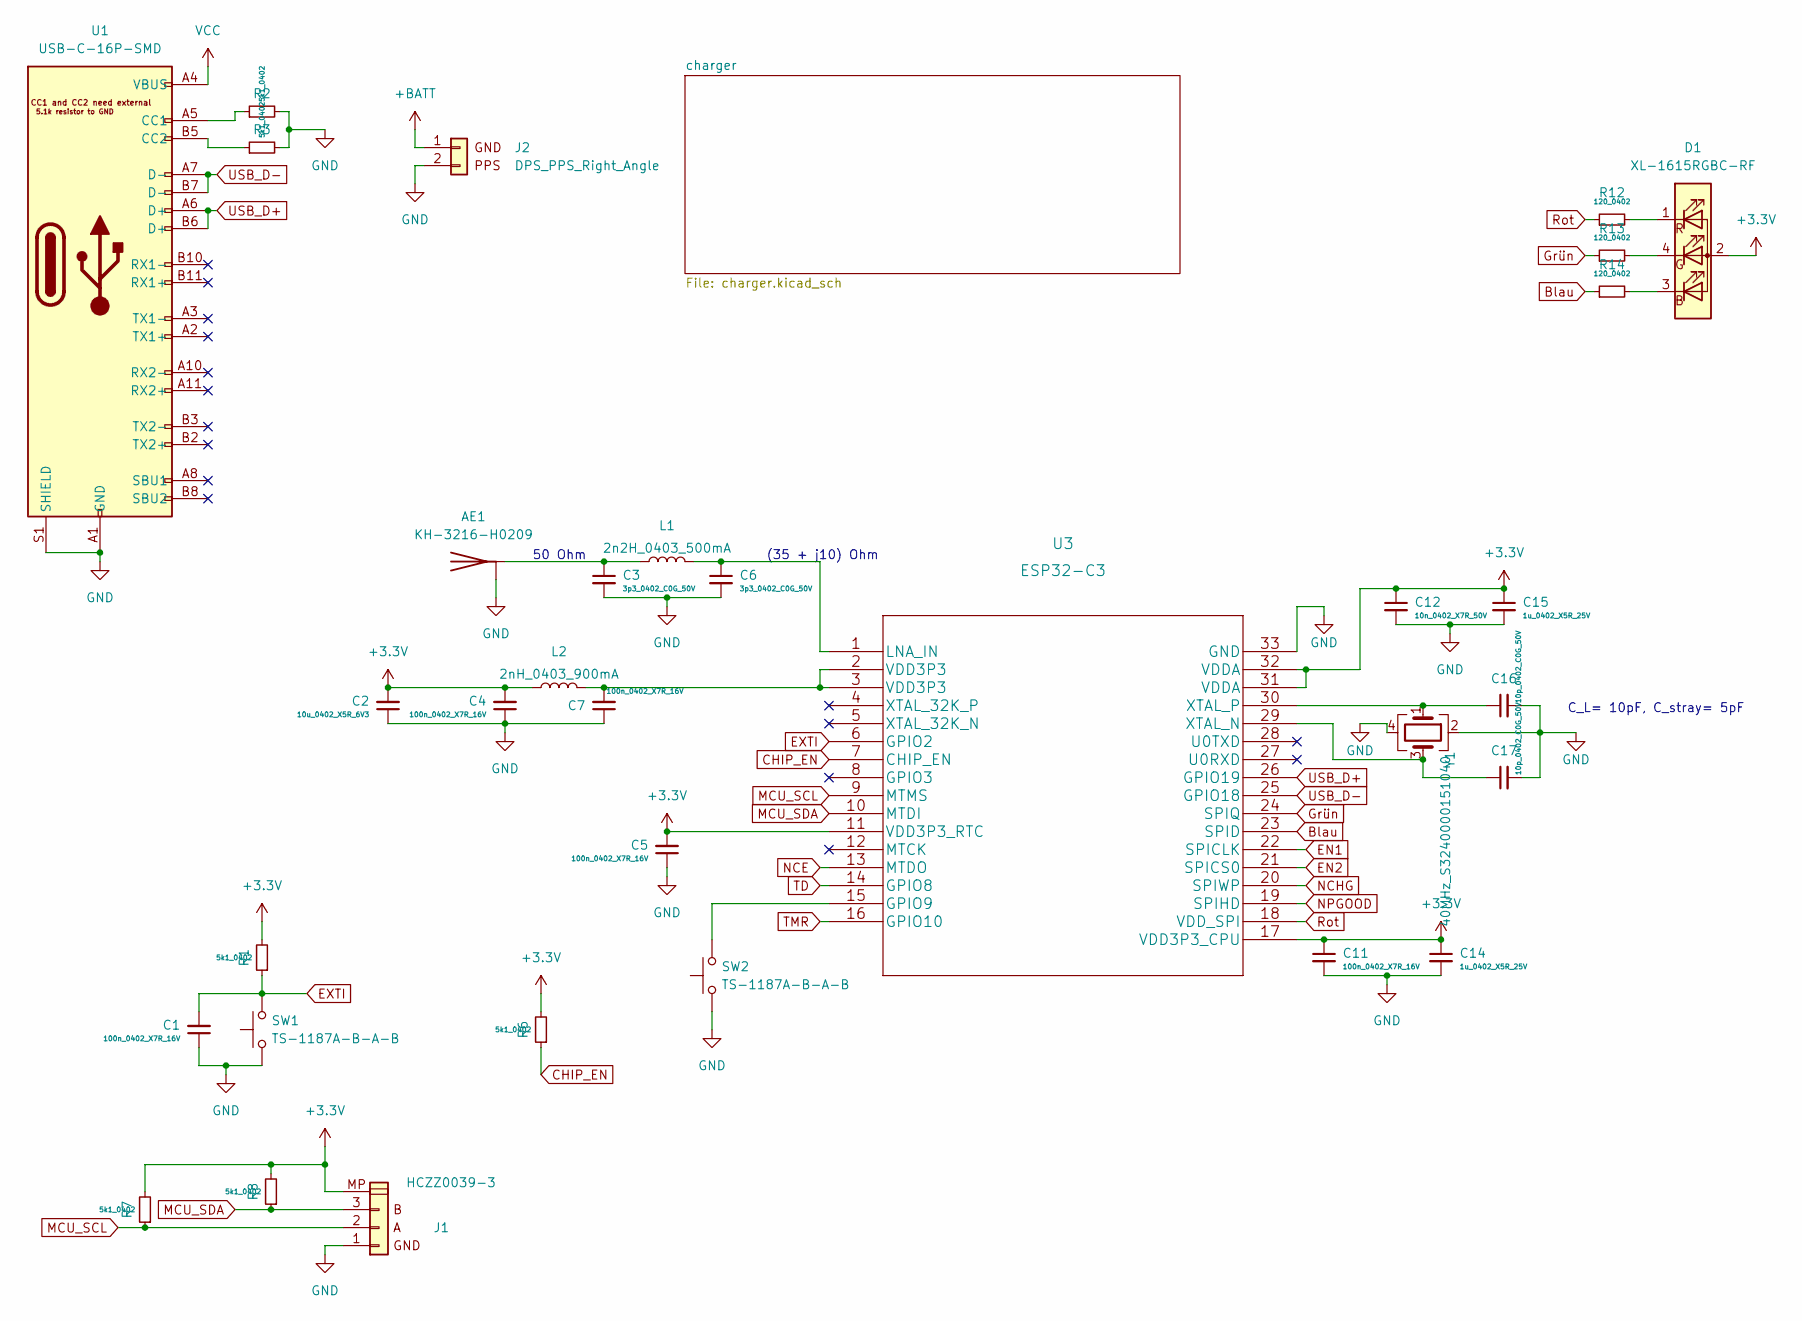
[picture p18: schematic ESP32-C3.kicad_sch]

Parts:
AE1: KH-3216-H0209; Texas_SWRA117D_2.4GHz_Left; LCSC C2925417
C1, C4, C5, C7, C11: 100n_0402_X7R_16V; C_0402_1005Metric; LCSC C1525
C2: 10u_0402_X5R_6V3; C_0402_1005Metric; LCSC C15525
C3, C6: 3p3_0402_C0G_50V; C_0402_1005Metric; LCSC C1565
C12: 10n_0402_X7R_50V; C_0402_1005Metric; LCSC C15195
C14, C15: 1u_0402_X5R_25V; C_0402_1005Metric; LCSC C52923
C16, C17: 10p_0402_C0G_50V; C_0402_1005Metric; LCSC C1634
D1: XL-1615RGBC-RF; LED_0606_1432_correct; LCSC C965840
J1: HCZZ0039-3; JST_SH_SM03B-SRSS-TB_1x03-1MP_P1.00mm_Horizontal; LCSC C7433424
J2: DPS_PPS_Right_Angle; JST_PH_S2B-PH-K_1x02_P2.00mm_Horizontal; LCSC C7465576
L1: 2n2H_0403_500mA; R_0402_1005Metric; LCSC C76790
L2: 2nH_0403_900mA; R_0402_1005Metric; LCSC C18216
R1, R2, R3, R6, R7, R8: 5k1_0402; R_0402_1005Metric; Voltage 50V; LCSC C25905
R12, R13, R14: 120_0402; R_0402_1005Metric; Voltage 50V; LCSC C25079
SW1, SW2: TS-1187A-B-A-B; SW_SPST_TL3305B; LCSC C318884
U1: USB-C-16P-SMD; USB-C-MC-311D; Partnumber SOFNG MC-311D; LCSC C136423
U3: ESP32-C3; QFN-32-1EP_5x5mm_P0.5mm_EP3.7x3.7mm; LCSC C2858491
Y1: 40MHz_S3240000151040; Crystal_SMD_3225-4Pin_3.2x2.5mm; LCSC C5261247

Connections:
+3.3V: C2.2, C4.2, C5.2, C11.1, C12.1, C14.1, C15.1, D1.2 (A), J1.MP, L2.1, R1.2, R6.2, R7.2, R8.2, U3.11 (VDD3P3_RTC), U3.17 (VDD3P3_CPU), U3.31 (VDDA), U3.32 (VDDA); also elsewhere on the board
+BATT: J2.1; also elsewhere on the board
Blau: R14.1, U3.23 (SPID)
CHIP_EN: R6.1, U3.7 (CHIP_EN)
EN1: U3.22 (SPICLK); also elsewhere on the board
EN2: U3.21 (SPICS0); also elsewhere on the board
EXTI: C1.2, R1.1, SW1.2, U3.6 (GPIO2)
GND: AE1.2 (GND), C1.1, C2.1, C3.2, C4.1, C5.1, C6.2, C7.1, C11.2, C12.2, C14.2, C15.2, C16.2, C17.2, J1.1, J2.2, R2.2, R3.2, SW1.1, SW2.1, U1.A1 (GND), U1.A12 (GND), U1.B1 (GND), U1.B12 (GND), U1.S1 (SHIELD), U3.33 (GND), Y1.2 (GND), Y1.4 (GND); also elsewhere on the board
Grün: R13.1, U3.24 (SPIQ)
MCU_SCL: J1.2, R7.1, U3.9 (MTMS)
MCU_SDA: J1.3, R8.1, U3.10 (MTDI)
NCE: U3.13 (MTDO); also elsewhere on the board
NCHG: U3.20 (SPIWP); also elsewhere on the board
NPGOOD: U3.19 (SPIHD); also elsewhere on the board
unnamed: AE1.1 (A), C3.1, L1.1
unnamed: C7.2, L2.2, U3.2 (VDD3P3), U3.3 (VDD3P3)
unnamed: D1.3 (BK), R14.2
unnamed: D1.4 (GK), R13.2
unnamed: D1.1 (RK), R12.2
unnamed: R2.1, U1.A5 (CC1)
unnamed: R3.1, U1.B5 (CC2)
unnamed: SW2.2, U3.15 (GPIO9)
unnamed: C6.1, L1.2, U3.1 (LNA_IN)
unnamed: C17.1, U3.29 (XTAL_N), Y1.3 (OSC2)
unnamed: C16.1, U3.30 (XTAL_P), Y1.1 (OSC1)
Rot: R12.1, U3.18 (VDD_SPI)
TD: U3.14 (GPIO8); also elsewhere on the board
TMR: U3.16 (GPIO10); also elsewhere on the board
USB_D+: U1.A6 (D+), U1.B6 (D+), U3.26 (GPIO19)
USB_D-: U1.A7 (D-), U1.B7 (D-), U3.25 (GPIO18)
VCC: U1.A4 (VBUS), U1.A9 (VBUS), U1.B4 (VBUS), U1.B9 (VBUS); also elsewhere on the board

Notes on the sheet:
50 Ohm
(35 + j10) Ohm
C_L= 10pF, C_stray= 5pF

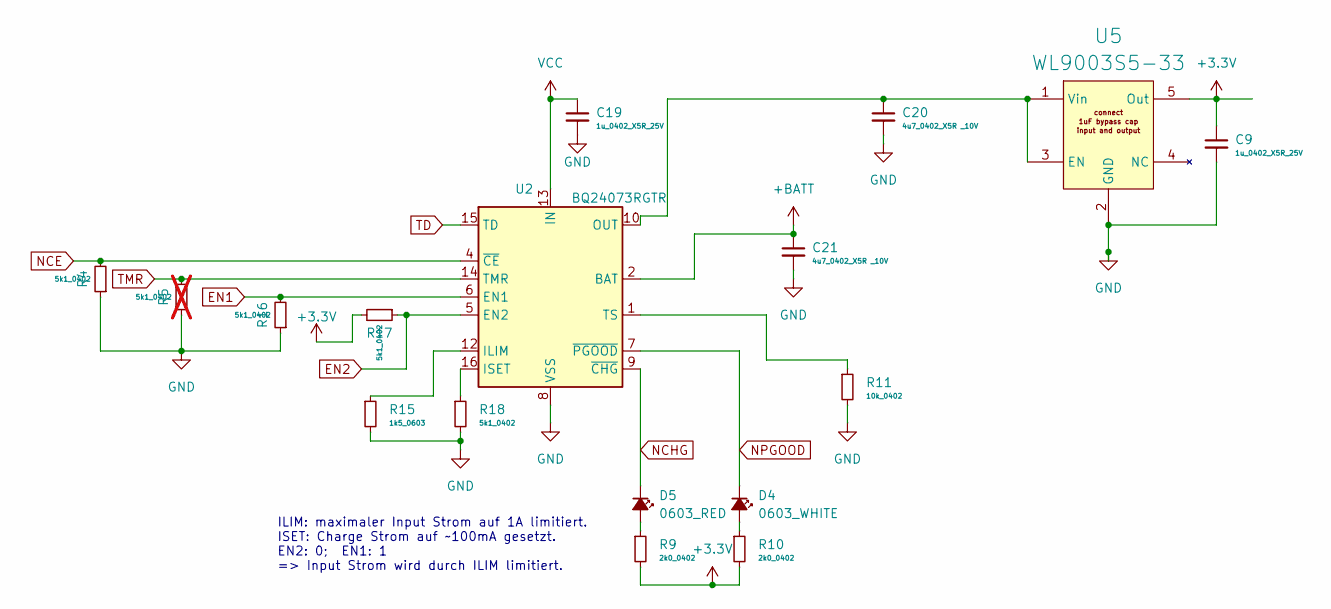
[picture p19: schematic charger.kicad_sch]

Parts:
C9, C19: 1u_0402_X5R_25V; C_0402_1005Metric; LCSC C52923
C20, C21: 4u7_0402_X5R _10V; C_0402_1005Metric; LCSC C23733
D4: 0603_WHITE; LED_0603_1608Metric; Partnumber 19-217/GHC-YR1S2/3T; LCSC C2290
D5: 0603_RED; LED_0603_1608Metric; Partnumber KT-0603R; LCSC C2286
R4, R16, R17: 5k1_0402; R_0402_1005Metric; Voltage 50V; LCSC C25905
R5: 5k1_0402; R_0402_1005Metric; Voltage 50V; LCSC C25905; not fitted
R9, R10: 2k0_0402; R_0402_1005Metric; Voltage 50V; LCSC C4109
R11: 10k_0402; R_0402_1005Metric; Voltage 50V; LCSC C25744
R15: 1k5_0603; R_0603_1608Metric; Voltage 75V; LCSC C22843
R18: 5k1_0402; R_0402_1005Metric; LCSC C25905
U2: BQ24073RGTR; VQFN-16-1EP_3x3mm_P0.5mm_EP1.6x1.6mm; LCSC C15220
U5: WL9003S5-33; SOT-23-5; LCSC C2688245

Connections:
+3.3V: C9.1, R9.2, R10.2, R17.2, U5.5 (Out); also elsewhere on the board
+BATT: C21.1, U2.2 (BAT), U2.3 (BAT); also elsewhere on the board
EN1: R16.2, U2.6 (EN1); also elsewhere on the board
EN2: R17.1, U2.5 (EN2); also elsewhere on the board
GND: C9.2, C19.2, C20.2, C21.2, R4.1, R5.1, R11.2, R15.2, R16.1, R18.2, U2.8 (VSS), U2.17 (VSS), U5.2 (GND); also elsewhere on the board
NCE: R4.2, U2.4 (~CE); also elsewhere on the board
NCHG: D5.1 (K), U2.9 (~CHG); also elsewhere on the board
NPGOOD: D4.1 (K), U2.7 (~PGOOD); also elsewhere on the board
unnamed: D4.2 (A), R10.1
unnamed: D5.2 (A), R9.1
unnamed: R15.1, U2.12 (ILIM)
unnamed: R18.1, U2.16 (ISET)
unnamed: R11.1, U2.1 (TS)
unnamed: C20.1, U2.10 (OUT), U2.11 (OUT), U5.1 (Vin), U5.3 (EN)
TD: U2.15 (TD); also elsewhere on the board
TMR: R5.2, U2.14 (TMR); also elsewhere on the board
VCC: C19.1, U2.13 (IN); also elsewhere on the board

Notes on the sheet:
ILIM: maximaler Input Strom auf 1A limitiert. ISET: Charge Strom auf ~100mA gesetzt. EN2: 0; EN1: 1 => Input Strom wird durch ILIM limitiert.

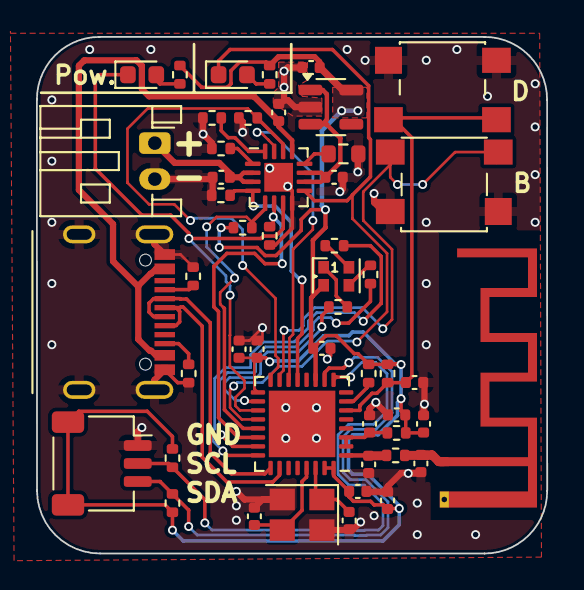
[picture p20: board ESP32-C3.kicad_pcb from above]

Board: 2 copper layers, 28.3 x 28.7 mm, 50 parts (0 on the bottom side), 37 nets.

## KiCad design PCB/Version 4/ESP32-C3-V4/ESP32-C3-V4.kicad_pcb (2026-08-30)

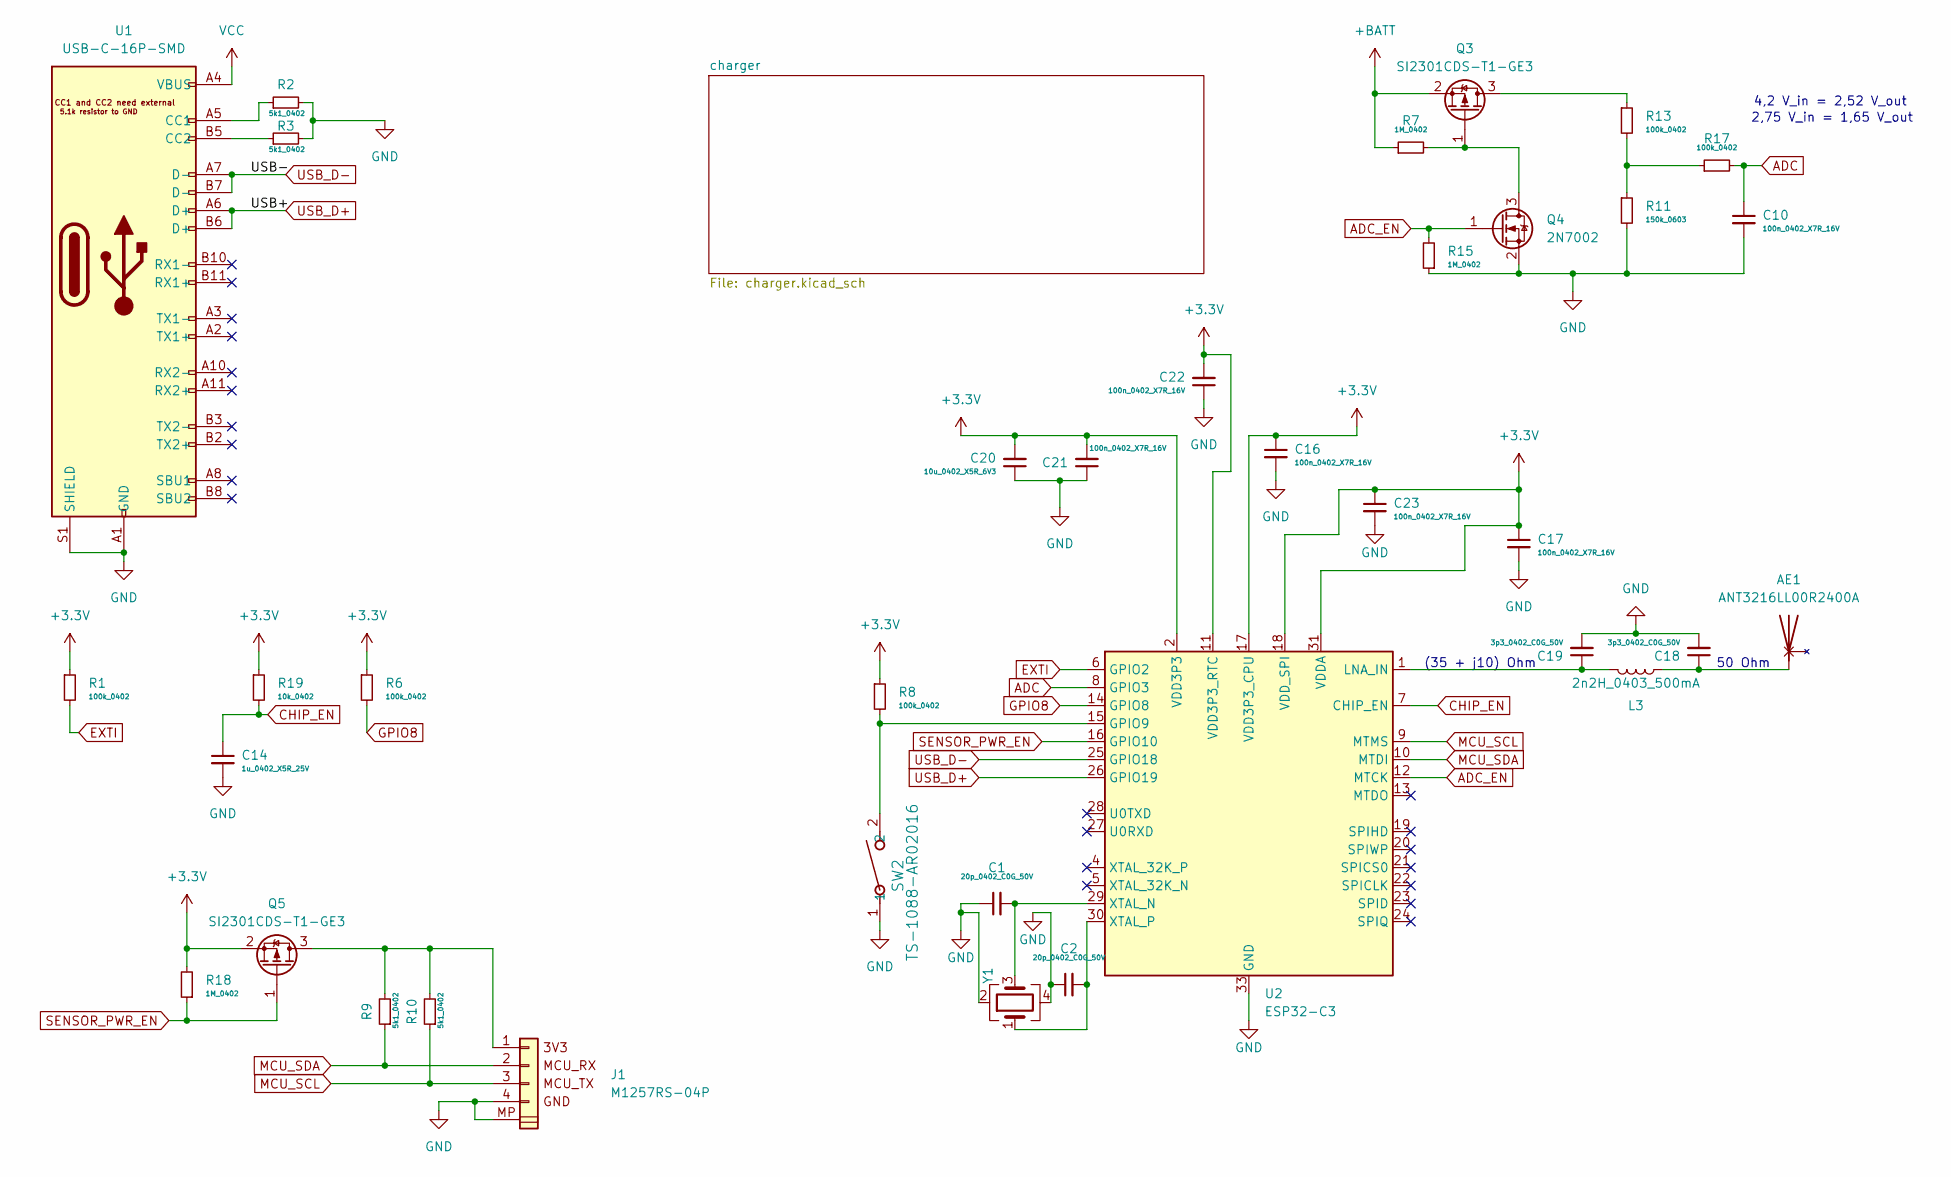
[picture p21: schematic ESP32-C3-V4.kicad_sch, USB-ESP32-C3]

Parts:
AE1: ANT3216LL00R2400A; R_1206_3216Metric; LCSC C293767
C1, C2: 20p_0402_C0G_50V; C_0402_1005Metric; LCSC C1554
C10, C16, C17, C21, C22, C23: 100n_0402_X7R_16V; C_0402_1005Metric; LCSC C1525
C14: 1u_0402_X5R_25V; C_0402_1005Metric; LCSC C52923
C18, C19: 3p3_0402_C0G_50V; C_0402_1005Metric; LCSC C1565
C20: 10u_0402_X5R_6V3; C_0402_1005Metric; LCSC C15525
J1: M1257RS-04P; JST_GH_SM04B-GHS-TB_1x04-1MP_P1.25mm_Horizontal; LCSC C2939383
L3: 2n2H_0403_500mA; R_0402_1005Metric; LCSC C76790
Q3, Q5: SI2301CDS-T1-GE3; SOT-23; LCSC C10487
Q4: 2N7002; SOT-23; LCSC C8545
R1, R6, R8, R13, R17: 100k_0402; R_0402_1005Metric; Voltage 50V; LCSC C25741
R2, R3, R9, R10: 5k1_0402; R_0402_1005Metric; Voltage 50V; LCSC C25905
R7, R15, R18: 1M_0402; R_0402_1005Metric; Voltage 50V; LCSC C26083
R11: 150k_0603; R_0603_1608Metric; LCSC C22807
R19: 10k_0402; R_0402_1005Metric; Voltage 50V; LCSC C25744
SW2: TS-1088-AR02016; SW_TS-1088_XNP; LCSC C720477
U1: USB-C-16P-SMD; USB-C-MC-311D; Partnumber SOFNG MC-311D; LCSC C136423
U2: ESP32-C3; QFN-32-1EP_5x5mm_P0.5mm_EP3.7x3.7mm; LCSC C2858491
Y1: 40MHz_S3240000151040; Crystal_SMD_3225-4Pin_3.2x2.5mm; LCSC C426990

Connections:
+3.3V: C16.1, C17.1, C20.2, C21.2, C22.2, C23.1, Q5.2 (S), R1.1, R6.1, R8.1, R18.2, R19.1, U2.2 (VDD3P3), U2.3 (VDD3P3), U2.11 (VDD3P3_RTC), U2.17 (VDD3P3_CPU), U2.18 (VDD_SPI), U2.31 (VDDA), U2.32 (VDDA); also elsewhere on the board
+BATT: Q3.2 (S), R7.1; also elsewhere on the board
ADC: C10.1, R17.2, U2.8 (GPIO3)
ADC_EN: Q4.1 (G), R15.2, U2.12 (MTCK)
CHIP_EN: C14.1, R19.2, U2.7 (CHIP_EN)
EXTI: R1.2, U2.6 (GPIO2)
GND: C1.1, C2.1, C10.2, C14.2, C16.2, C17.2, C18.2, C19.2, C20.1, C21.1, C22.1, C23.2, J1.4, J1.MP, Q4.2 (S), R2.2, R3.2, R11.2, R15.1, SW2.1, U1.A1 (GND), U1.A12 (GND), U1.B1 (GND), U1.B12 (GND), U1.S1 (SHIELD), U2.33 (GND), Y1.2 (GND), Y1.4 (GND); also elsewhere on the board
GPIO8: R6.2, U2.14 (GPIO8)
MCU_SCL: J1.3, R10.1, U2.9 (MTMS)
MCU_SDA: J1.2, R9.1, U2.10 (MTDI)
unnamed: AE1.1 (A_1), C18.1, L3.1
unnamed: J1.1, Q5.3 (D), R9.2, R10.2
unnamed: Q3.3 (D), R13.1
unnamed: Q3.1 (G), Q4.3 (D), R7.2
unnamed: R11.1, R13.2, R17.1
unnamed: R2.1, U1.A5 (CC1)
unnamed: R3.1, U1.B5 (CC2)
unnamed: R8.2, SW2.2, U2.15 (GPIO9)
unnamed: C19.1, L3.2, U2.1 (LNA_IN)
unnamed: C1.2, U2.29 (XTAL_N), Y1.3 (OSC2)
unnamed: C2.2, U2.30 (XTAL_P), Y1.1 (OSC1)
SENSOR_PWR_EN: Q5.1 (G), R18.1, U2.16 (GPIO10)
USB_D+: U1.A6 (D+), U1.B6 (D+), U2.26 (GPIO19)
USB_D-: U1.A7 (D-), U1.B7 (D-), U2.25 (GPIO18)
VCC: U1.A4 (VBUS), U1.A9 (VBUS), U1.B4 (VBUS), U1.B9 (VBUS); also elsewhere on the board

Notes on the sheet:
2,75 V_in = 1,65 V_out
(35 + j10) Ohm
50 Ohm
4,2 V_in = 2,52 V_out

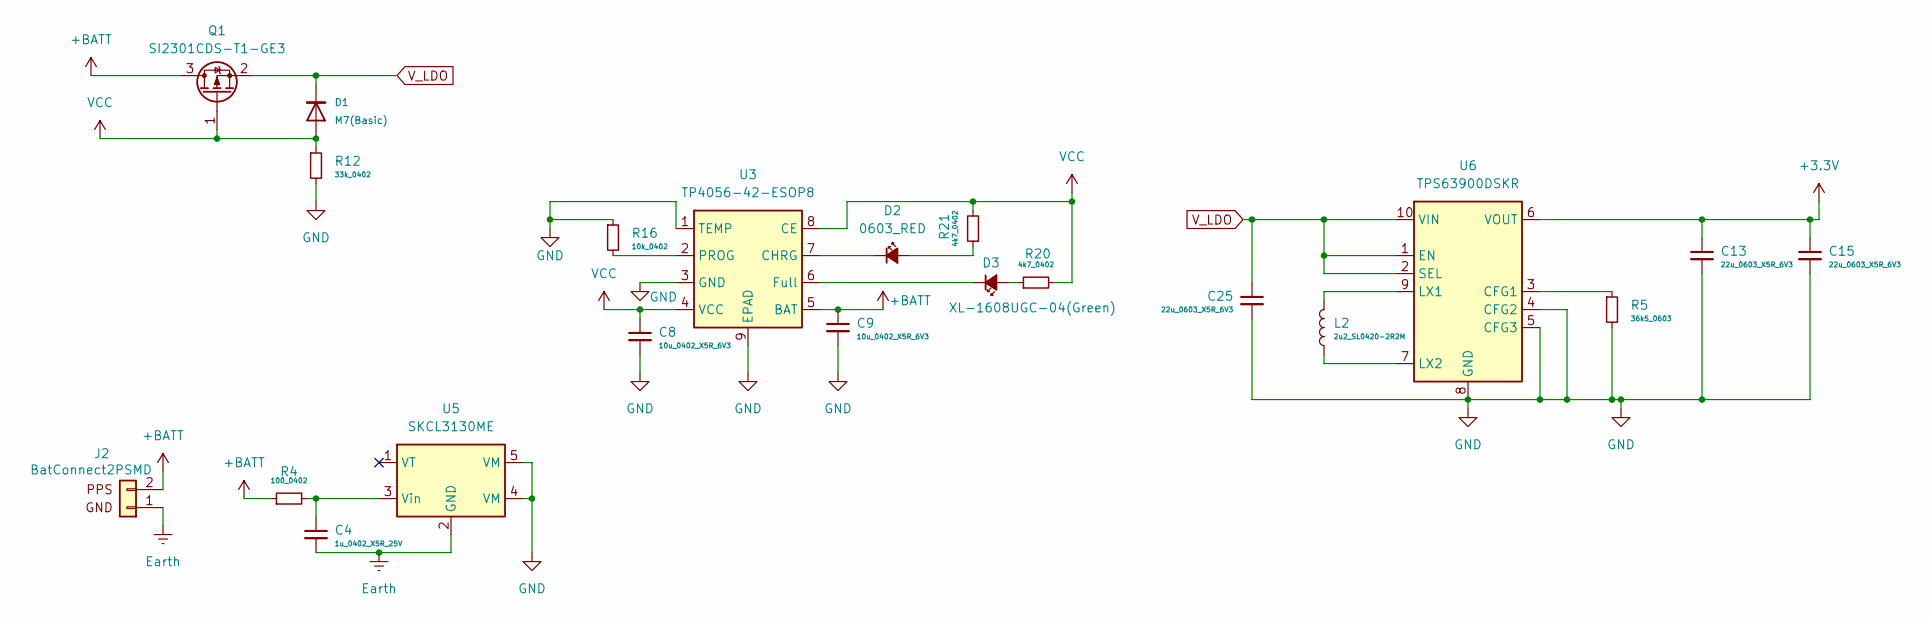
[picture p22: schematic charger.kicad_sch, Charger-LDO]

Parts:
C4: 1u_0402_X5R_25V; C_0402_1005Metric; LCSC C52923
C8, C9: 10u_0402_X5R_6V3; C_0402_1005Metric; LCSC C15525
C13, C15, C25: 22u_0603_X5R_6V3; C_0603_1608Metric; LCSC C59461
D1: M7(Basic); D_SMA; LCSC C95872
D2: 0603_RED; LED_0603_1608Metric; Partnumber KT-0603R; LCSC C2286
D3: XL-1608UGC-04(Green); LED_0603_1608Metric; Partnumber XL-1608UGC-04; LCSC C965804
J2: BatConnect2PSMD; JST_PH_S2B-PH-SM4-TB_1x02-1MP_P2.00mm_Horizontal; LCSC C47647
L2: 2u2_SL0420-2R2M; L_Chilisin_BMRx00040412; LCSC C22463806
Q1: SI2301CDS-T1-GE3; SOT-23; LCSC C10487
R4: 100_0402; R_0402_1005Metric; Voltage 50V; LCSC C25076
R5: 36k5_0603; R_0603_1608Metric; LCSC C23029
R12: 33k_0402; R_0402_1005Metric; Voltage 50V; LCSC C25779
R16: 10k_0402; R_0402_1005Metric; Voltage 50V; LCSC C25744
R20, R21: 4k7_0402; R_0402_1005Metric; Voltage 50V; LCSC C25900
U3: TP4056-42-ESOP8; HTSOP-8-1EP_3.9x4.9mm_P1.27mm_EP2.4x3.2mm_ThermalVias; LCSC C16581
U5: SKCL3130ME; SOT-23-5; LCSC C2941741
U6: TPS63900DSKR; WSON-10-1EP_2.5x2.5mm_P0.5mm_EP1.2x2mm_ThermalVias; LCSC C1518762

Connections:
+3.3V: C13.1, C15.1, U6.6 (VOUT); also elsewhere on the board
+BATT: C9.1, J2.2, Q1.3 (D), R4.1, U3.5 (BAT); also elsewhere on the board
Earth: C4.2, J2.1, U5.2 (GND)
GND: C8.2, C9.2, C13.2, C15.2, C25.2, R5.2, R12.2, R16.1, U3.1 (TEMP), U3.3 (GND), U3.9 (EPAD), U5.4 (VM), U5.5 (VM), U6.4 (CFG2), U6.5 (CFG3), U6.8 (GND), U6.11 (GND); also elsewhere on the board
unnamed: D2.2 (A), R21.1
unnamed: D2.1 (K), U3.7 (CHRG)
unnamed: D3.2 (A), R20.1
unnamed: D3.1 (K), U3.6 (Full)
unnamed: R16.2, U3.2 (PROG)
unnamed: C4.1, R4.2, U5.3 (Vin)
unnamed: R5.1, U6.3 (CFG1)
unnamed: L2.2, U6.9 (LX1)
unnamed: L2.1, U6.7 (LX2)
VCC: C8.1, D1.2 (A), Q1.1 (G), R12.1, R20.2, R21.2, U3.4 (VCC), U3.8 (CE); also elsewhere on the board
V_LDO: C25.1, D1.1 (K), Q1.2 (S), U6.1 (EN), U6.2 (SEL), U6.10 (VIN)

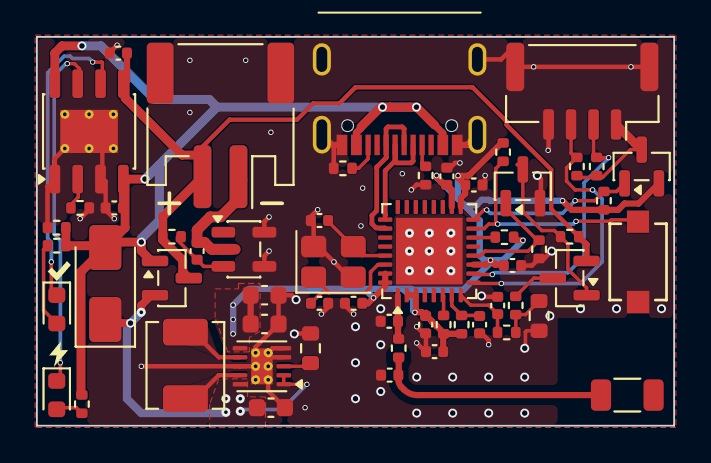
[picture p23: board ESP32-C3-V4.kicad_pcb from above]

Board: 4 copper layers, 35.4 x 21.6 mm, 57 parts (0 on the bottom side), 36 nets.

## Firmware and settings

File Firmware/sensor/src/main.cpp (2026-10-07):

#include <Arduino.h>

#include <esp_random.h>
#include <esp_timer.h>
#include <esp_sleep.h>
#include <driver/gpio.h>

#include "adc_reader.h"
#include "live_acquisition.h"
#include "recording_store.h"
#include "ota_client.h"
#include "environmental_sensor.h"
#include "espnow_transport.h"
#include "hardware_profile.h"
#include "lil_protocol.h"
#include "power_controller.h"
#include "sensor_config_store.h"
#include "sensor_log.h"
#include "sleep_controller.h"
#include "logical_clock.h"
#include "low_power_wait.h"
#include "power_policy.h"
#include "power_options.h"

namespace {
// Discovery is deliberately limited to sensors which have not been added to a
// station yet. Configured nodes only use short recovery wakes for a bounded
// initialization attempt, then resume their energy-saving measurement interval.
// Revision E retains bounded startup recovery across deep sleep.
constexpr uint32_t kRtcSignature = 0x52544345UL;  // "RTCE"
constexpr uint32_t kPairingMeasurementSeconds = 5UL * 60UL;
constexpr uint32_t kInitialSleepPhaseWindowMs = 1000UL;
constexpr uint8_t kRecoveryChannelsPerReport = 3;
constexpr uint8_t kSensorStartAttempts = 3;
constexpr uint32_t kSensorRecoverySleepSeconds = 5;

struct RtcState {
  uint32_t signature;
  uint32_t bootCount;
  uint32_t sequence;
  uint32_t acknowledgedResetRevision;
  int8_t lastStationRssi;
  uint64_t lastReportLogicalMs;
  uint64_t discoveryStartedMs;
  uint64_t pairingMeasurementMs;
  uint16_t initialSleepPhaseMs;
  uint8_t nextRecoveryChannel;
  bool initialSleepPhaseApplied;
  bool fullChannelRecoveryPending;
  sensor::EnvironmentalReading cachedEnvironment;
  sensor::BatteryReading cachedBattery;
  bool hasAttemptedReport;
  bool hasPairingSnapshot;
  bool batteryPaused;
  bool sensorRecoveryPending;
  uint8_t sensorStartAttemptsRemaining;
  lil::protocol::EnvironmentalSensorType lastSensorType;
};

RTC_DATA_ATTR RtcState rtcState{};

sensor::SensorConfigStore configStore;
sensor::SensorRuntimeConfig runtimeConfig;
sensor::PowerController powerController;
sensor::AdcReader adcReader;
sensor::EnvironmentalSensor environmentalSensor;
sensor::EspNowTransport espNowTransport;
bool rtcStateInitializedThisBoot = false;

bool macIsUsable(const uint8_t mac[6]) {
  uint8_t combined = 0;
  for (size_t i = 0; i < 6; ++i) combined |= mac[i];
  return combined != 0;
}

enum class OperatingMode : uint8_t {
  kDiscovery,
  kEnergySaving,
};

constexpr OperatingMode operatingModeForAssignment(
    bool provisioned, bool stationKnown, bool channelValid, bool macValid) {
  return provisioned && stationKnown && channelValid && macValid
             ? OperatingMode::kEnergySaving
             : OperatingMode::kDiscovery;
}

static_assert(operatingModeForAssignment(false, false, true, false) ==
                  OperatingMode::kDiscovery,
              "A fresh sensor must use discovery mode");
static_assert(operatingModeForAssignment(false, true, true, true) ==
                  OperatingMode::kDiscovery,
              "A deleted sensor must use discovery mode");
static_assert(operatingModeForAssignment(true, false, true, true) ==
                  OperatingMode::kDiscovery,
              "An incomplete assignment must use discovery mode");
static_assert(operatingModeForAssignment(true, true, false, true) ==
                  OperatingMode::kDiscovery,
              "An invalid channel must use discovery mode");
static_assert(operatingModeForAssignment(true, true, true, true) ==
                  OperatingMode::kEnergySaving,
              "A complete assignment must use energy-saving mode");

OperatingMode operatingMode(const sensor::SensorRuntimeConfig& config) {
  // Only a complete, persisted station assignment may enable the short radio
  // path. Any incomplete or cleared assignment safely falls back to discovery.
  return operatingModeForAssignment(
      config.provisioned, config.stationKnown,
      config.wifiChannel >= 1 && config.wifiChannel <= 13,
      macIsUsable(config.stationMac));
}

uint64_t logicalNowMs() {
  return sensor::logicalTimeMs();
}

void initializeRtcState() {
  if (rtcState.signature != kRtcSignature) {
    rtcState = RtcState{};
    rtcState.signature = kRtcSignature;
    rtcState.sequence = esp_random();
    rtcState.initialSleepPhaseMs = static_cast<uint16_t>(
        esp_random() % (kInitialSleepPhaseWindowMs + 1UL));
    rtcState.nextRecoveryChannel = 1;
    rtcState.sensorRecoveryPending = true;
    rtcState.sensorStartAttemptsRemaining = kSensorStartAttempts;
    rtcStateInitializedThisBoot = true;
  }
  ++rtcState.bootCount;
  ++rtcState.sequence;
}

uint8_t takeNextRecoveryChannel(uint8_t savedChannel) {
  for (uint8_t checked = 0; checked < 13; ++checked) {
    if (rtcState.nextRecoveryChannel < 1 ||
        rtcState.nextRecoveryChannel > 13) {
      rtcState.nextRecoveryChannel = 1;
    }
    const uint8_t candidate = rtcState.nextRecoveryChannel;
    rtcState.nextRecoveryChannel =
        rtcState.nextRecoveryChannel == 13
            ? 1
            : static_cast<uint8_t>(rtcState.nextRecoveryChannel + 1);
    if (candidate != savedChannel) {
      return candidate;
    }
  }
  return savedChannel;
}

bool applyStationConfig(const lil::protocol::ConfigResponsePayload& response) {
  if ((response.flags & lil::protocol::kFactoryReset) != 0) {
    if (!environmentalSensor.clearIaqState() || !configStore.factoryReset()) {
      SENSOR_LOG_PRINTLN("[CONFIG] Factory reset could not be persisted; retrying on the next report");
      return false;
    }
    rtcState.acknowledgedResetRevision = response.revision;
    rtcState.initialSleepPhaseMs = static_cast<uint16_t>(
        esp_random() % (kInitialSleepPhaseWindowMs + 1UL));
    rtcState.initialSleepPhaseApplied = false;
    rtcState.nextRecoveryChannel = 1;
    rtcState.fullChannelRecoveryPending = false;
    sensor::SleepController::deepSleep(1, powerController);
  }

  const bool iaqResetRequested =
      (response.flags & lil::protocol::kResetIaqCalibration) != 0 &&
      response.revision != runtimeConfig.revision;

  const bool sensorTypeValid =
      response.sensorType ==
          lil::protocol::EnvironmentalSensorType::kAutoDetect ||
      response.sensorType == lil::protocol::EnvironmentalSensorType::kBme280 ||
      response.sensorType == lil::protocol::EnvironmentalSensorType::kLsm6dsox ||
      response.sensorType == lil::protocol::EnvironmentalSensorType::kTmp117 ||
      response.sensorType == lil::protocol::EnvironmentalSensorType::kMax30102 ||
      response.sensorType == lil::protocol::EnvironmentalSensorType::kBme680 ||
      response.sensorType ==
          lil::protocol::EnvironmentalSensorType::kDisabled;
  if (response.sleepIntervalSeconds >= 1 &&
      response.sleepIntervalSeconds <= 86400 && response.wifiChannel >= 1 &&
      response.wifiChannel <= 13 && macIsUsable(response.stationMac) &&
      sensorTypeValid && isfinite(response.temperatureOffsetC) &&
      response.temperatureOffsetC >= -10.0F &&
      response.temperatureOffsetC <= 10.0F &&
      isfinite(response.batteryCalibrationFactor) &&
      response.batteryCalibrationFactor >= 0.7F &&
      response.batteryCalibrationFactor <= 1.3F) {
    const bool sensorTypeChanged =
        runtimeConfig.environmentalSensorType != response.sensorType;
    const bool provisioningChanged =
        runtimeConfig.provisioned != (response.provisioned != 0);
    const bool measurementChanged = sensorTypeChanged || provisioningChanged ||
        runtimeConfig.sleepSeconds != response.sleepIntervalSeconds ||
        runtimeConfig.temperatureOffsetC != response.temperatureOffsetC;
    const bool newProvisioned = response.provisioned != 0;
    auto candidate = runtimeConfig;
    candidate.revision = response.revision;
    candidate.sleepSeconds = response.sleepIntervalSeconds;
    candidate.wifiChannel = response.wifiChannel;
    candidate.txPowerQuarterDbm = constrain(response.txPowerQuarterDbm, 8, 84);
    candidate.environmentalSensorType = response.sensorType;
    candidate.temperatureOffsetC = response.temperatureOffsetC;
    candidate.batteryCalibrationFactor = response.batteryCalibrationFactor;
    candidate.provisioned = newProvisioned;
    candidate.stationKnown = newProvisioned;
    candidate.bme680QuickStartComplete = true;
    if (newProvisioned) memcpy(candidate.stationMac, response.stationMac, 6);
    else memset(candidate.stationMac, 0, sizeof(candidate.stationMac));
    // Reset commands must finish durably before their revision can be ACKed,
    // including after reboot. A later config-write failure may repeat the reset,
    // but can never advertise an unsuccessful reset as completed.
    if ((iaqResetRequested || sensorTypeChanged || provisioningChanged) &&
        !environmentalSensor.clearIaqState()) {
      SENSOR_LOG_PRINTLN("[CONFIG] IAQ state could not be cleared; keeping the previous revision");
      return false;
    }
    // A telemetry revision acknowledges durable settings. Keep the previous
    // revision when NVS fails so the station retries the command.
    if (!configStore.saveIfChanged(candidate)) {
      SENSOR_LOG_PRINTLN("[CONFIG] Settings could not be persisted; keeping the previous revision");
      return false;
    }
    if (!newProvisioned) {
      rtcState.fullChannelRecoveryPending = false;
      rtcState.nextRecoveryChannel = 1;
    } else if (provisioningChanged) {
      rtcState.fullChannelRecoveryPending = true;
      rtcState.nextRecoveryChannel = 1;
    }
    if (newProvisioned &&
        (response.flags & lil::protocol::kStationChannelStable) != 0) {
      rtcState.fullChannelRecoveryPending = false;
    }
    // Compatibility field in the persisted V6 layout. ULP-only operation has
    // no separate quick-start phase.
    runtimeConfig = candidate;
    if (measurementChanged) {
      rtcState.hasPairingSnapshot = false;
      rtcState.cachedEnvironment = {};
      rtcState.sensorRecoveryPending = true;
      rtcState.sensorStartAttemptsRemaining = kSensorStartAttempts;
      if (sensorTypeChanged) rtcState.lastSensorType = lil::protocol::EnvironmentalSensorType::kAutoDetect;
    }
    if (rtcState.acknowledgedResetRevision == response.revision) {
      rtcState.acknowledgedResetRevision = 0;
    }
    return measurementChanged;
  }
  return false;
}

void updatePacketBattery(lil::protocol::TelemetryPacket& packet,
                         const sensor::BatteryReading& battery) {
  packet.payload.batteryMillivolts = battery.millivolts;
  packet.payload.capabilities &= ~lil::protocol::kBattery;
  packet.payload.flags &= ~lil::protocol::kBatteryReadFailed;
  if (battery.valid) packet.payload.capabilities |= lil::protocol::kBattery;
  else packet.payload.flags |= lil::protocol::kBatteryReadFailed;
}

lil::protocol::TelemetryPacket makeTelemetryPacket(
    const sensor::EnvironmentalReading& environment,
    const sensor::BatteryReading& battery,
    lil::protocol::SensorOperatingMode operatingMode) {
  lil::protocol::TelemetryPacket packet{};
  packet.payload.appliedConfigRevision =
      rtcState.acknowledgedResetRevision != 0
          ? rtcState.acknowledgedResetRevision
          : runtimeConfig.revision;
  packet.payload.bootCount = rtcState.bootCount;
  packet.payload.capabilities = environment.capabilities |
                                (battery.valid ? lil::protocol::kBattery : 0);
  if (sensor::kHardware.pcbVersion == 4) {
    packet.payload.capabilities |= lil::protocol::kPcbV4PowerGates;
  }
  if (!environment.valid) {
    packet.payload.flags |= lil::protocol::kSensorReadFailed;
  }
  if (!battery.valid) {
    packet.payload.flags |= lil::protocol::kBatteryReadFailed;
  }
  packet.payload.motion = environment.motion;
  packet.payload.motionFeedback = environment.motionFeedback;
  packet.payload.pulse = environment.pulse;
  packet.payload.live = environment.live;
  packet.payload.temperatureC = environment.temperatureC;
  packet.payload.humidityPercent = environment.humidityPercent;
  packet.payload.pressureHpa = environment.pressureHpa;
  packet.payload.iaq = environment.iaq;
  packet.payload.gasResistanceOhms = environment.gasResistanceOhms;
  packet.payload.batteryMillivolts = battery.millivolts;
  packet.payload.pcbVersion = sensor::kHardware.pcbVersion;
  packet.payload.operatingMode = operatingMode;
  packet.payload.lastStationRssi = rtcState.lastStationRssi;
  packet.payload.sensorType = environment.sensorType;
  packet.payload.iaqAccuracy = environment.iaqAccuracy;
  packet.payload.iaqCalibrationPhase = environment.iaqCalibrationPhase;
  packet.payload.iaqCalibrationElapsedMinutes =
      environment.iaqCalibrationElapsedMinutes;
  packet.payload.iaqCalibrationRemainingMinutes =
      environment.iaqCalibrationRemainingMinutes;
  if (operatingMode == lil::protocol::SensorOperatingMode::kDiscovery) {
    packet.payload.flags |= lil::protocol::kDiscoveryBeacon;
  }
  if (environment.bme680RawFallback && environment.valid) {
    packet.payload.flags |= lil::protocol::kBme680RawFallback;
  }
  if ((environment.capabilities & lil::protocol::kIaq) != 0 &&
      environment.iaqAccuracy < 1) {
    packet.payload.flags |= lil::protocol::kIaqCalibrating;
  }
  if (runtimeConfig.environmentalSensorType !=
          lil::protocol::EnvironmentalSensorType::kAutoDetect &&
      runtimeConfig.environmentalSensorType !=
          lil::protocol::EnvironmentalSensorType::kDisabled &&
      environment.sensorType != lil::protocol::EnvironmentalSensorType::kAutoDetect &&
      environment.sensorType != runtimeConfig.environmentalSensorType) {
    packet.payload.flags |= lil::protocol::kSensorTypeMismatch;
  }
  lil::protocol::finalize(packet, lil::protocol::MessageType::kTelemetry,
                          rtcState.sequence);
  return packet;
}

bool batteryProtectionRequired(const sensor::BatteryReading& battery) {
  return lil::power::batteryProtectionRequired(rtcState.batteryPaused,
      battery.valid, battery.millivolts, SENSOR_LOW_BATTERY_PAUSE_MV,
      SENSOR_LOW_BATTERY_RESUME_MARGIN_MV);
}

[[noreturn]] void reportBatteryAndSleep(const sensor::BatteryReading& battery) {
  rtcState.batteryPaused = true;
  rtcState.hasPairingSnapshot = false;
  powerController.prepareForDeepSleep();
  // No sensor initialization, cached measurements, OTA download, channel scan
  // or configuration command may turn this into a normal measurement wake.
  sensor::EnvironmentalReading suppressed{};
  suppressed.valid = true;
  suppressed.sensorType = runtimeConfig.environmentalSensorType ==
      lil::protocol::EnvironmentalSensorType::kAutoDetect ?
      rtcState.lastSensorType : runtimeConfig.environmentalSensorType;
  ++rtcState.sequence;
  auto packet = makeTelemetryPacket(suppressed, battery,
      lil::protocol::SensorOperatingMode::kBatteryProtection);
  packet.payload.flags |= lil::protocol::kBatteryProtectionActive;
  lil::protocol::finalize(packet, lil::protocol::MessageType::kTelemetry,
                         rtcState.sequence);
  if (operatingMode(runtimeConfig) == OperatingMode::kEnergySaving &&
      espNowTransport.begin()) {
    // One bounded reporting window on the saved channel, even if the station
    // is offline. A failed delivery must not trigger an early retry wake.
    const auto exchange = espNowTransport.exchangeLpChannel(
        packet, runtimeConfig, runtimeConfig.wifiChannel);
    if (exchange.configReceived) {
      rtcState.lastStationRssi = exchange.stationRssi;
      sensor::confirmOtaBootAfterContact();
    }
    espNowTransport.end();
  }
  rtcState.lastReportLogicalMs = logicalNowMs();
  rtcState.hasAttemptedReport = true;
  SENSOR_LOG_PRINTLN("[POWER] Battery protection: sensors off, next report in 24 hours");
  sensor::finishOtaBootGuard();
  sensor::SleepController::deepSleep(kBatteryProtectionSleepSeconds, powerController);
}
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
void loop() {}

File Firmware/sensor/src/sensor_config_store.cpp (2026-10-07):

#include "sensor_config_store.h"

#include <esp_app_desc.h>
#include <esp_attr.h>
#include <string.h>

namespace sensor {

namespace {
constexpr char kNamespace[] = "lil_sensor";
constexpr char kConfigKey[] = "config";
constexpr char kFirmwareKey[] = "fw_sha";
constexpr uint32_t kMinSleepSeconds = 1;
constexpr uint32_t kMaxSleepSeconds = 86400;
constexpr uint32_t kRtcConfigSignature = 0x43464738UL;  // "CFG8"

struct RtcConfigCache {
  uint32_t signature = 0;
  uint8_t firmwareSha[32]{};
  SensorRuntimeConfig config{};
  bool persisted = false;
};

RTC_DATA_ATTR RtcConfigCache rtcConfigCache{};

struct LegacySensorRuntimeConfigV1 {
  uint32_t magic = kSensorConfigMagic;
  uint16_t version = 1;
  uint32_t revision = 0;
  uint32_t sleepSeconds = 600;
  uint8_t stationMac[6]{};
  uint8_t wifiChannel = 1;
  int8_t txPowerQuarterDbm = 52;
  bool stationKnown = false;
};

struct LegacySensorRuntimeConfigV2 {
  uint32_t magic = kSensorConfigMagic;
  uint16_t version = 2;
  uint32_t revision = 0;
  uint32_t sleepSeconds = 600;
  uint8_t stationMac[6]{};
  uint8_t wifiChannel = 1;
  int8_t txPowerQuarterDbm = 52;
  bool stationKnown = false;
  lil::protocol::EnvironmentalSensorType environmentalSensorType =
      lil::protocol::EnvironmentalSensorType::kAutoDetect;
  float temperatureOffsetC = 0.466F;
};

struct LegacySensorRuntimeConfigV3 {
  uint32_t magic = kSensorConfigMagic;
  uint16_t version = 3;
  uint32_t revision = 0;
  uint32_t sleepSeconds = 600;
  uint8_t stationMac[6]{};
  uint8_t wifiChannel = 1;
  int8_t txPowerQuarterDbm = 52;
  bool stationKnown = false;
  lil::protocol::EnvironmentalSensorType environmentalSensorType =
      lil::protocol::EnvironmentalSensorType::kAutoDetect;
  float temperatureOffsetC = 0.466F;
  float batteryCalibrationFactor = 1.0F;
};

struct LegacySensorRuntimeConfigV4 {
  uint32_t magic = kSensorConfigMagic;
  uint16_t version = 4;
  uint32_t revision = 0;
  uint32_t sleepSeconds = 600;
  uint8_t stationMac[6]{};
  uint8_t wifiChannel = 1;
  int8_t txPowerQuarterDbm = 52;
  bool stationKnown = false;
  bool provisioned = false;
  lil::protocol::EnvironmentalSensorType environmentalSensorType =
      lil::protocol::EnvironmentalSensorType::kAutoDetect;
  float temperatureOffsetC = 0.466F;
  float batteryCalibrationFactor = 1.0F;
};

struct LegacySensorRuntimeConfigV5 {
  uint32_t magic = kSensorConfigMagic;
  uint16_t version = 5;
  uint32_t revision = 0;
  uint32_t sleepSeconds = 600;
  uint8_t stationMac[6]{};
  uint8_t wifiChannel = 1;
  int8_t txPowerQuarterDbm = 52;
  bool stationKnown = false;
  bool provisioned = false;
  bool bme680QuickStartComplete = false;
  lil::protocol::EnvironmentalSensorType environmentalSensorType =
      lil::protocol::EnvironmentalSensorType::kAutoDetect;
  float temperatureOffsetC = 0.466F;
  float batteryCalibrationFactor = 1.0F;
};

static_assert(sizeof(LegacySensorRuntimeConfigV5) ==
                  sizeof(SensorRuntimeConfig),
              "V5 migration must preserve the persisted binary layout");

template <typename Legacy>
void migrateRuntimeConfig(const Legacy& legacy, SensorRuntimeConfig& config) {
  config = SensorRuntimeConfig{};
  config.revision = legacy.revision;
  config.sleepSeconds = legacy.sleepSeconds;
  memcpy(config.stationMac, legacy.stationMac, sizeof(config.stationMac));
  config.wifiChannel = legacy.wifiChannel;
  config.txPowerQuarterDbm = legacy.txPowerQuarterDbm;
  config.stationKnown = legacy.stationKnown;
}

bool validSensorType(lil::protocol::EnvironmentalSensorType type) {
  return type == lil::protocol::EnvironmentalSensorType::kAutoDetect ||
         type == lil::protocol::EnvironmentalSensorType::kBme280 ||
      type == lil::protocol::EnvironmentalSensorType::kLsm6dsox ||
      type == lil::protocol::EnvironmentalSensorType::kTmp117 ||
      type == lil::protocol::EnvironmentalSensorType::kMax30102 ||
         type == lil::protocol::EnvironmentalSensorType::kBme680 ||
         type == lil::protocol::EnvironmentalSensorType::kDisabled;
}

bool validRuntimeConfig(const SensorRuntimeConfig& config) {
  return config.magic == kSensorConfigMagic &&
         config.version == kSensorConfigVersion &&
         config.sleepSeconds >= kMinSleepSeconds &&
         config.sleepSeconds <= kMaxSleepSeconds && config.wifiChannel >= 1 &&
         config.wifiChannel <= 13 &&
         validSensorType(config.environmentalSensorType) &&
         isfinite(config.temperatureOffsetC) &&
         config.temperatureOffsetC >= -10.0F &&
         config.temperatureOffsetC <= 10.0F &&
         isfinite(config.batteryCalibrationFactor) &&
         config.batteryCalibrationFactor >= 0.7F &&
         config.batteryCalibrationFactor <= 1.3F;
}
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

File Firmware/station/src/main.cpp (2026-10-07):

#include <Arduino.h>
#include <time.h>

#include "app_config.h"
#include "ota_service.h"
#include "config_store.h"
#include "espnow_gateway.h"
#include "sensor_registry.h"
#include "thingspeak_service.h"
#include "web_portal.h"
#include "wifi_service.h"

namespace {
station::ConfigStore configStore;
station::StationConfig stationConfig;
station::WifiService wifiService;
station::SensorRegistry sensorRegistry;
station::ThingSpeakService thingSpeakService;
station::EspNowGateway espNowGateway;
station::WebPortal webPortal;

[[noreturn]] void fatal(const char* message) {
  Serial.printf("[FATAL] %s\n", message);
  for (;;) {
    delay(1000);
  }
}
}  // namespace

void setup() {
  Serial.begin(115200);
  const uint32_t serialStarted = millis();
  while (!Serial && millis() - serialStarted < 2000) {
    delay(10);
  }

  Serial.println();
  Serial.println("========================================");
  Serial.printf("W-Charger Station firmware %s\n", lil::ota::kVersion);
  Serial.println("========================================");

  if (!configStore.begin()) {
    fatal("NVS configuration storage could not be opened");
  }
  stationConfig = configStore.loadStationConfig();

  if (!sensorRegistry.begin(configStore,
                            stationConfig.defaultSleepSeconds)) {
    fatal("Sensor registry could not be initialized");
  }
  if (!wifiService.begin(stationConfig)) {
    fatal("Wi-Fi could not be started");
  }
  // History buckets use UTC Unix timestamps. SNTP keeps running across Wi-Fi
  // reconnects; no browser has to remain open for the station to timestamp
  // and retain measurements.
  configTime(0, 0, "pool.ntp.org", "time.nist.gov");
  if (!thingSpeakService.begin(sensorRegistry)) {
    fatal("ThingSpeak task could not be started");
  }
  if (!station::otaService.begin()) {
    Serial.println("[WARN] OTA staging unavailable; install the new partition layout by USB");
  }
  if (!espNowGateway.begin(sensorRegistry, thingSpeakService, wifiService)) {
    fatal("ESP-NOW gateway could not be started");
  }
  if (!webPortal.begin(stationConfig, configStore, wifiService, sensorRegistry,
                       thingSpeakService, espNowGateway)) {
    fatal("Web interface could not be started");
  }

  if (wifiService.setupPortalActive()) {
    Serial.printf("Setup Wi-Fi active: %s\n",
                  wifiService.accessPointSsid().c_str());
    Serial.println("Setup-Passwort: im lokalen Webinterface sichtbar");
    Serial.printf("Setup-Adresse: http://%s/\n",
                  wifiService.accessPointIp().c_str());
    Serial.println("Setup through the captive portal does not require a web login.");
  } else {
    Serial.println("Setup Wi-Fi disabled (home Wi-Fi is already configured).");
    Serial.println("Waiting for home Wi-Fi. If unavailable, recovery access starts automatically after 30 seconds.");
  }
}

void loop() {
  wifiService.loop();
  if (wifiService.consumeSetupPortalCompletion()) {
    stationConfig.setupPortalRequired = false;
    if (!configStore.saveStationConfig(stationConfig)) {
      Serial.println("[WARN] Setup portal state could not be saved");
    } else {
      Serial.println("Home Wi-Fi connected; setup Wi-Fi was disabled.");
    }
  }
  webPortal.loop();
  delay(2);
}

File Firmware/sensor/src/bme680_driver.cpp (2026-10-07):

#include "bme680_driver.h"

#include <esp_attr.h>
#include <esp_timer.h>
#include <string.h>

#include "low_power_wait.h"
#include "sensor_log.h"
#include "measurement_budget.h"
#include "logical_clock.h"
#include "power_policy.h"

namespace sensor {

namespace {
// Revision 8 invalidates RTC data learned by the former LP/ULP switching
// routine. It complements the NVS format bump in bsec_state_store.cpp.
constexpr uint32_t kRtcSignature = 0x42525439UL;  // "BRT9"
// Bosch's examples persist the adaptive BSEC state periodically. Every sample
// remains in RTC memory; NVS is only updated on an accuracy improvement or
// after six hours.
constexpr uint64_t kNvsSaveIntervalMs = 6ULL * 60ULL * 60ULL * 1000ULL;
constexpr uint32_t kUlpStabilizationSeconds = 20UL * 60UL;
constexpr uint16_t kRawHeaterTemperatureC = 320;
constexpr uint16_t kRawHeaterDurationMs = 150;
constexpr uint32_t kRawMeasurementMarginUs = 10000;
// A power-cycled BME680 has no previous field which BSEC can consume.  Keep
// the rail on for one bounded acquisition window and require a genuinely new
// BSEC output before falling back to the direct Bosch API.  The five-second
// ceiling covers the BME680's maximum 4032-ms gas wait plus T/P/H conversion,
// I2C and scheduling margin without ever keeping the node awake for 300 s.
constexpr uint32_t kBsecOutputTimeoutMs = 5000;
constexpr uint32_t kBsecOutputPollMs = 10;

// The BME680 stays in ULP mode for its complete service life. Bosch advises
// against changing between LP and ULP because their adaptive gas baselines are
// not interchangeable. The board powers the sensor from 3.3 V, so use only the
// matching energy-efficient 300-second configuration.
const uint8_t kBsecConfigUlp33v[] = {
#include "config/bme680/bme680_iaq_33v_300s_4d/bsec_iaq.txt"
};
static_assert(sizeof(kBsecConfigUlp33v) == BSEC_MAX_PROPERTY_BLOB_SIZE,
              "Unexpected Bosch ULP configuration size");

struct BsecRtcState {
  uint32_t signature = 0;
  uint8_t state[BSEC_MAX_STATE_BLOB_SIZE]{};
  uint8_t lastSavedAccuracy = 0;
  uint64_t lastNvsSaveLogicalMs = 0;
  bool stateValid = false;
  uint32_t calibrationElapsedSeconds = 0;
  bool calibrationReady = false;
  bool stabilizationStatusSeen = false;
  bool stabilizationFinished = false;
  bool runInStatusSeen = false;
  bool runInFinished = false;
  bool bsecOutputTimestampSeen = false;
  int64_t lastBsecOutputTimestampNs = 0;
  float lastValidIaq = 0.0F;
  uint8_t lastValidIaqAccuracy = 0;
  bool lastValidIaqSeen = false;
  uint64_t nextBsecCallLogicalMs = 0;
  // Diagnostic only. BSEC must still be attempted on every ULP wake: skipping
  // calls stops IAQ learning and can keep accuracy at zero indefinitely.
};

RTC_DATA_ATTR BsecRtcState rtcBsecState{};
bool clockOverride = false;
uint32_t clockOverrideValue = 0;

uint64_t bootElapsedMs() {
  return static_cast<uint64_t>(esp_timer_get_time()) / 1000ULL;
}

unsigned long bsecLogicalMillis() {
  if (clockOverride) {
    return clockOverrideValue;
  }
  return static_cast<uint32_t>(sensor::logicalTimeMs());
}

bool validReading(float value) {
  return isfinite(value);
}

bool inRange(float value, float minimum, float maximum) {
  return validReading(value) && value >= minimum && value <= maximum;
}

uint64_t logicalNowMs() {
  return sensor::logicalTimeMs();
}
}  // namespace

bool Bme680Driver::ensureStateStore() {
  if (!stateStoreReady_) {
    stateStoreReady_ = stateStore_.begin();
  }
  return stateStoreReady_;
}

bool Bme680Driver::begin(uint8_t address, float temperatureOffsetC) {
  rawReady_ = false;
  bsecReady_ = false;
  scheduleUpdated_ = false;
  address_ = address;
  temperatureOffsetC_ = constrain(temperatureOffsetC, -10.0F, 10.0F);
  if (rtcBsecState.signature != kRtcSignature) {
    rtcBsecState = BsecRtcState{};
    rtcBsecState.signature = kRtcSignature;
    if (ensureStateStore()) {
      rtcBsecState.stateValid =
          stateStore_.load(rtcBsecState.state, sizeof(rtcBsecState.state));
      // Calibration metadata cannot establish a learned baseline on its own.
      // A missing/corrupt state blob must restart calibration honestly.
      if (rtcBsecState.stateValid) {
        stateStore_.loadCalibration(rtcBsecState.calibrationElapsedSeconds,
                                    rtcBsecState.calibrationReady);
      }
    }
    rtcBsecState.lastNvsSaveLogicalMs = logicalNowMs();
  }
  calibrationAwakeStartedMs_ = bootElapsedMs();
  calibrationElapsedAtBeginSeconds_ =
      rtcBsecState.calibrationElapsedSeconds;

  SENSOR_LOG_PRINTF("[BME680] Chip ID 0x61 detected at address 0x%02X\n",
                    address);

  // Run BSEC on every ULP wake to preserve IAQ learning. Initialize the raw
  // Bosch fallback only when this path fails, avoiding a second sensor reset.
  // beginCommon() resets BSEC configuration but does not reset the wrapper's
  // millis overflow counter. Repeated initialization must seed it only once.
  bsec_ = Bsec2{};
  bsec_.allocateMemory(bsecMemory_);
  bsecReady_ = tryAddress(address);
  if (bsecReady_) {
    seedClockOverflowCounter();
    const bool configApplied = bsec_.setConfig(kBsecConfigUlp33v);
    if (!configApplied || bsec_.status < BSEC_OK) {
      SENSOR_LOG_PRINTF("[BME680] BSEC configuration failed: %d\n",
                        static_cast<int>(bsec_.status));
      bsecReady_ = false;
    }
  }
  if (bsecReady_) {
    bsec_.setTemperatureOffset(temperatureOffsetC_);
    restoreState();

    bsecSensor outputs[] = {
        BSEC_OUTPUT_SENSOR_HEAT_COMPENSATED_TEMPERATURE,
        BSEC_OUTPUT_SENSOR_HEAT_COMPENSATED_HUMIDITY,
        BSEC_OUTPUT_RAW_PRESSURE,
        BSEC_OUTPUT_RAW_GAS,
        BSEC_OUTPUT_STATIC_IAQ,
        BSEC_OUTPUT_STABILIZATION_STATUS,
        BSEC_OUTPUT_RUN_IN_STATUS,
    };
    bsecReady_ = bsec_.updateSubscription(
        outputs, ARRAY_LEN(outputs), BSEC_SAMPLE_RATE_ULP);
    if (!bsecReady_) {
      SENSOR_LOG_PRINTF("[BME680] BSEC subscription failed: %d\n",
                        static_cast<int>(bsec_.status));
    }
  }
  if (bsecReady_) {
    SENSOR_LOG_PRINTF(
        "[BME680] BSEC %u.%u.%u.%u ready (%s, 3.3 V profile)\n",
        bsec_.version.major, bsec_.version.minor,
        bsec_.version.major_bugfix, bsec_.version.minor_bugfix, "ULP/300 s");
  } else {
    SENSOR_LOG_PRINTLN("[BME680] Direct forced-mode fallback active");
  }
  // Initialize the fallback only if BSEC initialization failed. A successful
  // BSEC cycle already owns a fully initialized physical sensor.
  return bsecReady_ || (!measurementBudgetExpired() && beginRaw(address_));
}
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

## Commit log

2025-10-22 Initial commit: ESP32-C3 IoT Sensor Board
    Complete project including:
    - PCB designs (KiCad) for 3 hardware versions
    - Firmware for wireless sensor nodes
    - ESP32-S3 home station with ESP-NOW receiver
    - ThingSpeak cloud integration
    - Battery management and power optimization
    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
    [ESP32-C3-CmtUser.gbr, ESP32-C3-CuBottom.gbl, ESP32-C3-CuTop.gtl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]
2026-08-07 Add Version 4 low-power sensor board schematic
    - Add TPS63900 buck-boost converter for regulated 3.3 V operation
    - Add MCU-controlled battery voltage divider to eliminate continuous battery drain
    - Reduce battery charging status LED brightness and current consumption
    - Add switchable I2C sensor supply including the SDA and SCL pull-up resistors
    - Reduce the button footprint for a more compact board layout
    [ESP32-C3-V3.gbrjob, ESP32-C3-V4-CmtUser.gbr, ESP32-C3-V4-CuBottom.gbl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]
2026-08-28 Update Version 4 PCB and production outputs
    [ESP32-C3-V3.gbrjob, ESP32-C3-V4-CmtUser.gbr, ESP32-C3-V4-CuBottom.gbl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]
2026-08-30 Update firmware, hardware documentation, and public README
    [ESP32-C3-V2.kicad_pcb, ESP32-C3-V3.kicad_pcb, ESP32-C3-V4.kicad_pcb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]
2026-08-30 Fix ESP32-C3 deep-sleep GPIO power draw
    [power_controller.cpp]
2026-08-31 Improve sensor power modes and station visibility
2026-09-03 Fix PCB V4 battery measurement timing
    [adc_reader.cpp]
2026-09-07 Release firmware 4.1.3 with motion sensing and resilient OTA updates
    [partitions_ota.csv]
2026-09-26 Add precision sensor recordings, accuracy fixes and V4 battery protection
    [partitions_ota.csv, partitions_recording.csv]
2026-10-07 Fix sensor and station reliability and publish firmware 4.3.4
    Inventory the changes since firmware 4.3.1 and merged PR #30 in
    Firmware/CHANGELOG.md, including the intermediate 4.3.2/4.3.3 fixes.
    Main improvements:
    - Retry sensor replacement and scan both Bosch addresses while preserving
    low-power cadence and V4 battery-protection deep sleep.
    - Recover weak MAX30102 signals with independent LED gains and fresh FIFO
    windows while retaining manual SW2 recording semantics.
    - Load saved recordings completely once and retain readable graphs/cursors
    during background status polling.
    - Persist sensor/station settings before acknowledgements and preserve
    nonblank storage failures, identities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
    [bme680_driver.cpp, bme680_driver.h, environmental_sensor.cpp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]
2026-11-06 Improve firmware reliability and publish sensor OTA 4.4.3
2026-11-09 Optimize station and sensor firmware for 4.4.5
    Improve ESP-NOW delivery, acquisition, history and recording handling, dashboard streaming, and cloud scheduling. Add regression coverage and document the verified 4.4.5 source and available release 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

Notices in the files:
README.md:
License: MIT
